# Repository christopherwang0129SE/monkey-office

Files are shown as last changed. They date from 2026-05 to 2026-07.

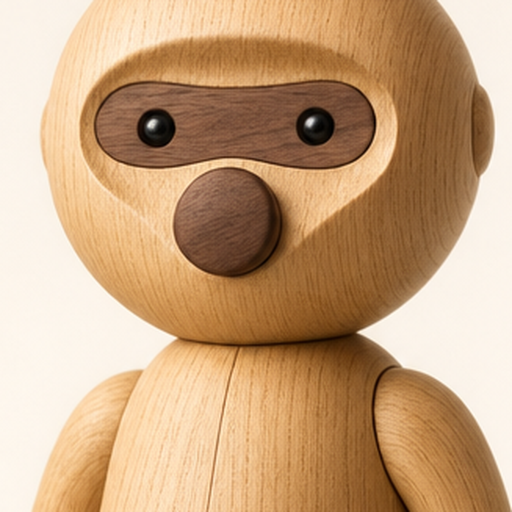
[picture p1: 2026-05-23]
3d Model officemonkey.dk/design/renders/website-assets/monkey-chat.png

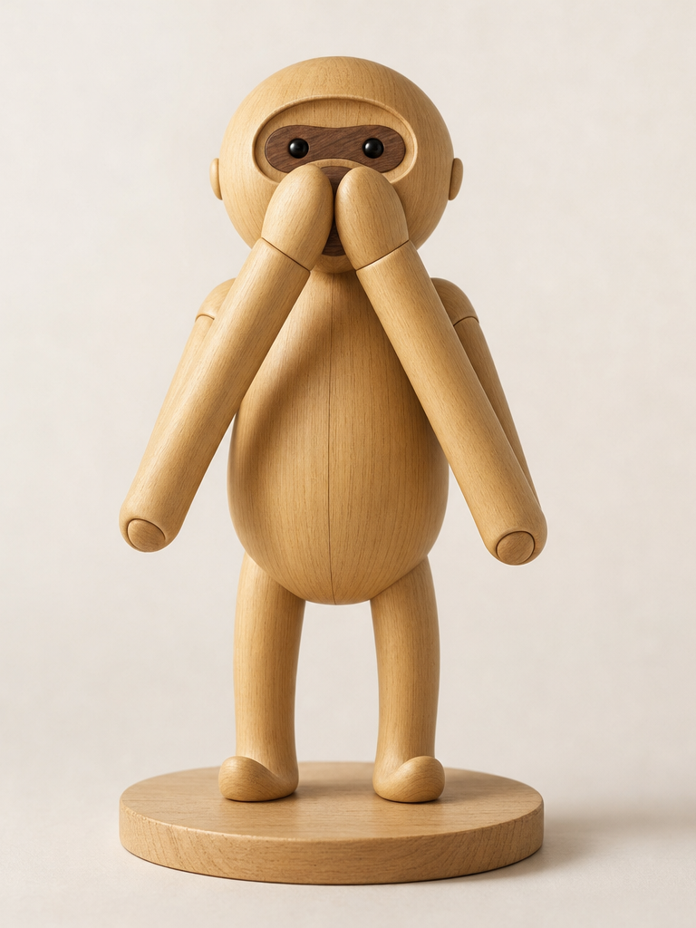
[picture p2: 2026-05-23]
3d Model officemonkey.dk/design/renders/website-assets/monkey-hero.png

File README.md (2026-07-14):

# OfficeMonkey 🙈 🙉 🙊

> A 3D-printed desk monkey that listens to the room and reacts when the office gets too loud — so no one has to be the person who shushes everyone.

**Danish name:** *Tys aben* ("Hush the monkey")

🌐 [Website](https://www.officemonkey.dk) &nbsp;·&nbsp; 🎨 [Lovable project](https://lovable.dev/projects/6d5c936e-dc8c-4e85-afaa-a0ec67a89f7e) &nbsp;·&nbsp; 📄 [Product plan](./Mokey-product-plan.md)

Built by a team of five at **The Boring Hackathon 2026** — a Copenhagen hackathon organised by [Milo.AI](https://milo.ai) and [Iværksætter Netværk Denmark](https://www.facebook.com/groups/ivaerksaetternetvaerk).

---

## What it is

OfficeMonkey is a small, 3D-printed monkey that sits on a desk or shelf in an open office. Inside is an ESP32 with a digital microphone that continuously measures ambient sound level. When the noise crosses a threshold (sustained chatter, a loud meeting bleeding into the open floor), the monkey reacts — gently signalling "it's a bit loud in here" without anyone having to say it out loud.

## How it works

1. An I2S MEMS microphone (INMP441 or SPH0645) samples ambient audio.
2. The ESP32 computes a short-window RMS → smoothed dB-ish value.
3. If the level stays above a configurable threshold for a configurable duration, the monkey triggers a reaction (LEDs, sound, or servo movement — see [Roadmap](#roadmap)).
4. A cooldown period prevents re-triggering on every noise spike.

Threshold, dwell time, and cooldown are hard-coded in V1 and configurable via a small WiFi-served page in V1.1.

## The hackathon build

The Boring Hackathon 2026 gave us a fixed sprint to go from idea to something tangible. In that window we:

- Scoped the product, hardware, and V1 roadmap.
- Designed a parametric enclosure in OpenSCAD and 3D-printed a working miniature prototype.
- Built [officemonkey.dk](https://www.officemonkey.dk) as the product site, using Lovable for rapid iteration.
- Delivered a live demo and pitch at the end of the day.
- Posted a launch listing to the Iværksætter Netværk Denmark community as a first go-to-market signal.

## Repository structure

```
.
├── 3d Model officemonkey.dk/     Marketing 3D model for the website
├── Tys-aben-Print-Package/       Ready-to-print bundle of the enclosure
├── cad/                          OpenSCAD source for the enclosure
├── prints/                       Reference/finished print files
├── stl/                          Exported STL files for printing
├── Mokey-product-plan.md         V1 product plan and scope
├── PRINT.md                      Printing instructions
├── Research.md                   Background research
├── design-v1.md                  V1 design notes
├── design-critique.md            Design critique notes
└── three-wise-monkeys-website-inspiration.md
```

> Note: `Mokey-product-plan.md` has a typo in the filename (should be `Monkey-`). Worth fixing on a rename PR.

## Hardware — bill of materials

Target BOM: **under $25** per unit.

| Part | Notes | Approx cost |
| --- | --- | --- |
| ESP32 dev board (ESP32-S3 recommended) | Built-in WiFi/BT, I2S mic support, USB-C | ~$5–10 |
| I2S MEMS microphone (INMP441 or SPH0645) | Digital mic, cleaner than analog for noise-level work | ~$3 |
| Reaction output (LEDs / speaker / micro-servo) | TBD — see [Roadmap](#roadmap) | $2–10 |
| 3D-printed enclosure | PLA, printed from files in `stl/` | Filament only |
| USB-C cable + 5V supply | | ~$5 |

## Software stack

- **Firmware:** Arduino-ESP32 (C++) or ESP-IDF. MicroPython avoided for V1 — audio sampling timing is easier in C.
- **Audio sampling:** I2S DMA → RMS → smoothed dB estimate.
- **Trigger logic:** threshold + dwell + cooldown.
- **CAD:** OpenSCAD (parametric, so the enclosure can be re-generated when hardware choices change).
- **Tooling:** Python scripts for print helpers / calibration.
- **Marketing site:** Lovable (React + Vite), deployed at [officemonkey.dk](https://www.officemonkey.dk).

## Getting started

> Firmware and wiring are still in progress — this section will grow past the hackathon miniature as V1 comes together.

### Print the enclosure

1. Grab an STL from `stl/` (or open the OpenSCAD source in `cad/` if you want to tweak dimensions).
2. Slice with your printer's usual PLA profile. See [PRINT.md](./PRINT.md) for orientation and support notes.
3. Print the back panel separately so the electronics stay accessible.

### Flash the firmware

*Coming soon* — firmware code will live in a `firmware/` folder once V1 is written. See [Mokey-product-plan.md](./Mokey-product-plan.md) §4 for the intended stack.

### Configure

V1 uses hard-coded threshold/dwell/cooldown constants at the top of the firmware. V1.1 will add a WiFi config page.

## Roadmap

**V1 (in progress)**
- [ ] Breadboard prototype: ESP32 + I2S mic, dB values over serial
- [ ] Trigger logic (threshold + dwell + cooldown)
- [ ] Pick reaction hardware (LED-only recommended for V1)
- [ ] Fit electronics into enclosure, iterate on print

**V1.1**
- [ ] WiFi config page for threshold / sensitivity
- [ ] Sound and/or servo reaction on top of LEDs

**V2 (ideas)**
- [ ] Voice commands ("monkey, calibrate") on ESP32-S3
- [ ] Multi-monkey coordination across a floor
- [ ] Battery / portable operation

Explicit non-goals for V1: battery, cloud dashboard, mobile app, on-device speech recognition.

## Team

Built by a team of five at The Boring Hackathon 2026:

- [Agent360](https://github.com/Agent360dk) — hardware, product, 3D design
- [Christopher Wang](https://github.com/christopherwang0129SE)
- *…add remaining three teammates here*

## License

TBD — recommend **MIT** for the code and **Creative Commons Attribution (CC BY 4.0)** for the 3D models. Open an issue if you disagree before we commit to it.

## Links

| | |
| --- | --- |
| 🌐 Website | [www.officemonkey.dk](https://www.officemonkey.dk) |
| 🎨 Lovable | [Open in Lovable](https://lovable.dev/projects/6d5c936e-dc8c-4e85-afaa-a0ec67a89f7e) |
| 📄 Product plan | [Mokey-product-plan.md](./Mokey-product-plan.md) |
| 🎨 Design notes | [design-v1.md](./design-v1.md) · [design-critique.md](./design-critique.md) |
| 🔬 Research | [Research.md](./Research.md) |
| 🖨️ Print instructions | [PRINT.md](./PRINT.md) |

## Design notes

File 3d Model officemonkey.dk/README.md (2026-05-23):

# Office Monkey — Aben

3D-printet Bojesen-tribute-abe der lytter til kontorets støj og **dækker sin egen mund** ("Tys-aben", Iwazaru-tribute) når det bliver for højt for længe — en stille social-signal til rummet om at tale lavere.

**Status (2026-05-23):** V1.1 fuldt klar til print + samling. 17 STL'er (15 wall body + 2 hub) watertight ✓. Firmware-skellet skrevet. Komplet samlings-guide. Nul fysiske aber bygget endnu, nul betalende kunder.

---

## Hvor er hvad?

### [`product/`](product/) — forretning
| Fil | Indhold |
|---|---|
| [plan.md](product/plan.md) | Fase 1/2 plan, låst produkt-definition, åbne spørgsmål |
| [research.md](product/research.md) | Business outcome research (~25 kilder, 5 hovedtal) |
| [usps.md](product/usps.md) | 5 rangerede USP'er til pitch |
| [sales-strategy.md](product/sales-strategy.md) | 12-ugers 0-til-30-kunder plan |

### [`design/`](design/) — visuelt & industrielt
| Fil | Indhold |
|---|---|
| [brief.md](design/brief.md) | Industrial design brief (Bojesen-tribute) |
| [critique.md](design/critique.md) | Ærlig vurdering: V0.2 → generationelt design |
| [visual-overview.md](design/visual-overview.md) | Destilleret visuelt overblik (TL;DR) |
| [image-spec.md](design/image-spec.md) | GPT Image 2 prompt-kanon |

### [`hardware/`](hardware/) — print & elektronik
| Fil | Indhold |
|---|---|
| [PRINT.md](hardware/PRINT.md) | Bambu Lab print-guide, settings, BOM |
| [ASSEMBLY.md](hardware/ASSEMBLY.md) | Komplet samlings-guide trin-for-trin |
| [dev-brief.md](hardware/dev-brief.md) | Firmware/hardware dev-handoff |
| [wall-variant.md](hardware/wall-variant.md) | V1.1-wall (6-timers print) |
| [components/](hardware/components/) | Reference-STL'er for hardware-komponenter |

### [`firmware/`](firmware/) — Arduino-ESP32 sketch
| Fil | Indhold |
|---|---|
| [tys-aben.ino](firmware/tys-aben.ino) | I2S mic + servo control + state machine |
| [README.md](firmware/README.md) | Build/upload + tuning-guide |

### Tekniske assets
- [`cad/`](cad/) — OpenSCAD parametric source (`monkey.scad`, `monkey-wall.scad`, `hub.scad`)
- [`stl/`](stl/) — desktop variant STLs; [`stl/wall/`](stl/wall/) — wall variant (15 parts); [`stl/hub/`](stl/hub/) — external hub (2 parts)
- **[`stl/tys-aben-wall-complete.stl`](stl/tys-aben-wall-complete.stl)** — all 17 wall+hub parts on ONE plate, ready to slice & print
- **[`stl/tys-aben-desktop-complete.stl`](stl/tys-aben-desktop-complete.stl)** — all 13 desktop parts on ONE plate, ready to slice & print
- [`prints/`](prints/) — Bambu Studio project files (`.3mf`)
- [`design/cad-atech-prompt.md`](design/cad-atech-prompt.md) — hyper-detailed prompt for AI-CAD tools

### [`chat-notes/`](chat-notes/) — historiske chat-sessioner
- [2026-05-23-sessions.md](chat-notes/2026-05-23-sessions.md) — visual design + business research sessions

---

## Hurtigt at komme i gang

**Vil du printe + samle?**
- **Hurtigste vej:** download én komplet print-file og åbn i Bambu Studio:
  - **Wall variant (anbefalet):** [stl/tys-aben-wall-complete.stl](stl/tys-aben-wall-complete.stl) — 17 parts, ~64g, ~6h print, hænger på væg
  - **Desktop variant:** [stl/tys-aben-desktop-complete.stl](stl/tys-aben-desktop-complete.stl) — 13 parts, ~167g, ~21h print, står på rektangulær base
- Læs derefter [hardware/PRINT.md](hardware/PRINT.md) for slicer-settings + [hardware/ASSEMBLY.md](hardware/ASSEMBLY.md) for samling

**Vil du flashe firmware?** Læs [firmware/README.md](firmware/README.md), åbn [firmware/tys-aben.ino](firmware/tys-aben.ino) i Arduino IDE.

**Vil du sælge?** Læs [product/usps.md](product/usps.md) + [product/sales-strategy.md](product/sales-strategy.md).

**Vil du forstå hvordan den ser ud?** Læs [design/visual-overview.md](design/visual-overview.md).

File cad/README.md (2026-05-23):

# CAD — Aben parametric model

3D-print-ready geometry for Aben, the office noise monkey. **V0.3.**

## What's here

| File | Purpose |
|---|---|
| [`monkey.scad`](monkey.scad) | Single parametric source. Edit dimensions at the top — every part reflows. |
| [`../stl/*.stl`](../stl/) | 11 pre-exported STLs, ready for any slicer. |
| [`../stl/_assembly_front.png`](../stl/_assembly_front.png) | Front elevation render. |
| [`../stl/_assembly_side.png`](../stl/_assembly_side.png) | Side elevation. |
| [`../stl/_assembly_iso.png`](../stl/_assembly_iso.png) | 3/4 ISO view. |
| [`../stl/_triggered.png`](../stl/_triggered.png) | Triggered pose (arms raised). |

## Design philosophy

As simple as possible to print and assemble, as beautifully shaped as pure parametric geometry can be.

- **Standing pose** — Bojesen-iconic profile, long arms hanging at sides.
- **Arms at 130 mm** (59% of total height) — the signature Bojesen long-arm proportion.
- **Flowing shoulder** — torso swells outward at the shoulder via `hull()`, the arm root matches that curve. No clip-on look.
- **Organic taper** via `hull()` of spheres on every limb and the head.
- **Curved torso seam** — large cylinder cut, nearly invisible from front and back.
- **Wooden base disc** — separate part that hides USB-C and houses access; eliminates the visible back hatch.
- **Bottom hatch** on torso for servicing — invisible when standing on the base.
- **Alert rest posture** — arms hang slightly forward, suggesting "patient, watching."
- 10 cosmetic parts + 2 mechanism parts + 1 base = **13 STLs total**.

## Parts (11 STLs)

### Body (10 parts, wood-fill PLA)

| Part | Filament | Print notes |
|---|---|---|
| `head.stl` | light wood-fill | Chin-down orientation, no supports |
| `eye_board.stl` | dark wood-fill | Flat, press-fits into face recess |
| `muzzle.stl` | dark wood-fill | Flat, press-fits below eye-board |
| `torso_front.stl` | light wood-fill | Curved-seam side up, tree supports inside cavity only |
| `torso_back.stl` | light wood-fill | Same; includes ESP32 standoffs |
| `bottom_plate.stl` | light wood-fill | Magnetic access plate for torso bottom |
| `arm_left.stl` | light wood-fill | Lying flat, inner side down |
| `arm_right.stl` | light wood-fill | Mirror |
| `leg_left.stl` | light wood-fill | Standing, hip-down |
| `leg_right.stl` | light wood-fill | Mirror |
| `base_disc.stl` | wood-fill (any tone) | Flat, top-up. The "coaster" the monkey stands on |

### Mechanism (2 parts, PETG or ABS — strength matters more than aesthetics)

| Part | Filament | Print notes |
|---|---|---|
| `yoke.stl` | PETG/ABS | Small, prints flat |
| `servo_bracket.stl` | PETG/ABS | Bracket-side down, tree supports under cradle walls |

## Slicer settings

| Setting | Body parts (wood-fill) | Mechanism (PETG/ABS) |
|---|---|---|
| Layer height | 0.12 mm | 0.16 mm |
| Wall loops | 4 | 3 |
| Top/bottom | 5 / 5 | 4 / 4 |
| Infill | 15% gyroid | 30% gyroid |
| Supports | Tree, only inside torso cavities | Auto, minimal |
| Speed | ≤ 60 mm/s | 80–120 mm/s |
| Bed adhesion | brim 4 mm on torso halves | skirt |

Wood-fill PLA is abrasive — use a hardened steel nozzle if available.

## Post-processing (the quality lever)

This is where it stops looking like a print and starts looking like wood:

1. Sand: 240 → 400 → 600 grit, with layer direction.
2. Wipe clean, let dry.
3. Apply **boiled linseed oil** or **Osmo Polyx Hardwax Oil**, two thin coats, 24h between.
4. Buff with a soft cloth.

The wood fibres in the filament absorb the oil and develop a real wood patina.

## Hardware list

| Item | Qty | Notes |
|---|---|---|
| ESP32-S3 dev board (USB-C) | 1 | Mic-friendly variant preferred |
| INMP441 or SPH0645 I2S microphone | 1 | Mounted in torso top, pointing up into head neck cavity |
| SG90 micro servo | 1 | Standard 9g hobby servo |
| 6 mm black glass beads | 2 | Eyes — press-fit |
| 3 mm steel pins or M3 bolt + nylon nut | 2 | Shoulder pivots |
| 2 mm braided fishing line | ~60 cm | Tendons |
| Light return spring or 2 mm sewing elastic | ~20 cm | Arm return |
| 5×2 mm neodymium magnets | 4 | Back hatch retention |
| USB-C breakout board | 1 | Bottom-rear of torso |

## Assembly

1. Press black glass beads into both eye holes on `eye_board`.
2. Press `eye_board` and `muzzle` into the face recess on `head`. CA glue if loose.
3. Glue `torso_front` to `torso_back` along the curved seam (medium CA or two-part epoxy on the rim).
4. Mount the SG90 into `servo_bracket`; glue/screw the bracket inside the front torso cavity.
5. Press `yoke` onto the servo horn.
6. Run fishing line from yoke arm → up through torso → out the shoulder pin hole → into the arm tendon channel → tie inside the upper arm knot pocket. Repeat for the other side.
7. Insert 3 mm shoulder pins through `torso` and the base of each `arm`.
8. Stretch a light return spring or elastic band across the chest, looped through both arm bases.
9. Press leg hip-pegs into the leg sockets on the torso bottom; glue.
10. Press `head` onto the torso neck socket (friction fit; CA glue for permanence).
11. Mount the ESP32-S3 on the standoffs inside the back torso through the bottom hatch opening.
12. Insert mic at the top of the torso cavity, pointing up into the neck.
13. Press 4× 5×2 mm neodymium magnets into the `bottom_plate` pockets and into the torso. Snap the bottom plate in place.
14. Route the USB-C cable down from the ESP32 through the bottom plate cutout and out through the `base_disc` USB notch.
15. Stand the monkey on the `base_disc` — feet rest in the foot recesses.

## Regenerating STLs

If you change a dimension in `monkey.scad`:

```bash
cd cad
for p in head eye_board muzzle torso_front torso_back bottom_plate \
         arm_left arm_right leg_left leg_right base_disc yoke servo_bracket; do
  openscad -o "../stl/${p}.stl" -D "part=\"${p}\"" monkey.scad
done
```

Requires OpenSCAD ≥ 2023. Apple Silicon: `brew install --cask openscad@snapshot`.

## The gesture, revised

V0.3 confirms a geometric reality: with rigid 130 mm arms (the Bojesen-correct proportion), the hands **cannot literally cover the eyes**. The hand traces a 130 mm radius circle around the shoulder pivot; the eye is only ~25 mm from the shoulder — the hand always overshoots.

Three options:

1. **Embrace the "raised hands" gesture.** When triggered, arms sweep straight up, hands above head. Reads emotionally as *"this is too much"* / *"I throw up my hands."* Honest to the use case (office got too loud), keeps the geometry simple. **Recommended for V0.3.**
2. **2-piece elastic-articulated arms** (V1.0). Upper arm + forearm joined by elastic. Servo drives the upper arm only; forearm folds passively, hand lands on the face. True Bojesen articulation, more parts, more assembly complexity.
3. **Move the shoulder pivot to head height.** Makes the gesture literally "covering eyes" possible with a short rigid arm, but breaks the silhouette completely. Don't do this.

## Known open items

- **Torso surface banding.** Visible "panels" at hull control-point heights. Fix in V0.4 by using a single smoother shape or more intermediate spheres.
- **Servo hold buzz.** Add a mechanical end-stop inside the torso so the spring takes the holding force, not the servo.
- **Cable routing through leg.** USB-C cable currently exits through the bottom plate; long-term plan is to hollow one leg and route the cable through it into the base disc, for cleaner installation.

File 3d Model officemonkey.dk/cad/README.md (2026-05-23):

# CAD — Aben parametric model

3D-print-ready geometry for Aben, the office noise monkey. **V0.3.**

## What's here

| File | Purpose |
|---|---|
| [`monkey.scad`](monkey.scad) | Single parametric source. Edit dimensions at the top — every part reflows. |
| [`../stl/*.stl`](../stl/) | 11 pre-exported STLs, ready for any slicer. |
| [`../stl/_assembly_front.png`](../stl/_assembly_front.png) | Front elevation render. |
| [`../stl/_assembly_side.png`](../stl/_assembly_side.png) | Side elevation. |
| [`../stl/_assembly_iso.png`](../stl/_assembly_iso.png) | 3/4 ISO view. |
| [`../stl/_triggered.png`](../stl/_triggered.png) | Triggered pose (arms raised). |

## Design philosophy

As simple as possible to print and assemble, as beautifully shaped as pure parametric geometry can be.

- **Standing pose** — Bojesen-iconic profile, long arms hanging at sides.
- **Arms at 130 mm** (59% of total height) — the signature Bojesen long-arm proportion.
- **Flowing shoulder** — torso swells outward at the shoulder via `hull()`, the arm root matches that curve. No clip-on look.
- **Organic taper** via `hull()` of spheres on every limb and the head.
- **Curved torso seam** — large cylinder cut, nearly invisible from front and back.
- **Wooden base disc** — separate part that hides USB-C and houses access; eliminates the visible back hatch.
- **Bottom hatch** on torso for servicing — invisible when standing on the base.
- **Alert rest posture** — arms hang slightly forward, suggesting "patient, watching."
- 10 cosmetic parts + 2 mechanism parts + 1 base = **13 STLs total**.

## Parts (11 STLs)

### Body (10 parts, wood-fill PLA)

| Part | Filament | Print notes |
|---|---|---|
| `head.stl` | light wood-fill | Chin-down orientation, no supports |
| `eye_board.stl` | dark wood-fill | Flat, press-fits into face recess |
| `muzzle.stl` | dark wood-fill | Flat, press-fits below eye-board |
| `torso_front.stl` | light wood-fill | Curved-seam side up, tree supports inside cavity only |
| `torso_back.stl` | light wood-fill | Same; includes ESP32 standoffs |
| `bottom_plate.stl` | light wood-fill | Magnetic access plate for torso bottom |
| `arm_left.stl` | light wood-fill | Lying flat, inner side down |
| `arm_right.stl` | light wood-fill | Mirror |
| `leg_left.stl` | light wood-fill | Standing, hip-down |
| `leg_right.stl` | light wood-fill | Mirror |
| `base_disc.stl` | wood-fill (any tone) | Flat, top-up. The "coaster" the monkey stands on |

### Mechanism (2 parts, PETG or ABS — strength matters more than aesthetics)

| Part | Filament | Print notes |
|---|---|---|
| `yoke.stl` | PETG/ABS | Small, prints flat |
| `servo_bracket.stl` | PETG/ABS | Bracket-side down, tree supports under cradle walls |

## Slicer settings

| Setting | Body parts (wood-fill) | Mechanism (PETG/ABS) |
|---|---|---|
| Layer height | 0.12 mm | 0.16 mm |
| Wall loops | 4 | 3 |
| Top/bottom | 5 / 5 | 4 / 4 |
| Infill | 15% gyroid | 30% gyroid |
| Supports | Tree, only inside torso cavities | Auto, minimal |
| Speed | ≤ 60 mm/s | 80–120 mm/s |
| Bed adhesion | brim 4 mm on torso halves | skirt |

Wood-fill PLA is abrasive — use a hardened steel nozzle if available.

## Post-processing (the quality lever)

This is where it stops looking like a print and starts looking like wood:

1. Sand: 240 → 400 → 600 grit, with layer direction.
2. Wipe clean, let dry.
3. Apply **boiled linseed oil** or **Osmo Polyx Hardwax Oil**, two thin coats, 24h between.
4. Buff with a soft cloth.

The wood fibres in the filament absorb the oil and develop a real wood patina.

## Hardware list

| Item | Qty | Notes |
|---|---|---|
| ESP32-S3 dev board (USB-C) | 1 | Mic-friendly variant preferred |
| INMP441 or SPH0645 I2S microphone | 1 | Mounted in torso top, pointing up into head neck cavity |
| SG90 micro servo | 1 | Standard 9g hobby servo |
| 6 mm black glass beads | 2 | Eyes — press-fit |
| 3 mm steel pins or M3 bolt + nylon nut | 2 | Shoulder pivots |
| 2 mm braided fishing line | ~60 cm | Tendons |
| Light return spring or 2 mm sewing elastic | ~20 cm | Arm return |
| 5×2 mm neodymium magnets | 4 | Back hatch retention |
| USB-C breakout board | 1 | Bottom-rear of torso |

## Assembly

1. Press black glass beads into both eye holes on `eye_board`.
2. Press `eye_board` and `muzzle` into the face recess on `head`. CA glue if loose.
3. Glue `torso_front` to `torso_back` along the curved seam (medium CA or two-part epoxy on the rim).
4. Mount the SG90 into `servo_bracket`; glue/screw the bracket inside the front torso cavity.
5. Press `yoke` onto the servo horn.
6. Run fishing line from yoke arm → up through torso → out the shoulder pin hole → into the arm tendon channel → tie inside the upper arm knot pocket. Repeat for the other side.
7. Insert 3 mm shoulder pins through `torso` and the base of each `arm`.
8. Stretch a light return spring or elastic band across the chest, looped through both arm bases.
9. Press leg hip-pegs into the leg sockets on the torso bottom; glue.
10. Press `head` onto the torso neck socket (friction fit; CA glue for permanence).
11. Mount the ESP32-S3 on the standoffs inside the back torso through the bottom hatch opening.
12. Insert mic at the top of the torso cavity, pointing up into the neck.
13. Press 4× 5×2 mm neodymium magnets into the `bottom_plate` pockets and into the torso. Snap the bottom plate in place.
14. Route the USB-C cable down from the ESP32 through the bottom plate cutout and out through the `base_disc` USB notch.
15. Stand the monkey on the `base_disc` — feet rest in the foot recesses.

## Regenerating STLs

If you change a dimension in `monkey.scad`:

```bash
cd cad
for p in head eye_board muzzle torso_front torso_back bottom_plate \
         arm_left arm_right leg_left leg_right base_disc yoke servo_bracket; do
  openscad -o "../stl/${p}.stl" -D "part=\"${p}\"" monkey.scad
done
```

Requires OpenSCAD ≥ 2023. Apple Silicon: `brew install --cask openscad@snapshot`.

## The gesture, revised

V0.3 confirmed a geometric reality: with rigid 130–135 mm arms (the Bojesen-correct proportion), the hand traces a long radius around the shoulder pivot, and the **eye** sits only ~25 mm from the shoulder — too close, the hand always overshoots.

The product gesture has therefore been redefined as **hands cupping the mouth** ("Tys-aben" / Iwazaru — *speak no evil*), not the eyes. Three reasons this is the right call, not a compromise:

1. **Geometry works.** The muzzle / mouth zone sits roughly 40–50 mm above the shoulder pivot vertically (face below the brow line), and only a few mm off the centerline horizontally. A rigid arm rotated ~75–90° from rest brings the cupped hand into that zone naturally. Far more forgiving than the eye target.
2. **Concept is stronger.** Hand-over-mouth is the universal "shh" — it's a direct social signal to the room, not a description of the monkey's own state. Hand-over-eyes / hand-over-ears say "I don't want to see / hear this"; hand-over-mouth says "you, be quiet." That's exactly the product's job.
3. **Eyes stay visible.** With hands over mouth and eyes uncovered above, the monkey maintains eye contact with the viewer during the held pose — and that's what makes the gesture *land* socially. Covered eyes would be passive; visible eyes shushing you is active.

Remaining options if the rigid-arm geometry still doesn't land cleanly on the muzzle in V1 prototyping:

- **2-piece elastic-articulated arms** (V1.0). Upper arm + forearm joined by elastic. Servo drives the upper arm only; forearm folds passively, hand lands precisely on the lower face. True Bojesen articulation, more parts, more assembly complexity. Only adopt if rigid-arm prototype lands "off-target" in a way that breaks the read.
- **Acceptance of hand-on-face-region.** If a rigid arm puts the hand on the cheek or chin instead of precisely on the muzzle, the gesture may still read as "shh" — the brain interprets cupped hands on the lower face as covering the mouth regardless of pixel-precise alignment. Test with the printed prototype before committing to 2-piece arms.

## Known open items

- **Torso surface banding.** Visible "panels" at hull control-point heights. Fix in V0.4 by using a single smoother shape or more intermediate spheres.
- **Servo hold buzz.** Add a mechanical end-stop inside the torso so the spring takes the holding force, not the servo.
- **Cable routing through leg.** USB-C cable currently exits through the bottom plate; long-term plan is to hollow one leg and route the cable through it into the base disc, for cleaner installation.

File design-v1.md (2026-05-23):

# Monkey — Industrial Design Brief (V1)

> **Codename:** *Hør-ikke-abe* ("the don't-hear monkey") — a Scandinavian-design office object that covers its eyes when the room gets too loud.

---

## 0. Design north star

Kay Bojesen's 1951 teak monkey is the reference. Bojesen's mantra was **"the line should smile"** — every curve should feel warm, never sharp or industrial. The original is 31 hand-glued parts in teak and limba, with limbs strung on an internal elastic so they can be posed by hand. Black-bead eyes, a small glued-on muzzle, no painted features.

We are **not cloning Bojesen.** This is a tribute that earns its own form by adding one thing Bojesen's never did: it *moves on its own.* The motion has to feel as warm and considered as the silhouette — anything that looks like a Halloween animatronic kills the whole object.

### Three design rules (apply to every decision below)

1. **The line should smile.** No straight edges, no sharp fillets. Every transition is a radius. If a profile looks "engineered," reshape it.
2. **Hide the machine.** No visible screws, no exposed cables, no servo horns peeking out. The seam between halves should read as an intentional joint, not an assembly artifact.
3. **Motion as gesture, not animation.** One slow, considered movement — hands rise to cover eyes over ~1.2s with an ease-in/ease-out curve. Holds for the duration of the noise event. Lowers even slower (~1.8s) as if reluctant to look. No twitching, no servo buzz, no return-to-zero snap.

---

## 1. Form & proportions

**Overall height:** 220 mm (matches Bojesen "small" at 200 mm but slightly taller to accommodate the internal mechanism without compromising silhouette).

**Stance:** Seated, legs forward and slightly apart, hands resting on thighs at idle. Seated (rather than standing) gives a stable base, hides the speaker/electronics in the lower body, and reads as a desk companion rather than a toy on a shelf.

### Proportions (head-to-toe)

| Element | Height | Notes |
|---|---|---|
| Head | 70 mm | ~32% of total — slightly oversized vs. naturalistic, in Bojesen tradition. Pure sphere with a flat-cut chin, no neck. |
| Torso | 80 mm | Barrel-shaped, widest at the chest, tapering to the hips. Houses the servo + ESP32. |
| Legs (seated) | 70 mm | Folded forward. Feet act as front anchors of the base. |
| Arm length | 110 mm | Long enough to reach eyes when raised. Two joints (shoulder + elbow), Bojesen-style visible pin joints. |

### Silhouette principles

- **Head:** A near-perfect sphere. The face is a shallow ovoid recess (~3mm deep) on the front, with three glued/printed inserts: a darker "eye-board" (horizontal lozenge) and a small round muzzle below. Eyes are two 6mm black hemispheres pressed in — true to Bojesen's black-bead eyes.
- **Ears:** Small, flush, almost vestigial — two shallow discs on the sides of the head. Bojesen's monkey reads as a monkey from the silhouette and proportions, not from cartoon ears.
- **Torso:** Egg-section, broader at the shoulders. The two halves split along a curved seam that follows the spine + belly midline, so the seam reads as a body contour, not a part line.
- **Limbs:** Cylindrical with subtle taper toward the joints, exactly like Bojesen. Each limb is a single printed piece. No surface detail — the wood-grain finish does the work.
- **Joints:** Visible pin joints at shoulder, elbow, hip, knee. **Only the shoulders are functional** (driven by the internal servo via tendons). The elbow joint is sculpted in but rigid — the arm is one piece with a "joint" detail at the elbow that exists purely for the Bojesen visual signature.

### What we deliberately reject

- Cartoon faces, painted smiles, painted nostrils.
- Visible logos, brand marks, or text on the body.
- Tail. (Bojesen's monkey has none. A tail also fights with the seated stance and the rear electronics access panel.)
- Any "tech" reveal — no visible LED, no status indicator. If we need a debug light, it lives inside the battery compartment.

---

## 2. Mechanism

### Concept: tendon-driven shoulders, single servo

A single SG90-class micro servo lives vertically inside the torso, centered on the spine axis. Its horn drives a small yoke. Two non-stretch braided fishing lines (the "tendons") run from the yoke up and out through low-friction PTFE-lined channels printed into the torso, exit at the shoulder pin axis, and terminate inside each upper arm just behind the shoulder joint.

When the servo rotates upward, both tendons shorten symmetrically, rotating both arms about the shoulder pins so the hands sweep upward and inward to cover the eyes. A pair of light return springs (or a single elastic band routed across the chest, Bojesen-style) pulls the arms back down to the resting position when the servo releases.

### Why this approach

- **One motor, perfectly symmetric** — no possibility of one arm leading the other. Cheaper and more reliable than two servos.
- **No external linkages** — the only moving thing visible from outside is the arms themselves.
- **Servo is silent at hold** — once arms are up, the servo is at the end of its travel against soft springs, not actively driving. Eliminates buzz.
- **Bojesen-honest** — the original uses internal elastic to articulate limbs. Tendons + return spring is the same principle, mechanized.
- **Failure mode is graceful** — if the servo dies or power is lost, the springs pull the arms back to the resting pose. The monkey returns to "calm."

### Motion profile (firmware-side)

- **Trigger:** ambient noise above threshold for ≥800 ms (avoids reacting to single claps).
- **Raise:** servo ramps from 0° to 90° over 1.2 s with a cosine ease (no linear motion — linear servo motion is the #1 thing that makes hobby projects feel cheap).
- **Hold:** stays covered as long as noise stays above (threshold − 6dB hysteresis), with a minimum hold of 4 s so it doesn't flicker on the edge.
- **Lower:** ramps back down over 1.8 s, also eased.
- **Cooldown:** 8 s minimum between triggers. The monkey is not a meter; it's a gentle social signal.

---

## 3. Print strategy

### Parts breakdown (target: 9 printed parts)

1. **Head** — single piece, printed upside-down (chin to bed) to put support on the flat chin cut and keep the spherical surface clean.
2. **Eye-board insert** — small, separate, printed in the darker (teak) filament. Press-fit into the face recess.
3. **Muzzle insert** — same as eye-board, darker filament.
4. **Torso front half** — split along the curved spine seam. Cavity for ESP32, mic, and servo mount. Mic port is a 3mm hole hidden behind the eye-board insert (sound travels up the neck cavity to the mic).
5. **Torso back half** — same seam. Includes a magnetically-retained access panel (~40×60 mm) at the lower back for USB-C and reset access.
6. **Left arm** — single piece, printed lying flat with the inner (body-facing) side down. Tendon channel printed in.
7. **Right arm** — mirror of left.
8. **Left leg** — single piece, posed seated.
9. **Right leg** — mirror.

### Filament & finish

- **Body / head / limbs:** light wood-fill PLA (limba reference) — e.g. ColorFabb WoodFill or Polymaker PolyWood "natural."
- **Eye-board / muzzle / hands (last 20mm of each arm):** dark wood-fill PLA (teak reference) — ColorFabb WoodFill "darker" or aged with linseed.
- **Eyes:** 6 mm black glass beads or black-painted resin hemispheres, press-fit into 5.8 mm holes in the eye-board. Real beads beat any printed approximation.

### Post-processing (this is where the Bojesen-quality bar is met or missed)

1. Print at **0.12 mm layer height** for body and head, 0.16 mm acceptable for limbs.
2. Sand progressively: 240 → 400 → 600 grit. Wood-fill PLA sands beautifully and exposes more wood fiber.
3. Apply **food-safe boiled linseed oil** (or Osmo Polyx) with a lint-free cloth. Two coats, 24h apart. This is the single biggest jump in perceived quality — it transforms wood-fill PLA from "3D print" to "actual wood object."
4. Buff with a soft cloth between coats.

### Print orientation cheat sheet

| Part | Orientation | Supports |
|---|---|---|
| Head | Chin down | None (sphere prints clean from a small flat) |
| Torso halves | Seam side down | Tree supports inside cavity only |
| Arms | Inner side down | None |
| Legs | Inner side down | None |
| Eye-board / muzzle | Flat face down | None |

---

## 4. Internal layout (torso cavity)

```
       ┌─── neck cavity (mic sound path) ───┐
       │                                    │
   ┌───┴────────────────────────────────────┴───┐
   │  [I2S mic, pointed up neck]                │  ← chest level
   │  [ESP32-S3 dev board, vertical, USB down]  │
   │  ┌──────────────────────────────────────┐  │
   │  │           SG90 servo                 │  │  ← center
   │  │  (shaft vertical, yoke at top)       │  │
   │  └──────────────────────────────────────┘  │
   │  [tendon yoke] ─→ tendons up to shoulders  │
   │                                            │
   │  [USB-C breakout, accessible via back hatch]│  ← hip level
   └─────────────────────────────────────────────┘
```

- Mic at the top of the cavity, pointed up the neck — the neck channel acts as a short waveguide, and the eye-board hole on the face is the actual sound port. Hides the mic completely while keeping it acoustically open.
- ESP32 mounted vertically against the inside of the torso back half.
- Servo cradled in printed-in ribs in the front half.
- All wiring runs along channels in the back half; no loose cables.

---

## 5. The "Scandi quality" checklist

Before signing off any prototype, it must pass all of these:

- [ ] **Silhouette test:** photograph as black silhouette against white. Should be unmistakably a monkey, unmistakably Bojesen-adjacent, with no part lines visible.
- [ ] **Hand-feel test:** pick it up. The weight should feel right (target ~250 g — heavy enough to feel solid, light enough to handle). Edges should be sanded to where no seam is felt with closed eyes.
- [ ] **Idle test:** sit it on a desk for an hour while powered on. It should be completely silent. No fan noise, no servo hum, no LED visible.
- [ ] **Gesture test:** trigger it ten times. Every motion should feel identical, slow, and intentional. Anyone watching should say "oh, it's covering its eyes," not "oh, a robot moved."
- [ ] **Aged-friend test:** hand it to someone who doesn't know what it does. They should want to pick it up. If their first reaction is "what does it do?" instead of "oh, hello" — the form has failed.

---

## 6. Out of scope for the ID work (kept simple on purpose)

- Battery / charging dock — V1 is USB-C powered, full stop.
- Tail, fingers, separated thumb — Bojesen had none of these; we won't either.
- Multiple SKUs / sizes — single 220 mm size for V1.
- Custom PCB — V1 uses off-the-shelf ESP32-S3 dev board.
- Painted finishes — wood-fill + oil only. If we want color in V2, we'll do dyed oil, not paint.

---

## 7. Open questions for the next iteration

- **Spring vs. elastic return:** two coil springs (cleaner force curve) vs. one woven elastic band routed Bojesen-style across the chest behind the arms (more honest tribute). Need a physical prototype to decide.
- **Eye-board geometry:** horizontal lozenge (Bojesen) vs. a softer rounded rectangle. Bojesen wins on tribute, but the rounded version may print cleaner.
- **Hand shape:** Bojesen's hands are simple cylindrical stubs. Should we leave them as stubs (honest), or sculpt a shallow palm-cup so they nest over the eye-board when raised? The cup is more "expressive" but starts to feel cartoonish.
- **Sound:** speaker yes/no in V1.1? If yes, where does the grille go without breaking the silhouette? (Candidate: hidden in the seated-pose space between the thighs, firing downward into the desk for a soft diffused sound.)

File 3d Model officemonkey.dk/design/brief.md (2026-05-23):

# Monkey — Industrial Design Brief (V1)

> **Codename:** *Tys-aben* ("the shush monkey") — a Scandinavian-design office object that covers its own mouth when the room gets too loud. Iwazaru ("speak no evil") adapted as a silent social signal: when the monkey shushes itself, it's telling the room to do the same.

---

## 0. Design north star

Kay Bojesen's 1951 teak monkey is the reference. Bojesen's mantra was **"the line should smile"** — every curve should feel warm, never sharp or industrial. The original is 31 hand-glued parts in teak and limba, with limbs strung on an internal elastic so they can be posed by hand. Black-bead eyes, a small glued-on muzzle, no painted features.

We are **not cloning Bojesen.** This is a tribute that earns its own form by adding one thing Bojesen's never did: it *moves on its own.* The motion has to feel as warm and considered as the silhouette — anything that looks like a Halloween animatronic kills the whole object.

### Three design rules (apply to every decision below)

1. **The line should smile.** No straight edges, no sharp fillets. Every transition is a radius. If a profile looks "engineered," reshape it.
2. **Hide the machine.** No visible screws, no exposed cables, no servo horns peeking out. The seam between halves should read as an intentional joint, not an assembly artifact.
3. **Motion as gesture, not animation.** One slow, considered movement — hands rise to cup the mouth over ~1.2s with an ease-in/ease-out curve. The eyes remain visible above the cupped hands — eye-contact is preserved throughout, which is what makes the "shh" land. Holds for the duration of the noise event. Lowers even slower (~1.8s) as if reluctant to release. No twitching, no servo buzz, no return-to-zero snap.

---

## 1. Form & proportions

**Overall height:** 220 mm (matches Bojesen "small" at 200 mm but slightly taller to accommodate the internal mechanism without compromising silhouette).

**Stance:** Seated, legs forward and slightly apart, hands resting on thighs at idle. Seated (rather than standing) gives a stable base, hides the speaker/electronics in the lower body, and reads as a desk companion rather than a toy on a shelf.

### Proportions (head-to-toe)

| Element | Height | Notes |
|---|---|---|
| Head | 70 mm | ~32% of total — slightly oversized vs. naturalistic, in Bojesen tradition. Pure sphere with a flat-cut chin, no neck. |
| Torso | 80 mm | Barrel-shaped, widest at the chest, tapering to the hips. Houses the servo + ESP32. |
| Legs (seated) | 70 mm | Folded forward. Feet act as front anchors of the base. |
| Arm length | 135 mm (~60% of total height) | Bojesen-signature long arms — easily reach the mouth when raised (shorter travel than reaching the eyes, so kinematics is forgiving). Two joints (shoulder + elbow), Bojesen-style visible pin joints. |

### Silhouette principles

- **Head:** A near-perfect sphere. The face is a shallow ovoid recess (~3mm deep) on the front, with three glued/printed inserts: a darker "eye-board" (horizontal lozenge) and a small round muzzle below. Eyes are two 6mm black hemispheres pressed in — true to Bojesen's black-bead eyes.
- **Ears:** Small, flush, almost vestigial — two shallow discs on the sides of the head. Bojesen's monkey reads as a monkey from the silhouette and proportions, not from cartoon ears.
- **Torso:** Egg-section, broader at the shoulders. The two halves split along a curved seam that follows the spine + belly midline, so the seam reads as a body contour, not a part line.
- **Limbs:** Cylindrical with subtle taper toward the joints, exactly like Bojesen. Each limb is a single printed piece. No surface detail — the wood-grain finish does the work.
- **Joints:** Visible pin joints at shoulder, elbow, hip, knee. **Only the shoulders are functional** (driven by the internal servo via tendons). The elbow joint is sculpted in but rigid — the arm is one piece with a "joint" detail at the elbow that exists purely for the Bojesen visual signature.

### What we deliberately reject

- Cartoon faces, painted smiles, painted nostrils.
- Visible logos, brand marks, or text on the body.
- Tail. (Bojesen's monkey has none. A tail also fights with the seated stance and the rear electronics access panel.)
- Any "tech" reveal — no visible LED, no status indicator. If we need a debug light, it lives inside the battery compartment.

---

## 2. Mechanism

### Concept: tendon-driven shoulders, single servo

A single SG90-class micro servo lives vertically inside the torso, centered on the spine axis. Its horn drives a small yoke. Two non-stretch braided fishing lines (the "tendons") run from the yoke up and out through low-friction PTFE-lined channels printed into the torso, exit at the shoulder pin axis, and terminate inside each upper arm just behind the shoulder joint.

When the servo rotates upward, both tendons shorten symmetrically, rotating both arms about the shoulder pins so the hands sweep upward and inward to cup the mouth (the walnut muzzle area). The travel is shorter than reaching the eyes would be, which means less tendon tension, less servo strain, and a more reliable hold at peak. A pair of light return springs (or a single elastic band routed across the chest, Bojesen-style) pulls the arms back down to the resting position when the servo releases.

### Why this approach

- **One motor, perfectly symmetric** — no possibility of one arm leading the other. Cheaper and more reliable than two servos.
- **No external linkages** — the only moving thing visible from outside is the arms themselves.
- **Servo is silent at hold** — once arms are up, the servo is at the end of its travel against soft springs, not actively driving. Eliminates buzz.
- **Bojesen-honest** — the original uses internal elastic to articulate limbs. Tendons + return spring is the same principle, mechanized.
- **Failure mode is graceful** — if the servo dies or power is lost, the springs pull the arms back to the resting pose. The monkey returns to "calm."

### Motion profile (firmware-side)

- **Trigger:** ambient noise above threshold for ≥800 ms (avoids reacting to single claps).
- **Raise:** servo ramps from 0° to 90° over 1.2 s with a cosine ease (no linear motion — linear servo motion is the #1 thing that makes hobby projects feel cheap).
- **Hold:** stays covered as long as noise stays above (threshold − 6dB hysteresis), with a minimum hold of 4 s so it doesn't flicker on the edge.
- **Lower:** ramps back down over 1.8 s, also eased.
- **Cooldown:** 8 s minimum between triggers. The monkey is not a meter; it's a gentle social signal.

---

## 3. Print strategy

### Parts breakdown (target: 9 printed parts)

1. **Head** — single piece, printed upside-down (chin to bed) to put support on the flat chin cut and keep the spherical surface clean.
2. **Eye-board insert** — small, separate, printed in the darker (teak) filament. Press-fit into the face recess.
3. **Muzzle insert** — same as eye-board, darker filament.
4. **Torso front half** — split along the curved spine seam. Cavity for ESP32, mic, and servo mount. Mic port is a 3mm hole hidden behind the eye-board insert (sound travels up the neck cavity to the mic).
5. **Torso back half** — same seam. Includes a magnetically-retained access panel (~40×60 mm) at the lower back for USB-C and reset access.
6. **Left arm** — single piece, printed lying flat with the inner (body-facing) side down. Tendon channel printed in.
7. **Right arm** — mirror of left.
8. **Left leg** — single piece, posed seated.
9. **Right leg** — mirror.

### Filament & finish

- **Body / head / limbs:** light wood-fill PLA (limba reference) — e.g. ColorFabb WoodFill or Polymaker PolyWood "natural."
- **Eye-board / muzzle / hands (last 20mm of each arm):** dark wood-fill PLA (teak reference) — ColorFabb WoodFill "darker" or aged with linseed.
- **Eyes:** 6 mm black glass beads or black-painted resin hemispheres, press-fit into 5.8 mm holes in the eye-board. Real beads beat any printed approximation.

### Post-processing (this is where the Bojesen-quality bar is met or missed)

1. Print at **0.12 mm layer height** for body and head, 0.16 mm acceptable for limbs.
2. Sand progressively: 240 → 400 → 600 grit. Wood-fill PLA sands beautifully and exposes more wood fiber.
3. Apply **food-safe boiled linseed oil** (or Osmo Polyx) with a lint-free cloth. Two coats, 24h apart. This is the single biggest jump in perceived quality — it transforms wood-fill PLA from "3D print" to "actual wood object."
4. Buff with a soft cloth between coats.

### Print orientation cheat sheet

| Part | Orientation | Supports |
|---|---|---|
| Head | Chin down | None (sphere prints clean from a small flat) |
| Torso halves | Seam side down | Tree supports inside cavity only |
| Arms | Inner side down | None |
| Legs | Inner side down | None |
| Eye-board / muzzle | Flat face down | None |

---

## 4. Internal layout (torso cavity)

```
       ┌─── neck cavity (mic sound path) ───┐
       │                                    │
   ┌───┴────────────────────────────────────┴───┐
   │  [I2S mic, pointed up neck]                │  ← chest level
   │  [ESP32-S3 dev board, vertical, USB down]  │
   │  ┌──────────────────────────────────────┐  │
   │  │           SG90 servo                 │  │  ← center
   │  │  (shaft vertical, yoke at top)       │  │
   │  └──────────────────────────────────────┘  │
   │  [tendon yoke] ─→ tendons up to shoulders  │
   │                                            │
   │  [USB-C breakout, accessible via back hatch]│  ← hip level
   └─────────────────────────────────────────────┘
```

- Mic at the top of the cavity, pointed up the neck — the neck channel acts as a short waveguide, and the eye-board hole on the face is the actual sound port. Hides the mic completely while keeping it acoustically open.
- ESP32 mounted vertically against the inside of the torso back half.
- Servo cradled in printed-in ribs in the front half.
- All wiring runs along channels in the back half; no loose cables.

---

## 5. The "Scandi quality" checklist

Before signing off any prototype, it must pass all of these:

- [ ] **Silhouette test:** photograph as black silhouette against white. Should be unmistakably a monkey, unmistakably Bojesen-adjacent, with no part lines visible.
- [ ] **Hand-feel test:** pick it up. The weight should feel right (target ~250 g — heavy enough to feel solid, light enough to handle). Edges should be sanded to where no seam is felt with closed eyes.
- [ ] **Idle test:** sit it on a desk for an hour while powered on. It should be completely silent. No fan noise, no servo hum, no LED visible.
- [ ] **Gesture test:** trigger it ten times. Every motion should feel identical, slow, and intentional. Anyone watching should say "oh, it's shushing us," not "oh, a robot moved." The eyes should remain fixed on the viewer during the held pose — that's the social-signal moment.
- [ ] **Aged-friend test:** hand it to someone who doesn't know what it does. They should want to pick it up. If their first reaction is "what does it do?" instead of "oh, hello" — the form has failed.

---

## 6. Out of scope for the ID work (kept simple on purpose)

- Battery / charging dock — V1 is USB-C powered, full stop.
- Tail, fingers, separated thumb — Bojesen had none of these; we won't either.
- Multiple SKUs / sizes — single 220 mm size for V1.
- Custom PCB — V1 uses off-the-shelf ESP32-S3 dev board.
- Painted finishes — wood-fill + oil only. If we want color in V2, we'll do dyed oil, not paint.

---

## 7. Open questions for the next iteration

- **Spring vs. elastic return:** two coil springs (cleaner force curve) vs. one woven elastic band routed Bojesen-style across the chest behind the arms (more honest tribute). Need a physical prototype to decide.
- **Eye-board geometry:** horizontal lozenge (Bojesen) vs. a softer rounded rectangle. Bojesen wins on tribute, but the rounded version may print cleaner.
- **Hand shape:** Bojesen's hands are simple cylindrical stubs. Should we leave them as stubs (honest), or sculpt a shallow palm-cup so they nest gently over the muzzle when raised? The cup is more "expressive" but starts to feel cartoonish. Working assumption: shallow palm-cup with inward wrist tilt — locked in [image-spec.md](image-spec.md).
- **Sound:** speaker yes/no in V1.1? If yes, where does the grille go without breaking the silhouette? (Candidate: hidden in the seated-pose space between the thighs, firing downward into the desk for a soft diffused sound.)

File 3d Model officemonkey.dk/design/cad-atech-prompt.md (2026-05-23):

# cad.atech.dev — Tys-aben prompt

> Paste-ready prompt for generating the full 3D-printable Tys-aben (Wall variant, V1.1) including the external hardware hub. English, hyper-specified, includes every locked design decision from our iteration.

---

## The prompt

```
DESIGN A 3D-PRINTABLE MECHANICAL WOODEN MONKEY FIGURINE — "TYS-ABEN"

Project: A small, wall-mounted, 3D-printed wooden monkey figurine in
the tradition of Kay Bojesen's 1951 teak monkey. It contains a
microcontroller, an I2S microphone, and a servo. When the ambient
noise in an office exceeds a configurable threshold, the servo
actuates two-piece articulated arms via internal tendons so that the
monkey's two hands cup gently over its own mouth — an Iwazaru
("speak no evil") gesture adapted as a silent social signal: the
monkey is silently telling the room to be quiet. Eye contact with
the viewer is preserved throughout the gesture (eyes remain visible
above the cupped hands).

Generate FDM-printable STL geometry for every part listed below.
All parts must be MANIFOLD AND WATERTIGHT. Units: millimetres.

==============================================================
PART 1 — THE MONKEY (WALL VARIANT V1.1)
==============================================================
Total height when mounted: 125 mm (legs dangling).
Mounting: a keyhole slot on the back of the torso for a single
screw head (8 mm diameter circular hole transitioning into a
2.8 mm × 10 mm vertical slot, recessed so the screw head sits
flush inside the body, located 25% up from torso center on the
back face).

OVERALL FORM AND PROPORTIONS
- Head: a near-perfect sphere, 38 mm wide × 37 mm deep × 44 mm tall,
  with a softly rounded chin plane (NOT flat-cut). No neck. Two
  flush vestigial ear-discs (~9 mm diameter) on the sides, barely
  perceptible from the front.
- Torso: egg-shaped, broadest at the shoulders and tapering to the
  hips. External dimensions 38 × 28 × 52 mm. Two front/back halves
  split along a curved seam following the spine-and-belly midline
  (seam radius approximately 120 mm so the seam reads as a body
  contour, not an assembly line).
- Shoulders: flow into the torso as one continuous form — the torso
  swells outward and the arm grows from it. NO right-angle clip-on
  shoulder. Use hull operations to blend the shoulder ball into the
  torso ovoid.
- Arms: TWO-PIECE per side (see PART 1B below). Total arm length
  approximately 75 mm; upper arm and forearm are each ~37 mm long.
- Legs: dangling passively from the hip sockets. Each leg is
  ~55 mm long, 15 mm wide at the foot, 13 mm at the knee. Feet are
  slightly toed-out (~10°). Toe tips lift forward-and-slightly-up
  like slipper toes.
- At-rest posture: arms hang fully along the sides with a 5° forward
  inclination of the upper arm at the shoulder (alert, not relaxed).
  Eyes always forward, attentive.

FACE
- A shallow ovoid recess on the front of the head, 3 mm deep.
- An eye-board insert: a horizontal lozenge 22 mm wide × 8 mm tall,
  2.8 mm thick, with a faint downward bow at center (smile-line),
  press-fit into the upper half of the face recess. Printed
  separately in a contrasting darker wood-tone filament.
- A muzzle insert: a small round disc 8.5 mm diameter, 2.5 mm
  thick, press-fit just below the eye-board in the lower half of
  the face recess. Same darker wood tone.
- Two black glass bead eyes (6 mm diameter) press-fit into 5.8 mm
  holes in the eye-board with 11 mm spacing center-to-center.
- A subtle brow ridge above the eye-board and shallow cheek planes
  flanking the muzzle. These give the face skeletal structure even
  before the inserts are placed.
- NO mouth, NO nostrils, NO painted features.

PART 1A — TORSO INTERIOR (HOLLOW CAVITY FOR ELECTRONICS)
Internal cavity must accommodate the following hardware, with the
listed clearances:
- SG90 micro servo: external body 23 × 12.5 × 22.5 mm. Mounts
  centered in the torso with the output shaft pointing up. Held by
  a printed cradle (servo_bracket) that snaps into the torso.
- I2S microphone board: 39.5 × 10.8 × 19.5 mm. Mounted vertically
  in the upper torso so the mic capsule points up into the neck
  cavity (acoustic waveguide). The eye-board insert hides a small
  sound port from the outside.
- Tendon channels: two parallel internal channels, 2.0 mm
  diameter, running from the servo yoke up through the torso and
  exiting at each shoulder pin axis. PTFE-lining slot 2.4 mm
  diameter for low-friction tendon routing.
- Shoulder pin holes: 2.5 mm diameter through-holes at the top of
  the torso, one at each side, into which a 3 mm steel pin
  inserts to hold the upper arm.
- Bottom plate: 24 × 20 × 2 mm rounded rectangle with a 14 × 8 mm
  cable cutout for the wire bundle exiting the torso going down to
  the external hub. Retained by a single 5 mm magnet in a 5.2 × 2.2
  mm pocket.
- Internal wall thickness: 2.0 mm uniform.

PART 1B — TWO-PIECE ARTICULATED ARM (THE KEY MECHANISM)
Each arm consists of:
- upper_arm (left + right): 37 mm long, tapered from 14 mm
  diameter at the shoulder ball, swelling to 15 mm in the upper
  bicep, then tapering to 12 mm near the elbow knuckle. Contains:
    • A 2.5 mm transverse shoulder pin hole at the proximal end.
    • A 2.2 mm transverse elbow pin hole at the distal end.
    • A 2.0 mm tendon channel running the length of the limb,
      offset slightly toward the body side, EXITING THE FRONT-FACE
      of the elbow knuckle so the same tendon can cross the joint
      into the forearm.
    • A small clearance slot on the front face of the elbow so the
      forearm's top sphere has room to fold against the upper arm
      without binding (~16 × 8 × 6 mm relief).
- forearm (left + right): 37 mm long, tapered from 13 mm at the
  elbow knuckle to 10 mm in the middle, to 9 mm at the wrist, with
  a 14 mm sphere at the hand end that has a subtle inward
  concave dip on the palm-facing side (a "wooden mitten" shape —
  NOT a claw, NOT a pointed shape, NOT separated fingers).
  Contains:
    • A 2.2 mm transverse elbow pin hole at the proximal end.
    • A 2.0 mm tendon channel ENTERING the elbow knuckle on the
      front-back face (mating with the upper arm's exit), running
      ~55% of the forearm length, terminating in a small 3.5 mm
      knot pocket where the fishing-line tendon is tied off.
- Mechanism: a 2 mm steel pin (15 mm length, typical music wire or
  bent paperclip) joins upper_arm and forearm at the elbow. The
  same single tendon passes through the upper arm, exits the front
  of the elbow, re-enters the forearm, and terminates inside the
  forearm. When the servo retracts the tendon:
    1. The upper arm rotates ~75° forward about the shoulder pin.
    2. The tendon continues to shorten across the elbow, pulling
       the forearm to fold ~90° forward relative to the upper arm.
    3. Both rotations happen simultaneously, bringing the hand
       through an arc that lands the palm-cup at MUZZLE LEVEL,
       approximately 15 mm forward of the shoulder pin and 18 mm
       above it — covering the lower half of the face. The eyes
       (eye-board, glass beads) REMAIN FULLY VISIBLE ABOVE THE
       CUPPED HANDS.

PART 1C — YOKE
A small printed part that mounts on the servo horn (5 mm shaft
hole). Has two horizontal arms with 4 mm diameter holes 10 mm
apart from the center, each carrying one tendon termination knot.

PART 1D — SERVO BRACKET
A printed cradle that holds the SG90 servo body firmly inside the
torso. External dimensions ~22 × 31 × 25 mm. Snaps into printed
ribs inside the torso front half. Provides a flat top surface for
the servo's mounting tabs and a circular bore for the output shaft.

==============================================================
PART 2 — EXTERNAL HARDWARE HUB
==============================================================
A separate matching wooden enclosure that houses the larger
hardware that cannot fit inside the monkey itself. Designed to be
wall-mounted directly below the monkey or to sit on the desk
behind it.

EXTERIOR
- Overall: 70 × 145 × 24 mm rectangular prism with rounded vertical
  corners (corner radius 6 mm).
- Same wood-fill PLA finish as the monkey itself — reads as a
  deliberately matching object, not a random brick.
- Two 4.5 mm through-holes on the back wall for wall-mounting
  screws, 24 mm apart vertically, centered horizontally.

INTERIOR (65 × 140 × 21.5 mm cavity, 2.5 mm wall thickness)
Must accommodate:
- A motherboard 60 × 7 × 120 mm lying flat on the floor of the
  cavity. Held in place by four printed pegs at the corners
  (4 mm diameter, 4 mm tall) that act as positional locators.
- A USB-C breakout (19.5 × 10.2 × 19.8 mm) soldered into the rear
  wall. The hub has a 20.5 × 11.5 mm rounded cutout in the rear
  wall for the USB-C port to be accessible from outside.
- A cable inlet on the TOP rear edge (14 × 8 mm rounded cutout)
  through which the wire bundle from the monkey enters: USB-C
  power up to the monkey, mic data lines down to the motherboard,
  servo control wires.

LID
- A separate 70 × 145 × 5 mm top lid with a 2 mm step that drops
  into the cavity opening.
- Four 5.2 mm diameter × 2.6 mm deep magnet pockets in each corner
  on both the lid (underside) and the box top rim, so the lid
  snaps shut magnetically. Four 5 × 2 mm neodymium magnets total.

==============================================================
COMMON CONSTRAINTS — ALL PARTS
==============================================================
PRINTING
- FDM 3D printing on a Bambu Lab or Prusa-class printer.
- 0.4 mm hardened-steel nozzle (wood-fill PLA is abrasive).
- 0.12 mm layer height for body, head, limbs; 0.16 mm acceptable
  for base and brackets.
- 4 walls minimum; 15 % gyroid infill.
- Max print speed for wood-fill PLA: 60 mm/s outer wall.
- No part should require excessive supports — design with FDM
  printability in mind (overhangs ≤ 45° where possible).
- Each printable part must be a separate STL file.

MATERIAL & FINISH
- Body, head, limbs, base: light birch-toned wood-fill PLA, satin
  oiled finish (boiled linseed oil), warm honey hue, visible
  vertical grain.
- Eye-board insert + muzzle insert: darker walnut-toned wood-fill
  PLA.
- Yoke and servo bracket: PETG black (mechanical strength) or
  same PLA at this small size.
- Hub: same light or medium wood-fill PLA as monkey body.

THE LINE SHOULD SMILE (Bojesen design rule)
At every transition — chin, shoulder, elbow, foot tip, eye-board
edges — the curve should arc subtly UPWARD relative to a viewer
holding the object. No sharp fillets. No right angles. Every
transition is a radius. This is THE rule that separates a competent
3D-printed figurine from a generational-quality designed object.

NEVER VISIBLE (anywhere on the assembled product)
- No visible screws on any external surface of the monkey body.
- No visible USB-C port on the monkey (USB-C is on the HUB, not
  the monkey).
- No LEDs.
- No exposed cables.
- No servo horn peeking out.
- No painted features, no cartoon eyes, no mouth, no nostrils.
- No separated fingers, no tail.
- No brand marks, no logos, no text.
- No assembly seams beyond the natural torso front/back midline.

==============================================================
DELIVERABLES (STL FILES)
==============================================================
Monkey (Wall V1.1):
   1. head.stl
   2. eye_board.stl
   3. muzzle.stl
   4. torso_front.stl
   5. torso_back.stl
   6. bottom_plate.stl
   7. upper_arm_left.stl
   8. upper_arm_right.stl
   9. forearm_left.stl
  10. forearm_right.stl
  11. leg_left.stl
  12. leg_right.stl
  13. yoke.stl
  14. servo_bracket.stl

External Hub:
  15. hub_box.stl
  16. hub_lid.stl

All 16 STL files must be manifold, watertight, and ready for
direct slicing in Bambu Studio / PrusaSlicer. Target total
filament: ~58 g across all parts. Target total print time on a
Bambu X1C: ~6 hours.

==============================================================
THE GESTURE — VISUAL TARGET
==============================================================
The single image that pitches this product: the monkey is caught
mid-gesture with both hands cupped gently over its own mouth
(over the walnut muzzle insert), covering the entire lower half of
the face from just below the eye-board down to the chin. The eyes
remain fully visible ABOVE the cupped hands. Elbows are held
slightly forward of the shoulders, never flared out sideways. The
pose reads with calm dignity, never cartoonish. The hands meet
softly at the center of the face — a wordless "shh."

The static design at rest must visibly anticipate this motion:
arms hang slightly forward of the body (5° forward of hip line),
hands' palm-cups subtly angled inward toward the body, eyes
attentive. The form is "patient, watching, ready."

This is not a toy. This is a designed object.
```

---

## Usage notes

1. Copy the entire fenced block above and paste into cad.atech.dev.
2. If the tool offers a reference image input, also upload [renders/frame-4-peak-20260523-144536.png](renders/frame-4-peak-20260523-144536.png) — that's the validated visual target.
3. The tool may return individual STLs or a single GLB — both work for slicing. If GLB, convert to STL via [renders/mesh.py](renders/mesh.py) or Blender.
4. Drop the resulting STLs into [`stl/wall/`](../stl/wall/) and [`stl/hub/`](../stl/hub/) to replace the existing OpenSCAD-generated ones if cad.atech.dev produces better geometry.

## Reference image

[frame-4-peak-20260523-144536.png](renders/frame-4-peak-20260523-144536.png) — the approved hand-over-mouth peak pose. Upload this as visual reference if cad.atech.dev supports image conditioning.

## Existing CAD as fallback

If cad.atech.dev results are weaker than the OpenSCAD baseline:
- [../cad/monkey-wall.scad](../cad/monkey-wall.scad) — full parametric source
- [../cad/hub.scad](../cad/hub.scad) — hub source
- Both already produce 16 watertight STLs ready for print

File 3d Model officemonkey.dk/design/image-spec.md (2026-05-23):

# Image-spec — Aben

> Komplet specifikation til GPT Image 2 (gpt-image-1). Mål: én låst visuel kanon vi kan generere konsistent som **pitch-animation** og **CAD-reference**, før vi laver 3D-modellen.

---

## Sådan bruges filen

1. Hver prompt nedenfor er **paste-ready** — kopier hele blokken (inkl. Master DNA) ind i GPT Image 2.
2. Generér **Hero** først. Det låser udseendet.
3. Brug Hero som **image-reference** (drag & drop) i alle efterfølgende prompter for at maksimere objekt-konsistens.
4. Format: kvadrat 1024×1024 til Hero og story arc. Til CAD-reference views (front/side/back/top): brug også kvadrat, eller 16:9 hvis modellen tillader.
5. Når en variant rammer perfekt, opdater Master DNA hvis detaljen blev finpudset.

---

## Master DNA

Den her tekst skal være IDENTISK i hver prompt. Det er det som binder serien sammen som ét objekt.

```
SUBJECT
A small wooden monkey figurine, 22 cm tall, photographed as a fine
Scandinavian product object in the tradition of Kay Bojesen's 1951
teak monkey — a fresh 2026 piece, not a replica.

MATERIAL
- Body, head, arms, legs: light birch wood, visible fine vertical
  grain, satin oiled finish, warm honey hue.
- Eye-board insert (horizontal lozenge ~32 × 12 mm, with a faint
  downward bow at center like a soft smile-line) and muzzle insert
  (small round, ~10 mm): darker walnut wood, same satin finish,
  sitting slightly proud of the face like inlay.
- Eyes: two 6 mm black glass beads, deep matte black, set into the
  eye-board with a clean soft shadow ring.
- Base disc the figure stands on: medium-tone maple, 120 mm diameter,
  10 mm thick, soft chamfered edge.
- No paint, no plastic sheen, no glossy lacquer, no print lines.

PROPORTIONS
- Head: near-perfect sphere, ~70 mm, ~32% of total height. Chin is a
  softly rounded plane (not flat-cut). No neck. Two flush vestigial
  ear-discs barely perceptible from the front.
- Face: shallow ovoid recess on the front. Walnut eye-board sits in
  the upper half, walnut muzzle sits below it. No mouth, no nostrils.
  A subtle brow ridge above the eye-board and shallow cheek planes
  flanking the muzzle give the face structure.
- Torso: egg-shaped, broadest at shoulders, tapering to hips, ~80 mm.
  Front/back seam follows the spine-and-belly midline and reads as a
  body contour, not an assembly line.
- Shoulders: flowing into the torso — the torso swells outward and
  the arm grows from it as one continuous form. No clip-on look.
- Arms: very long at 135 mm — roughly 60% of total height.
  Cylindrical with subtle taper toward the wrist. Sculptural pin
  joint visible at the shoulder; a sculpted elbow detail.
- Hands: shallow palm-cup with inward wrist tilt — palms angle
  subtly toward the body, ready to lift.
- Legs: straight, standing, ~70 mm visible. Feet slightly toed-out
  (~10°). Toe tips lift forward-and-slightly-up like slipper toes.

POSTURE & PRESENCE
- Stance: patient, watching, ready. Never slumped, never robotic.
- At rest the arms hang ~5° forward of the hip line — alert, not
  relaxed. Eyes always forward, attentive.

STYLE & LIGHT
- Scandinavian product photography. Soft northern daylight from
  upper-left. Neutral warm-white seamless paper backdrop. Single
  soft shadow pooling under the base disc. Slight film grain.
- The object reads as something a museum gift shop would sell —
  never as a 3D print, never as CGI.

THE LINE SHOULD SMILE
Every transition is a radius. No sharp fillets, no right angles.
At chin, shoulder, elbow, foot tip and eye-board: the curve arcs
subtly UPWARD relative to the viewer's gaze — the Bojesen rule,
"linjen skal smile."

NEVER VISIBLE
No screws, no USB port, no LED, no cables, no servo, no metal
fittings, no logo, no text, no painted features, no cartoon eyes,
no mouth, no nostrils, no separated fingers, no tail, no toy
aesthetic, no Halloween animatronic look, no robot.
```

---

# SECTION A — Story arc (pitch-animation)

> 5 sekventielle frames + 1 hero shot. Hver frame har SAMME kamera-position, SAMME baggrund, SAMME lyssætning, SAMME objektplacering — kun aben bevæger sig.

## Hero shot

```
[PASTE MASTER DNA HERE]

THIS SHOT — HERO
Editorial product hero. Three-quarter front view, slight rotation to
camera-left so we see depth on the right shoulder and the long right
arm. Camera at the monkey's chest height. 85 mm equivalent lens, no
distortion, shallow depth of field with the face in critical focus
and the base disc gently softened. The arms hang along the sides
at rest, hands at hip level, palm-cups subtly angled inward. Eyes
forward, attentive. The figure fills the vertical frame with
comfortable headroom; the base disc reads as a sculptural stage
beneath it. Empty warm-white backdrop. This is the catalogue cover.

ASPECT
1:1
```

## Frame 1 — Idle (the room is quiet)

```
[PASTE MASTER DNA HERE]

THIS FRAME — IDLE
The monkey stands on its base disc on a light maple desk surface,
photographed at desk-height in a tight three-quarter view. The arms
hang fully along the sides at the resting angle (~5° forward of the
hips). Hands at hip level, palm-cups angled subtly inward. Eyes
forward, attentive. Out-of-focus warm interior bokeh implies an
office in the background — no people visible. The composition is
calm and still.

NARRATIVE BEAT
The opening shot. The room is quiet. The monkey is patient.

ASPECT
1:1
```

## Frame 2 — First lift (the gesture begins)

```
[PASTE MASTER DNA HERE]

THIS FRAME — FIRST LIFT
Identical camera, identical background, identical lighting to Frame 1.
The arms have just begun to rise. Elbows are still low, close to the
torso. The forearms have rotated upward and inward by perhaps 20
degrees — hands are now at mid-chest height, palms turning to face
the lower part of the face (the muzzle / mouth area). The shoulders
show their flowing transition into the torso as the geometry shifts.
The gesture is slow and deliberate, caught at the very start of the
motion. Eyes still forward, attentive.

NARRATIVE BEAT
Something has changed in the room. The motion has begun — a quiet
"shh" is on its way.

ASPECT
1:1
```

## Frame 3 — Mid-arc (halfway to the mouth)

```
[PASTE MASTER DNA HERE]

THIS FRAME — MID-ARC
Identical camera, background, and lighting to Frames 1 and 2. The
arms are now roughly two-thirds of the way through the motion.
Elbows held slightly forward of the shoulders (not flared out
sideways). Forearms angle upward and inward; hands are at upper-
chest / lower-chin height, palm-cups clearly turning toward the
muzzle. There is a sense of considered, almost reluctant motion.
The pin joint at the shoulder is visible; the wood grain runs along
the arm.

NARRATIVE BEAT
The hands are rising toward the mouth. Slow, deliberate, warm.

ASPECT
1:1
```

## Frame 4 — Peak: hands over the mouth (the money shot)

```
[PASTE MASTER DNA HERE]

THIS FRAME — PEAK ("SHHH")
Identical camera, background, and lighting to the previous frames.
The arms have reached their peak position. Both hands are cupped
gently over the walnut muzzle insert — covering the entire lower
half of the face from just below the eye-board down to the chin.
Palm-cups pressed softly against the face. Elbows held slightly
forward of the shoulders, never flared outward.

CRUCIAL: the walnut eye-board and the two black bead eyes remain
fully visible ABOVE the cupped hands. The eyes look directly at
the viewer — attentive, gently insistent. This is the Iwazaru
"speak no evil" pose adapted for the office: the monkey is
silently telling YOU to quiet down. The eye-contact while the
mouth is covered is what makes the gesture land.

The pose reads with calm dignity, never cartoonish, never
exaggerated. The wood-grain on the arms catches the light.

NARRATIVE BEAT
The hero moment. The monkey has covered its mouth and is looking
right at you. The room receives the message.

ASPECT
1:1
```

## Frame 5 — Return (the gesture releases)

```
[PASTE MASTER DNA HERE]

THIS FRAME — RETURN
Identical camera, background, and lighting to the previous frames.
The arms have lowered back down to roughly the position of Frame 2 —
hands at mid-chest height, palms still angled inward, elbows just
beginning to straighten. The motion reads as reluctant release,
slower than the rise. Eyes still forward, attentive — they were
visible throughout. The figure is on its way back to the patient
resting pose.

NARRATIVE BEAT
The message has been delivered. The monkey returns to rest.

ASPECT
1:1
```

---

# SECTION B — CAD reference views (til 3D-model)

> Fem strict orthographic views. Til sculptor / CAD-arbejde efter pitchen. **Skal være helt rene** — ingen perspektiv, ingen baggrundselementer der konkurrerer med silhuetten.

## B1 — Front orthographic

```
[PASTE MASTER DNA HERE]

THIS VIEW — FRONT ORTHOGRAPHIC
Strict front orthographic projection. Camera dead-on at the monkey's
chest height, perfectly centered. Zero perspective distortion, zero
lens compression. The monkey stands at the resting pose (arms along
sides, ~5° forward of hips). The base disc is visible as a perfect
ellipse beneath the feet. Even, shadowless top light. Neutral warm-
white seamless backdrop. This is a measurement reference — every
proportion must be readable.

ASPECT
1:1
```

## B2 — Side profile (orthographic, camera-right)

```
[PASTE MASTER DNA HERE]

THIS VIEW — SIDE ORTHOGRAPHIC
Strict side orthographic projection from camera-right. Camera at
chest height, zero perspective. The monkey is in the resting pose.
The ~5° forward inclination of the arms should be clearly visible —
arms hang slightly in front of the hip line, not flush with the
body. The flowing shoulder-to-arm transition reads clearly in
profile, as does the toe-tip lift on the foot. Even shadowless
lighting. Neutral warm-white backdrop.

ASPECT
1:1
```

## B3 — Back orthographic

```
[PASTE MASTER DNA HERE]

THIS VIEW — BACK ORTHOGRAPHIC
Strict back orthographic projection. Camera dead-on behind the
monkey at chest height, perfectly centered. Zero perspective. The
back of the head, the spine-line seam of the torso (reading as a
body contour, not an assembly line), the back of the long arms and
legs, and the perfect ellipse of the base disc are all visible.
ABSOLUTELY NO visible access hatch, no USB cutout, no screws — the
back is a single sealed sculptural surface. Even shadowless
lighting. Neutral warm-white backdrop.

ASPECT
1:1
```

## B4 — Top-down orthographic

```
[PASTE MASTER DNA HERE]

THIS VIEW — TOP-DOWN ORTHOGRAPHIC
Strict bird's-eye orthographic projection straight down from above.
Camera centered over the head. Zero perspective. Visible from this
angle: the round top of the head, the egg-section of the torso, the
long arms hanging outside the torso line with their slight forward
inclination, the toed-out feet, and the round maple base disc
framing the whole composition. Even shadowless lighting. Neutral
warm-white backdrop.

ASPECT
1:1
```

## B5 — Three-quarter reference (perspective allowed)

```
[PASTE MASTER DNA HERE]

THIS VIEW — THREE-QUARTER REFERENCE
Three-quarter angle from front-left, camera at chest height. 50 mm
equivalent lens — gentle, faithful perspective, no wide-angle
distortion. The monkey is in the resting pose. Even, faintly directional
lighting from upper-left. Neutral warm-white seamless backdrop. The
goal is depth-reference: a sculptor should be able to use this
together with B1–B4 to rebuild the form in 3D.

ASPECT
1:1
```

---

# SECTION C — Detail shots

> Close-ups til både pitch og CAD-reference. Vis materialet, kvaliteten af kurverne, og at "the line smiles."

## C1 — Face close-up

```
[PASTE MASTER DNA HERE]

THIS SHOT — FACE MACRO
Macro shot of the face only, filling the frame. Three-quarter angle.
Show the depth of the ovoid recess on the front of the head, the
walnut eye-board sitting proud with its faint downward bow at
center, the two black glass bead eyes catching a single soft
highlight, and the small round walnut muzzle below. The subtle
brow ridge above the eye-board and the shallow cheek planes
flanking the muzzle should be readable in raking light. Skin-warm
tonal range. Very shallow depth of field.

ASPECT
1:1
```

## C2 — Hand close-up

```
[PASTE MASTER DNA HERE]

THIS SHOT — HAND MACRO
Macro shot of one hand and the lower forearm from a three-quarter
angle. Show the shallow inward palm-cup, the wrist tilt, the
cylindrical wrist-to-hand taper, the soft radius at every transition.
Birch grain visible along the length of the forearm. The hand
reads unmistakably as "designed to cup the face" — not as a sphere,
not as a club. Very shallow depth of field.

ASPECT
1:1
```

## C3 — Shoulder flow close-up

```
[PASTE MASTER DNA HERE]

THIS SHOT — SHOULDER FLOW MACRO
Macro shot of the shoulder transition from torso to arm, three-
quarter angle. Show how the torso swells outward and the arm grows
from it as one continuous flowing form — no visible joint line, no
clip-on look. The sculptural pin joint at the shoulder is purely
visual character, not mechanical. Grain runs along the arm.

ASPECT
1:1
```

## C4 — Base / material transition close-up

```
[PASTE MASTER DNA HERE]

THIS SHOT — BASE MATERIAL MACRO
Low-angle close-up of where the feet meet the base disc. Show the
slightly toed-out feet (~10°), the soft chamfered edge of the
maple disc, the tonal shift between the light birch body and the
medium-tone maple base. ABSOLUTELY NO visible USB notch, no port,
no hardware — the base reads as pure sculpture from this angle.
Single soft shadow under the disc.

ASPECT
1:1
```

---

# SECTION D — Validering

## D1 — Black silhouette iconicity test

```
[PASTE MASTER DNA HERE]

THIS SHOT — SILHOUETTE TEST
Pure black silhouette of the object against pure white background.
No texture, no shading, no inserts, no grain — just shape. The
monkey is in the resting pose. This is the iconicity test: at
thumbnail size the silhouette must read unmistakably as a Bojesen-
tribute monkey: spherical head, egg-torso, very long arms hanging
slightly forward, toed-out feet, round base disc.

ASPECT
1:1
```

---

## Låste valg 🔒

Disse er nu låst på tværs af alle 16 prompter. Skift kun ved bevidst beslutning, og opdater Master DNA hvis du gør.

- **Højde:** 220 mm
- **Pose:** stående, ikke siddende
- **Arme:** 135 mm (60% af højden), Bojesen-signaturlange
- **Arm-hvilevinkel:** ~5° foran hofteline (alert, ikke akavet)
- **Hænder:** shallow palm-cup med inward wrist tilt
- **Cover-position:** hænder kuppet over muzzle / nedre halvdel af ansigtet, palmer presset blødt mod den, albuer let frem. Eye-board og øjne forbliver synlige OVER hænderne — øjenkontakt bevares (Iwazaru "shh"-gestus, ikke see-no-evil)
- **Eye-board:** vandret lozenge ~32×12 mm med faint downward bow (smile-line)
- **Muzzle:** lille rund valnød-indsats, ~10 mm
- **Øjne:** 6 mm sorte glasperler i eye-board
- **Hage:** blødt afrundet plane (ikke fladt skåret)
- **Ear-discs:** flush, knapt synlige
- **Træ-toner:** lys birk krop, valnød eye-board + muzzle, medium ahorn base disc
- **Base disc:** 120 mm diameter, 10 mm tyk, blød chamfer
- **Skuldre:** flydende ind i torso (hull-style), ingen clip-on look
- **Fødder:** toed-out ~10°, tå-tip løfter forward-and-up
- **Seam:** følger spine-belly midline, læses som krops-kontur ikke samlingslinje
- **Brow + cheek planes:** subtile, til at give ansigt struktur uden inserts
- **Lys:** blødt nordligt dagslys fra øvre venstre
- **Baggrund:** neutral warm-white seamless
- **Skygge:** én blød samlet under base disc
- **Synlig teknologi:** ingen, ingen steder, i intet view

---

## Stadig åbne valg ❓

Disse vil image gen besvare for os — variér første gang vi genererer Hero, og lås det vinder.

- **Hand-cover-spread ved mund:** hænderne mødes tæt over muzzle (én sammenhængende cup) vs. let separerede (to tydelige cups der lige rører hinanden ved midten). Sandsynlig vinder: tæt sammen — den læser som "shh" på lang afstand.
- **Forearm-vinkel ved peak:** parallelle (begge underarme symmetriske, lige op) vs. let krydsede (højre underarm krydser foran venstre eller omvendt). Sandsynlig vinder: parallelle — symmetri understøtter den rolige Bojesen-dignitet.
- **Underansigts-dækning:** hænderne dækker præcis muzzle vs. dækker hele området fra under eye-board til hage. Sandsynlig vinder: dækker området fra under eye-board til hage — mere dækning, klarere gestus, men eye-board forbliver fuldt synligt.
- **Bokeh-baggrund i story arc:** kontor-bokeh vs. helt ren backdrop. Sandsynlig vinder: meget subtil kontor-bokeh — fortæller historien uden at distrahere.

---

## Negative prompt (paste til slut hvis modellen tager negative prompts)

```
no plastic, no shiny surface, no 3D print layer lines, no screws,
no visible electronics, no USB port, no cables, no LEDs, no servo
motor, no painted features, no cartoon eyes, no mouth, no
nostrils, no tail, no separated fingers, no toy aesthetic, no
Halloween animatronic look, no robot, no metal fittings, no
glossy lacquer, no logo, no text, no human figures in background,
no perspective distortion in orthographic views, no fish-eye lens.
```

---

## Iterations-log

> Skriv her hvad vi prøver i hver runde, og hvad vi beslutter.

| Runde | Prompt | Resultat | Beslutning |
|---|---|---|---|
| — | — | — | — |

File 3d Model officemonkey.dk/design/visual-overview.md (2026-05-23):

# Overblik — hvordan kommer aben til at se ud?

> Chat-note, 2026-05-23 (sen-eftermiddag). Følger op på den tidligere [`../chat-notes/2026-05-23-sessions.md`](../chat-notes/2026-05-23-sessions.md) "noise-monkey visual design discussion" — dengang fandtes design-spec ikke, og planen var at backward-engineere via nano banana. Designdokumenterne **eksisterer nu** ([`brief.md`](brief.md), [`critique.md`](critique.md), [`../hardware/PRINT.md`](../hardware/PRINT.md), opdateret [`../hardware/dev-brief.md`](../hardware/dev-brief.md)), så denne note destillerer faktisk visuelt overblik fra dem. Hvis dokumenterne ændres, er kilden sandheden.

---

## TL;DR i én sætning

En ~220 mm høj, 3D-printet **Bojesen-tribute-abe** i wood-fill PLA + linolie, der står på skrivebordet, lytter via skjult I2S-mik, og **kupper langsomt sine hænder over sin egen mund** når støj er for høj for længe — drevet af én SG90-servo via skjulte sener. Øjnene forbliver synlige over hænderne — øjenkontakten bevares, og det er hvad der får "shh"-gestussen til at lande.

(Bemærk: gesten er **hænder-over-mund** — "Tys-aben" / Iwazaru. Tidligere chat-noter eksperimenterede kortvarigt med hænder-over-øjne, men det blev rullet tilbage: (1) geometrisk umuligt med stive 135 mm arme (se [`../cad/README.md`](../cad/README.md) "The gesture, revised"), og (2) hånd-over-mund er den eneste af Three Wise Monkeys-gestusene der er et direkte social signal til rummet, ikke en beskrivelse af abens egen tilstand.)

---

## Form & udtryk

- **Reference:** Kay Bojesens teak-abe fra 1951. *"Linjen skal smile."* Ikke en kopi — en tribute der tilføjer én ting Bojesen aldrig gjorde: **den bevæger sig selv.**
- **Højde:** 220 mm (lidt højere end Bojesen "small" 200 mm, så mekanikken kan gemmes uden at ødelægge silhuet).
- **Materialefølelse:** wood-fill PLA slebet 240→400→600 grit, derefter to lag kogt linolie. Skal læses som *træ*, ikke som 3D-print.
- **Palet:** lys "birk/limba" som krop, mørk "valnød/teak" som indlæg til øjenbræt + snude, sorte glasperler (Ø6 mm) som øjne.

### Aktuel status (V0.2) vs. ambition (Bojesen-niveau)

V0.2 er **kompetent organisk figurin** — over hobby-print, men ikke generationelt design endnu. [`critique.md`](critique.md) navngiver gabet ærligt:

| Punkt | V0.2 nu | Skal være |
|---|---|---|
| Pose | Siddende, ben spredt fremad (læses som "mid-shrug") | **Stående**, lange ben, bred fod-base, ~10° tå-ud |
| Arme | ~110 mm (~50% af højde) | **~135 mm (~60% af højde)** — den ikoniske Bojesen-signatur |
| Skuldre | Cylinder møder kugle i ret vinkel ("pølser boltet på tønde") | Flydende `hull()` — torsoen *svulmer* ud i armen |
| Hænder | Kugler | **Skålede håndflader**, håndled vippet let indad — møder ansigtet som *cuppede palms* |
| Ansigt | Glat kugle uden indlæg | Skulpteret pandebryn + kindplaner + defineret hage |
| Tech-afsløring | Bag-luge + USB-C synlig | Alt service skjult i aftagelig **træbase-skive**; krop = ét forseglet skulpturelt objekt |
| Hvilepositur | Slap | "Vågent" — hænder lidt fremme, arme let foran kroppen, blik fremad |

Top-5 til V0.3: rejs den op, arme til 135 mm, flydende skulder, træbase-skive, alert hvilepositur. 5 parametriske ændringer uden ny mekanisk kompleksitet.

---

## Proportioner (Bojesen "small")

| Del | Andel | Note |
|---|---|---|
| Hoved | ~31% | Nær-perfekt kugle, fladskåret hage, ingen hals |
| Torso | ~37% | Æg-snit, bredest ved skuldre, krummet rygsøjle-søm |
| Ben (stående) | ~35% | Cylindrisk, subtil taper |
| **Arme** | **~60%** | Lange — det vigtigste enkeltvise designtræk |

---

## Hvordan bevægelsen ser ud

Én SG90-servo lodret i torso trækker to braided fishing-line "sener" symmetrisk op gennem PTFE-fôrede kanaler ud til skuldrene. Returfjedre (eller én elastik på tværs af brystet, Bojesen-stil) trækker armene tilbage.

| Fase | Varighed | Detalje |
|---|---|---|
| Trigger | ≥800 ms over tærskel | Filtrerer enkelt-klap fra |
| Raise | 1.2 s | Cosinus-ease (ALDRIG lineær) |
| Hold | min. 4 s, så længe støj > tærskel − 6 dB hysterese | Ingen flicker på kanten |
| Lower | 1.8 s | Endnu langsommere — som modvilligt til at kigge igen |
| Cooldown | 8 s mindst | Social signal, ikke støjmåler |

Servoen er **lydløs ved hold** (end-of-travel mod bløde fjedre = ingen aktiv drift). Strømsvigt → fjedre trækker armene roligt ned: failure mode = "ro".

---

## Hardware (BOM under $25 for V1)

ESP32-S3 (USB-C) • I2S MEMS-mik (INMP441/SPH0645) peger op gennem hals-kavitet, lyd-port skjult bag øjenbrættet • SG90 servo • 6 mm sorte glasperler ×2 (øjne) • 3 mm stålpinde ×2 (skulder-pivot) • 60 cm braided fishing line (sener) • returfjeder / 2 mm sy-elastik • 5×2 mm neodym-magneter ×4 (bundplade) • USB-C breakout via hak i base-skive • USB-C kabel + 5V (intet batteri i V1).

---

## Print-overblik

- **13 parts**, ~21 timer, ~310 g filament.
- 3-fase: (1) valider mekanik på servo-bracket + yoke + bundplade — 1 t. (2) Valider torso-kavitet — 5 t. (3) Færdiggør body — 15 t.
- **Lemmer printes lodret** → lag-linjer langs lemmet → efter oliering læses som *træåre*.
- 0.4 mm hærdet stål-dyse. Maks 60 mm/s på wood-fill, ellers klogger.
- Bambu Studio profile i [`../hardware/PRINT.md`](../hardware/PRINT.md). Renders ligger i `../stl/`: `_assembly_front.png`, `_assembly_iso.png`, `_assembly_side.png`, `_triggered.png`.

---

## Hvorfor produktet eksisterer (fra [`../product/research.md`](../product/research.md))

- Kognitiv ydeevne -14% i open-plan vs. stille rum
- Op til -66% produktivitet ved forståelig baggrundssamtale
- Kun 32% tilfredse med kontorets støj (Leesman, 800k+)
- Akustisk tilfredshed falder skarpt over 45 dB
- → Trig på samtale-toppe, ikke gennemsnit. Visuel nudge ved 45–50 dB

---

## Hvad aben *ikke* er

Ikke støjmåler/dashboard. Ingen batteri i V1. Ingen hale. Ingen synlige skruer/kabler/LED'er/mærker/tekst. Ingen tegneserie-ansigt. Ingen taleinput i V1 (V2). Ingen multi-monkey-koordination. Ingen sky/app/analytics.

---

## Det vigtigste enkelte skift (fra [`critique.md`](critique.md))

> Hædr motion-øjeblikket som hele grunden til at objektet eksisterer.

Generationsversionen: den statiske form *venter synligt* på bevægelsen. Hænderne i hvile er ikke slappe — de er *poiseret*. Blikket er fremad, ikke nedad. Det er ikke en CAD-ændring — det er en *holdnings*-ændring.

---

## Bilag — denne chats forløb

1. Du bad om "et overblik over hvordan denne monkey kommer til at se ud" — jeg vidste ikke hvad "monkey" refererede til.
2. Du sagde "se office monkey" — jeg ledte lokalt under `/Users/gl/` og fandt intet.
3. Du klargjorde repoet hedder `Agent360dk/monkey-office`. Klonet til `/tmp/monkey-office`.
4. Læste alle design-docs og skrev denne destillation.
5. Push til eksisterende `gustav-chat-noter` branch (ovenpå tidligere noter fra dagen).

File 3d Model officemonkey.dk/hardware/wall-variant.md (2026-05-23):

# Wall variant (V1.1-wall) — current production design

Compact wall-mounted variant of Aben. V1.1 adds 2-piece articulated arms (hand-on-mouth gesture works), explicit mic_bracket, and external hub for the 60×120 mm motherboard that doesn't fit in the torso.

## Why it exists

The desktop V0.3 (220 mm standing on a base disc) is a beautiful Bojesen-tribute but ~21 hours of print time. For an office prototype where iteration speed matters, we needed something printable in an afternoon — and Bojesen's monkey is iconic for *hanging*, so wall-mount honours the heritage instead of fighting it.

## What changes vs V0.3 desktop

| | V0.3 desktop | **V1.1-wall** |
|---|---|---|
| Height | 220 mm | ~125 mm (incl. dangling legs) |
| Stance | Standing on base disc | Hangs from a keyhole on torso back |
| Total printed parts | 13 (incl. base disc) | **17** (15 monkey + 2 hub) |
| Print plates | 2 | **2** (monkey on plate 1, hub on plate 2) |
| Print time (est.) | ~21 h | **~6 h** (3.5h monkey + 2.5h hub) |
| Filament | ~310 g | **~58 g** |
| Arms | Single-piece rigid | **2-piece articulated** (hand reaches face) |
| Electronics housing | All inside torso | Mic + servo in monkey; **MCU in external hub** |
| Wall mount | — | Keyhole (monkey) + 2 screws (hub) |

## Files

- **CAD source:** [`../cad/monkey-wall.scad`](../cad/monkey-wall.scad)
- **STLs:** [`../stl/wall/`](../stl/wall/) — 12 parts
- **Bambu Studio project:** [`../prints/aben-wall.3mf`](../prints/aben-wall.3mf) — all parts on one plate
- **Renders:** [`../stl/wall/_front.png`](../stl/wall/_front.png), `_side.png`, `_back.png`, `_iso.png`, `_midmotion.png`, `_triggered.png`, `_wall_mockup.png`

## Design moves carried over from V0.3

- Bojesen-long arms (60% of body height)
- Organic taper via `hull()` of spheres
- Flowing shoulder caps (no clip-on look)
- Soft chin transition
- Hidden mic port behind one ear
- Curved torso seam
- Alert rest posture (arms slightly forward)

## Design moves NEW to wall variant

- **Keyhole mount** on torso back — 8 mm circle + 10 mm slot, recessed so the screw head sits flush inside the body
- **Dangling legs** — visible from front/side, glued into hip sockets, fully passive
- **Single magnet** on the small bottom hatch (vs. 4 magnets on desktop)
- **All parts on one print plate** — no need to swap mid-print

## Honest constraints

- The SG90 servo sets the **lower limit** on torso size. Cannot shrink torso below ~32 × 22 × 33 mm external without switching to a sub-micro servo (SG51R).
- Smaller eye holes (3.5 mm) means smaller beads or hand-painted dots.
- Wall thickness dropped from 2.4 → 2.0 mm — still strong enough but more brittle on long thin parts like arms.
- USB-C cable exits down through the bottom plate. Routes along the wall behind the monkey.

## How to print

1. Open `../prints/aben-wall.3mf` in Bambu Studio
2. Confirm your printer (X1C / P1S / A1) is selected
3. Load 2 filaments: light wood-fill PLA + dark wood-fill PLA (PETG optional for yoke/bracket — they can also be PLA at this small size)
4. Right-click each part → Filament → assign per part name
5. Slice → Send to printer

Per-part settings table is in [`PRINT.md`](PRINT.md) — same wood-fill rules apply (≤60 mm/s outer wall, hardened steel nozzle, sand + linseed-oil finish for the wood look).

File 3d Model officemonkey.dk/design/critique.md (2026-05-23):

# Design Critique — Aben V0.2

> An honest assessment of where the current design sits and what it would take to move it from "smukt 3D-print" to **generationelt skandinavisk design** — Bojesen, Wegner, Jacobsen, Henningsen, Mogensen niveau.

---

## What V0.2 actually is right now

A competent, organically-shaped, 3D-print-ready figurine with:
- Smooth surfaces (no hard primitive cuts left)
- Recognizable monkey silhouette
- Functional internal mechanism
- Clean assembly path

That puts it firmly above "hobby 3D print" but **well short** of generational design. The gap is real and worth naming.

---

## Why it isn't there yet

Looking at the front render with cold eyes, six things keep it from feeling like a Bojesen-tier object:

### 1. The form has no intentionality

It looks *made* (parametrically generated, smoothed, exported) rather than *designed* (a series of considered decisions left visible as character). Bojesen's monkey, Wegner's Y-chair, Jacobsen's Egg — every line in those objects feels like someone *chose it over alternatives*. Ours feels like it fell out of `hull()`.

**What's missing:** moments where a designer "leaves a fingerprint" — a slight asymmetry, a deliberate plane, a curve that doesn't *need* to be there but is.

### 2. Body parts are clip-on, not integrated

The arms emerge from the torso at a hard right angle, like sausages bolted to a barrel. Wegner spent his career on *how a leg meets a seat* — the joint is the design. Our shoulder is just where the cylinder happens to intersect the egg.

**What's missing:** a flowing shoulder. The torso should *swell* outward into the arm, the arm should *grow* out of the torso. Use `hull()` from torso shoulder bosses *into* the arm root — one continuous form, no visible join.

### 3. The hands are spheres

The hands are the **active element** of this product. They are what moves. They are what tells the story. And we've rendered them as plain bulbs at the end of the arm.

Bojesen's monkey hands are shaped objects — they have a slight curl, a directionality, you can tell which way the palm faces. Ours can't tell you anything.

**What's missing:** a *cup* in each hand. Hollow out a shallow indent on the palm-facing side. Tilt the wrist slightly so the palm angles inward. When the gesture happens, the hands meet the face like *cupped palms*, not like clubs.

### 4. The face is blank without the inserts

The eye-board and muzzle are *jewellery* — they should sit on top of a face that already has character. Currently, remove the inserts and you have a smooth sphere with two slight ears. No brow. No cheek planes. No defined chin. Nothing for light to catch on.

A generational designer composes the face *first*, then adds inserts as accent. We did it backward.

**What's missing:** sculpted brow ridge above the eye-board recess. Shallow cheek planes flanking the muzzle. A defined chin (subtle plane, not flat cut). These give the face its skeleton — the inserts are then *clothing* on a face that already exists.

### 5. The pose is the wrong story

Seated with legs splayed forward = "mid-shrug." It tells no story. Standing with long arms hanging at the sides = the iconic Bojesen story: *patient, watching, ready*. The eye-cover gesture lands harder from a standing patient pose than from a seated splay.

**What's missing:** stand it up. Lengthen the legs. Reposition the feet for a stable wide base, slightly toed-out (~10°) for charm. Arms hang long at the sides.

### 6. The proportions are off

Bojesen "small" (200mm tall) breakdown:
- Head ≈ 31% of height
- Torso ≈ 37%
- Legs (standing) ≈ 35%
- **Arms ≈ 62% of total height** ← the signature

Our V0.2:
- Head ≈ 33% ✓
- Torso ≈ 36% ✓
- Legs ≈ 35% (folded for seated) ✓
- **Arms ≈ 50%** ← too short by ~25mm

Long arms is THE Bojesen visual signature. Without them we don't read as a Bojesen-tribute — we read as a generic figurine.

**What's missing:** arms from 110mm to ~135mm (60% of total height).

### 7. The tech is visible

A back hatch. A USB-C cutout. Magnet pockets. These are *engineering admissions*. A generational object hides its engineering completely.

Verner Panton's chair is fiberglass — but you see no mold seams. Bojesen's monkey has 31 internal parts strung on elastic — but you see only wood and grace. Henningsen's PH lamp shows engineering, but as *the design itself*, not as a service hatch.

**What's missing:** move all access to a removable **wooden base disc** that the monkey stands on. USB-C threads through a notch in the disc edge. Servicing happens by lifting the monkey off its base. The disc IS the cable manager AND the access panel. The body itself becomes a single sealed sculptural object.

---

## What "the smile in the line" actually means (mechanically)

Bojesen said *"linjen skal smile."* In practical design terms this means: at every curve, ask whether the curve direction subtly arcs *upward* relative to the gaze of someone holding the object.

Specific places this applies for Aben:

| Curve | Current direction | Should be |
|---|---|---|
| Chin → neck | Symmetric drop | Slight forward-and-up lift before going down |
| Shoulder | Right-angle | Soft uplift before the arm descends |
| Elbow | Just narrower | Slight upward bulge before tapering forearm |
| Foot | Forward bulb | Forward-and-slightly-up tip (like a slipper toe) |
| Eye-board lozenge | Horizontal flat | Faint downward bow at the centre (like a smile, or a worried brow — both work because they suggest *expression*) |

These are 2-3mm decisions. But they're the difference between a curve that *exists* and a curve that *means something*.

---

## The single most important shift

If you do only one thing: **honor the moment of motion as the entire reason the object exists.**

Right now the static form and the motion are two separate things. The form is a figurine, the motion is a feature.

Generational version: the static form is *visibly waiting for the motion*. The hands at rest are subtly poised — not flopping, but ready. The eyes at rest look outward, attentive. When the motion happens, it's the only thing that matters, and the form has been quietly preparing you for it from the moment you put the object on your desk.

This isn't a CAD change. It's a *posture* change. Specifically:

- Hands at rest: slight forward angle (~15° toward chest), palms turned subtly inward — "ready to lift."
- Arms hang slightly forward of the body, not at the sides — "alert, not relaxed."
- Eyes positioned slightly *above* the muzzle (not at centre of face) — the gaze is forward, not downward — "watching."

These three details cost almost nothing in CAD time but change the product's emotional reading completely.

---

## Prioritized moves (ranked by impact-per-effort)

| # | Move | Effort | Impact |
|---|---|---|---|
| 1 | **Stand the monkey up** — legs straight, feet stable | small | huge — fixes the awkward pose, enables long-arm signature |
| 2 | **Arms to 135mm** (60% of height) | trivial parameter change | huge — Bojesen signature |
| 3 | **Flowing shoulder** — `hull()` torso-to-arm-root, no clip-on look | medium | huge — kills the "assembled from parts" feeling |
| 4 | **Sculpted hands** — palm cup, wrist tilt | medium | high — gives the gesture meaning |
| 5 | **Sculpted face** — brow, cheek planes, chin | medium | high — face reads even without inserts |
| 6 | **Wooden base disc** — hides USB, eliminates back hatch | medium | high — removes all "tech reveal" |
| 7 | **"Alert" rest posture** — hands forward, arms slightly off body | trivial | high — emotional intentionality |
| 8 | **"Smile in the line" curve tuning** — chin, shoulder, elbow, foot, eye-board | medium | medium — the difference between competent and beloved |
| 9 | **Invisible seam** — sand flush, wood-filler at the gap | post-print | medium — finishing-stage |
| 10 | **2-piece elastic arms** — for honest hand-to-face landing | high | medium — only matters if rigid arm reach proves wrong |

---

## What this is NOT asking for

- A bigger BOM
- More electronics
- More features
- A bigger object

Generational Scandinavian design **subtracts**. It removes the back hatch, removes the visible USB, removes the cartoon ears, removes the clip-on shoulders. What remains is fewer parts, fewer compromises, and one strong gesture.

The path forward is *less* — but more carefully chosen.

---

## Concrete next-step proposal (V0.3)

If we do just moves **1, 2, 3, 6, 7** above:
- Stand it up
- Arms 135mm
- Flowing shoulder via hull
- Wooden base disc (no back hatch, no rear USB)
- Alert rest posture

…that's 5 changes, all parametric, no new mechanism complexity. Result is a meaningfully more Bojesen-tier silhouette without growing scope.

Moves 4, 5, 7 (hand-sculpt, face-sculpt, curve-tuning) raise the ceiling further but want human sculpting time in Blender — they're V1.0 work, not V0.3.

Move 10 (2-piece arms) only matters if a printed V0.3 proves the gesture doesn't land. Defer until physical prototype.

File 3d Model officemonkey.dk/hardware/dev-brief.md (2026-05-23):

# Monkey — Office Noise Reactor

> 3D-printed monkey that listens to the room and reacts when the office gets too loud.

---

## 1. Concept (one paragraph)

A small, 3D-printed monkey sits on a desk or shelf in an open office. It contains an ESP32 with a microphone that continuously measures ambient sound level. When the noise crosses a threshold (e.g. sustained chatter, a loud meeting bleeding into the open floor), the monkey reacts in a way that gently signals "it's too loud in here" — without anyone having to be the person who shushes the room.

The reaction itself is intentionally left open in this plan (see §5) — we want the dev taking this over to weigh in on what's feasible, cheap, and not annoying after the 50th trigger.

---

## 2. Scope — what V1 must do

**Must:**
- Detect ambient noise level via onboard microphone.
- Trigger a reaction when noise exceeds a configurable threshold for a configurable duration (avoid reacting to single claps / door slams).
- Be self-contained inside a 3D-printed monkey enclosure.
- Run from USB-C power (no battery in V1).

**Nice-to-have (V1.x):**
- WiFi connectivity for remote config / threshold tuning.
- Simple web UI or app to see current dB level + adjust sensitivity.
- Voice input (see §6).

**Out of scope for V1:**
- Battery / portable operation.
- Multiple monkeys talking to each other.
- Cloud dashboard, analytics.

---

## 3. Hardware bill of materials

| Part | Notes | Approx cost |
|---|---|---|
| ESP32 dev board (ESP32-S3 recommended) | Built-in WiFi/BT, I2S mic support, USB-C | ~$5–10 |
| I2S MEMS microphone (e.g. INMP441 or SPH0645) | Digital mic, cleaner than analog for noise-level work | ~$3 |
| Reaction output (TBD — see §5) | Speaker / LEDs / micro-servo | $2–10 |
| 3D-printed enclosure | PLA, designed around chosen components | filament cost only |
| USB-C cable + 5V power supply | | ~$5 |

**Total target BOM: under $25.**

---

## 4. Software stack (proposed)

- **Firmware:** Arduino-ESP32 framework (C++) or ESP-IDF. Avoid MicroPython for V1 — audio sampling timing is easier in C.
- **Audio sampling:** I2S DMA → compute short-window RMS → smoothed dB-ish value.
- **Trigger logic:** threshold + dwell time (e.g. "above X for Y seconds") + cooldown (don't re-trigger for Z seconds after a reaction).
- **Config:** hard-coded constants in V1; WiFi-served config page in V1.1.

---

## 5. Open question — what does the monkey actually DO when triggered?

**This is the main thing to nail down with the dev taking over.** Options, with rough trade-offs:

- **Sound playback** (small speaker + DFPlayer Mini or ESP32 internal DAC) — funniest, most attention-grabbing, but risk of becoming the new noise problem. Could be a quiet "shhh" sample rather than a scream.
- **LED reaction** (eyes glow red, body pulses) — least disruptive, easy to ignore, may not actually change behavior.
- **Servo movement** (covers ears, shakes head, points) — visually fun, mechanical complexity, more to print and fit.
- **Combo** — LEDs always, sound only on sustained high level.
- **Silent / passive** — just logs to a dashboard, no in-room reaction. Boring but useful as a real metric.

**Recommendation to discuss:** start with LED-only for V1 to validate the noise detection, then add sound/servo in V1.1 once we know the trigger logic is solid.

---

## 6. Voice input — what do we mean?

The original brief mentioned "voice input." Two possible interpretations — the dev taking this over should confirm which:

1. **Microphone for ambient noise detection** (assumed primary meaning) — covered above.
2. **Voice commands** (e.g. say "monkey, calibrate" to set the threshold for current ambient level) — possible on ESP32-S3 with a small wake-word model, but adds real complexity. Suggest deferring to V2 unless there's a strong reason.

---

## 7. 3D-printing notes

- Design enclosure AFTER picking the reaction hardware (§5) — speaker grille, LED diffuser cutouts, or servo mount all change the model.
- Keep the mic port small but unobstructed — don't print a closed face over it.
- Use a snap-fit or single-screw back panel for access to the ESP32.
- Source/fork an existing CC-licensed monkey model rather than modeling from scratch.

---

## 8. Suggested milestones

1. **Breadboard prototype** — ESP32 + I2S mic, print dB values over serial. Confirm we can reliably distinguish "quiet office" from "loud office."
2. **Trigger logic** — threshold + dwell + cooldown, blink onboard LED on trigger.
3. **Pick reaction hardware** (resolve §5) and wire it in.
4. **Enclosure design** — 3D model around chosen components, print, fit, iterate.
5. **WiFi config page** (V1.1).

---

## 9. Decisions the dev needs to make / confirm

- [ ] Reaction type (§5) — recommend starting LED-only.
- [ ] Voice input interpretation (§6) — confirm "ambient noise" is what was meant.
- [ ] ESP32 variant — plain ESP32 vs ESP32-S3 (S3 if we ever want on-device voice).
- [ ] Mic model — INMP441 vs SPH0645 (either is fine; pick whichever is in stock locally).
- [ ] Monkey model — find a printable model or commission one.
- [ ] Threshold calibration approach — fixed in code, button on device, or WiFi config.

---

## 10. Out of scope / explicitly not doing in V1

- Battery operation.
- Multi-device coordination.
- Mobile app.
- Cloud / analytics / "noise heatmap of the office."
- Any kind of speech recognition or AI on-device.

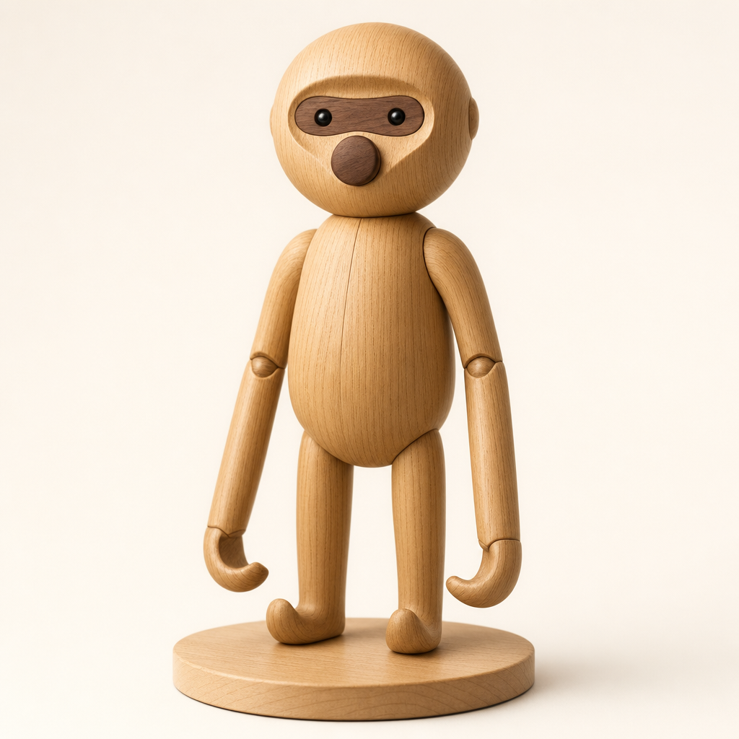
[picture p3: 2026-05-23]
3d Model officemonkey.dk/design/renders/hero-20260523-143831.png

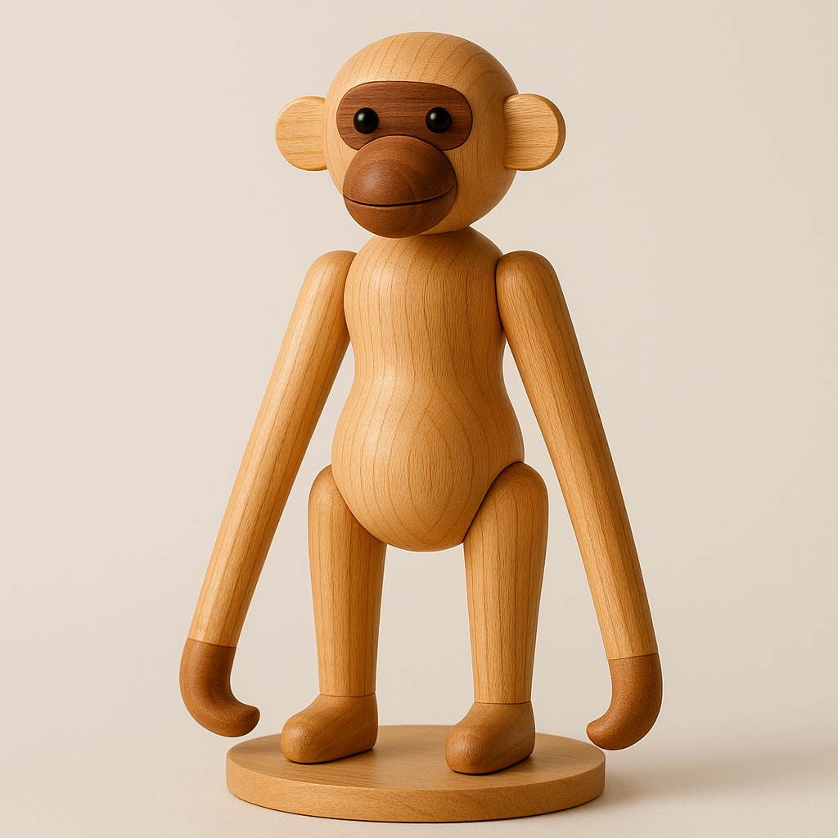
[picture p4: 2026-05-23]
3d Model officemonkey.dk/design/renders/hero-20260523-143458.png

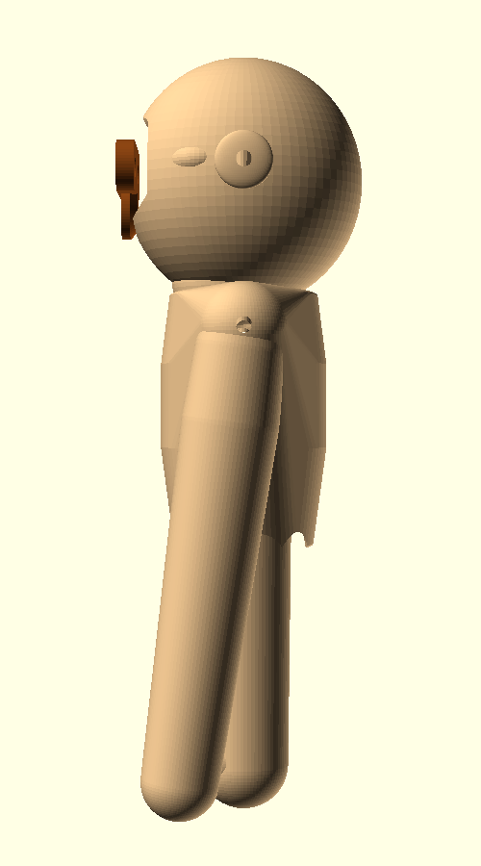
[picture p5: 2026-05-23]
3d Model officemonkey.dk/stl/wall/_side.png

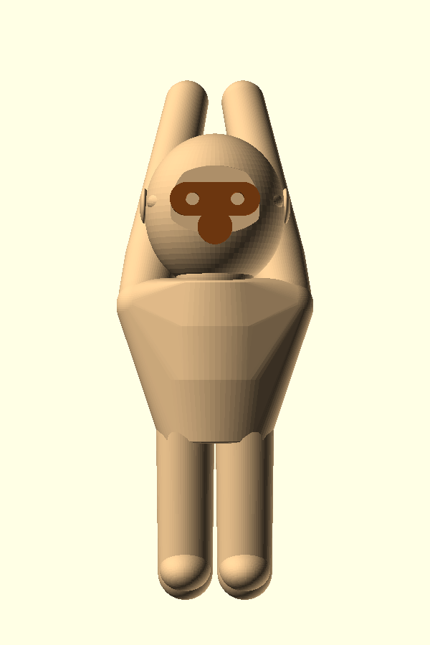
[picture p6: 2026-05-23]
3d Model officemonkey.dk/stl/wall/_triggered.png

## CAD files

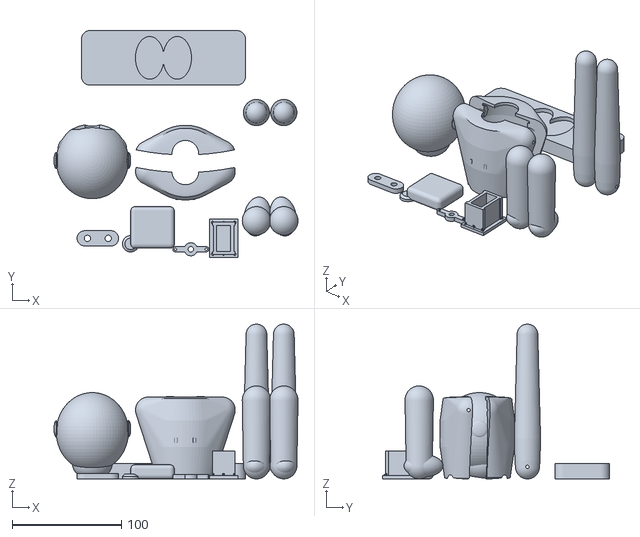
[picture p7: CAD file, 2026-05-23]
Tys-aben-Print-Package/tys-aben-desktop-complete.stl
223.1 x 207.5 x 141.5

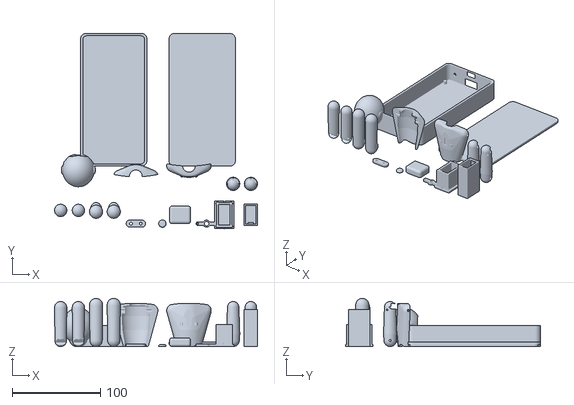
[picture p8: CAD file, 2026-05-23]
Tys-aben-Print-Package/tys-aben-wall-complete.stl
229.5 x 220.5 x 54.5

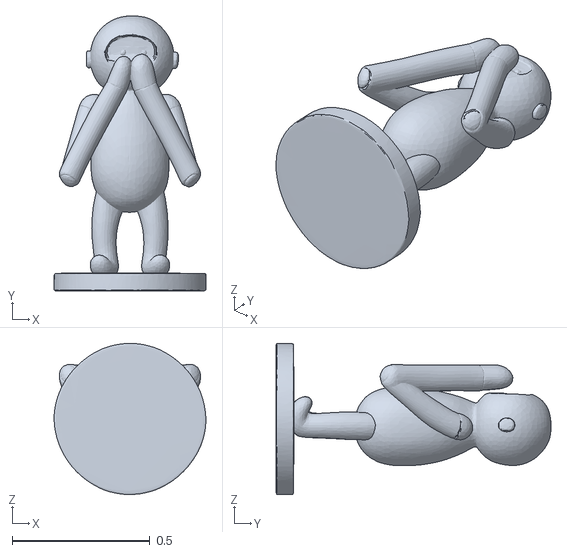
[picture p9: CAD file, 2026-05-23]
3d Model officemonkey.dk/design/renders/mesh-frame-4-peak-trellis.stl
0.552 x 1 x 0.55

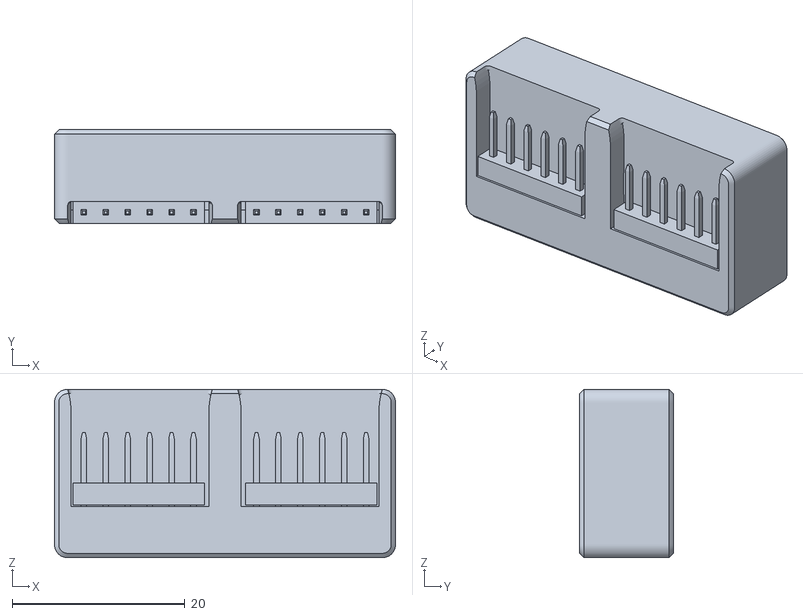
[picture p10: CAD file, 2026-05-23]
3d Model officemonkey.dk/hardware/components/microphone.stl
39.5 x 10.8 x 19.5

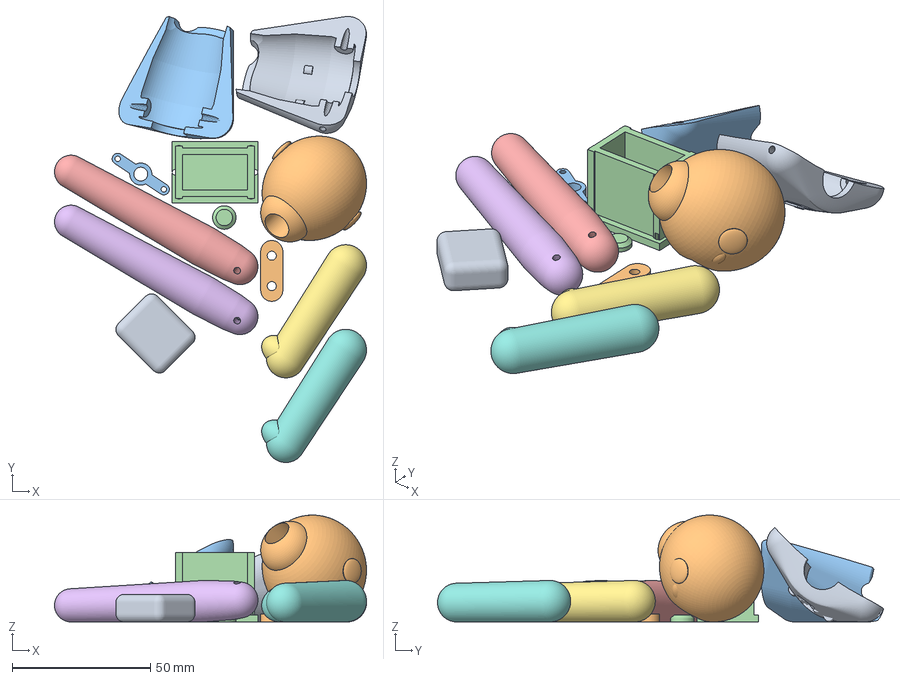
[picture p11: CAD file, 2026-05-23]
3d Model officemonkey.dk/prints/aben-wall.3mf
112.8 x 161.2 x 38.6 mm
torso_back.stl
head.stl
torso_front.stl
servo_bracket.stl
arm_left.stl
arm_right.stl
leg_left.stl
leg_right.stl
bottom_plate.stl
eye_board.stl
yoke.stl
muzzle.stl

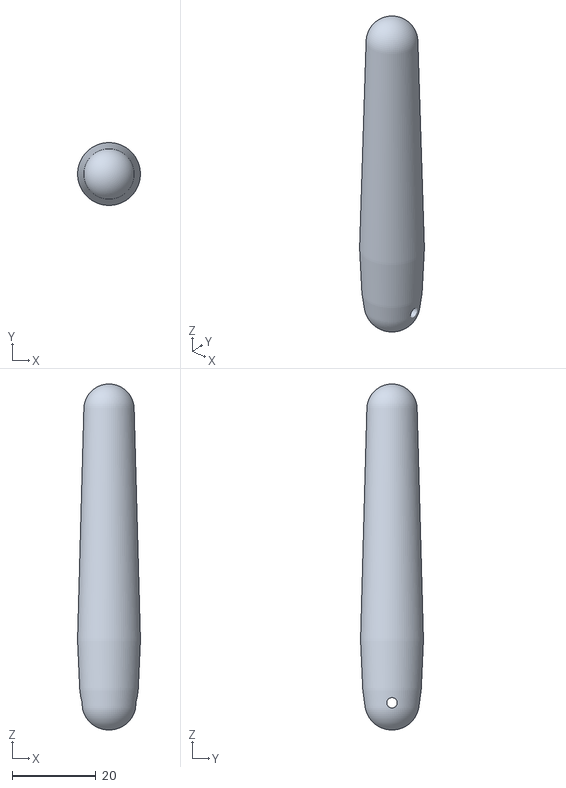
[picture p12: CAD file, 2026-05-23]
3d Model officemonkey.dk/stl/wall/arm_right.stl
15.0 x 15.0 x 82.5

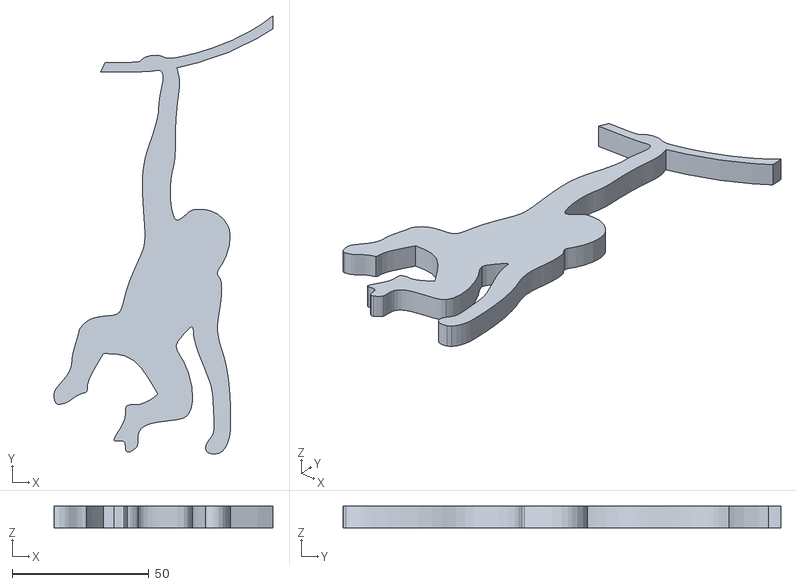
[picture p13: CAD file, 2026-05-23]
cad/monkey.stl
80.0 x 160.0 x 8.00

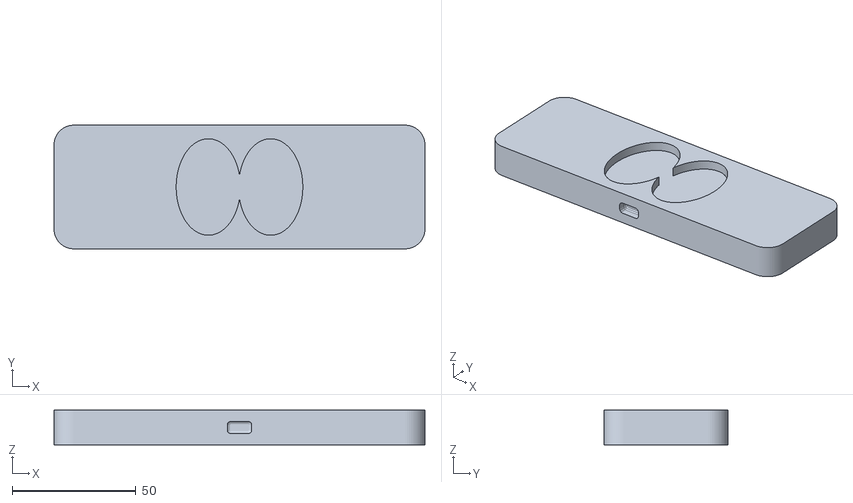
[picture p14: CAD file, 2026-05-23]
Tys-aben-Print-Package/individual-parts/desktop/base_disc.stl
150.0 x 50.0 x 14.0

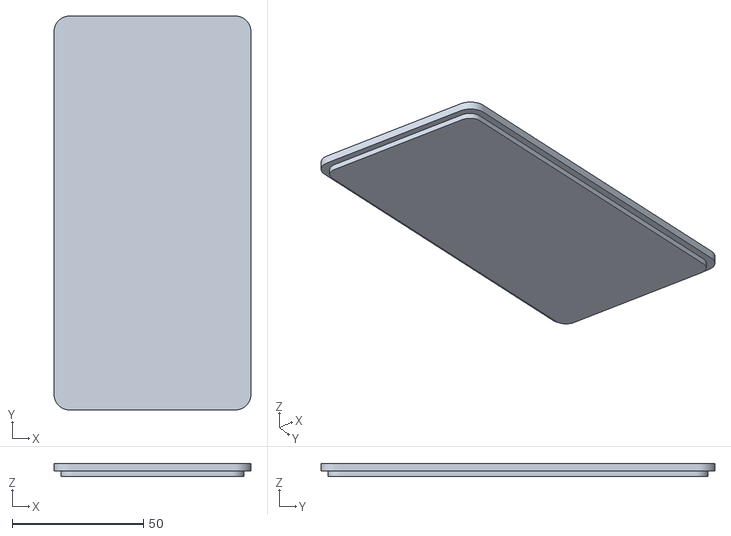
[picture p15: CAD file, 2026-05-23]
Tys-aben-Print-Package/individual-parts/wall/hub_lid.stl
75.0 x 150.0 x 5.10

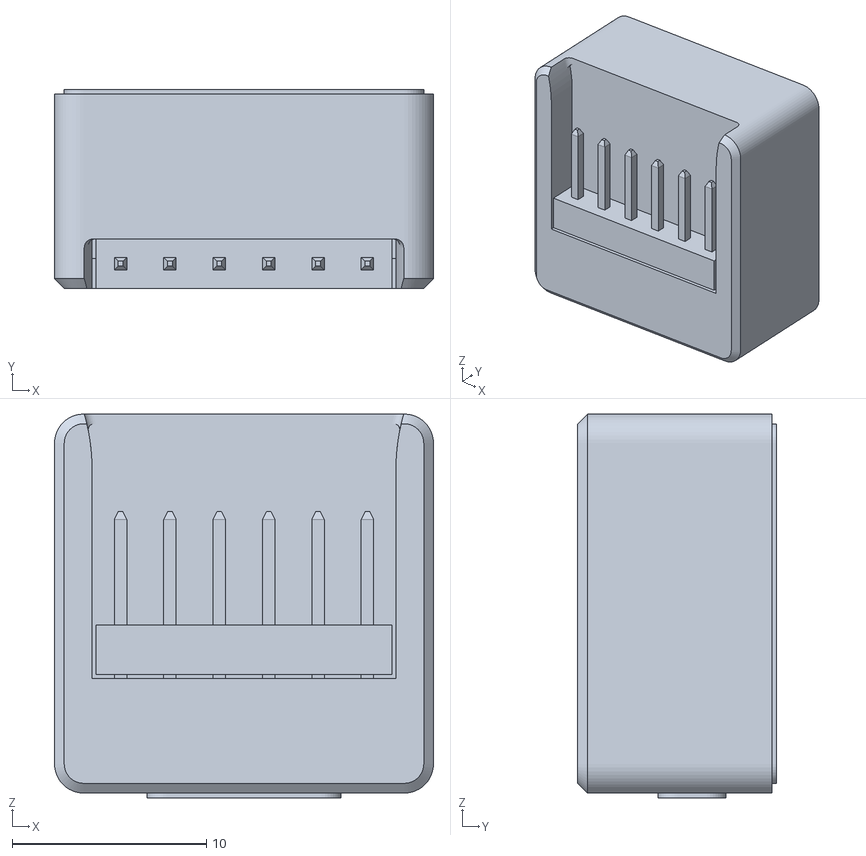
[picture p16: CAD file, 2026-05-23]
3d Model officemonkey.dk/hardware/components/usbc.stl
19.5 x 10.2 x 19.8

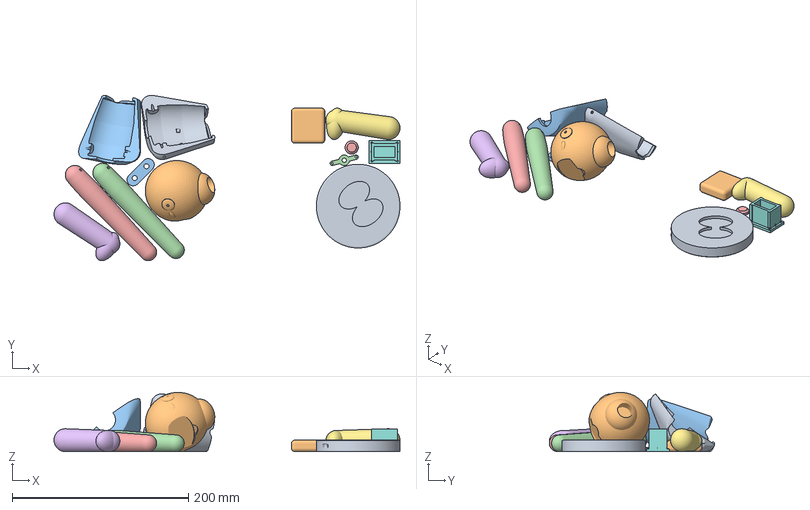
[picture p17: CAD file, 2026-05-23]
3d Model officemonkey.dk/prints/aben.3mf
393.0 x 187.8 x 67.2 mm
torso_back.stl
head.stl
torso_front.stl
arm_left.stl
arm_right.stl
leg_right.stl
leg_left.stl
servo_bracket.stl
base_disc.stl
bottom_plate.stl
eye_board.stl
yoke.stl
muzzle.stl

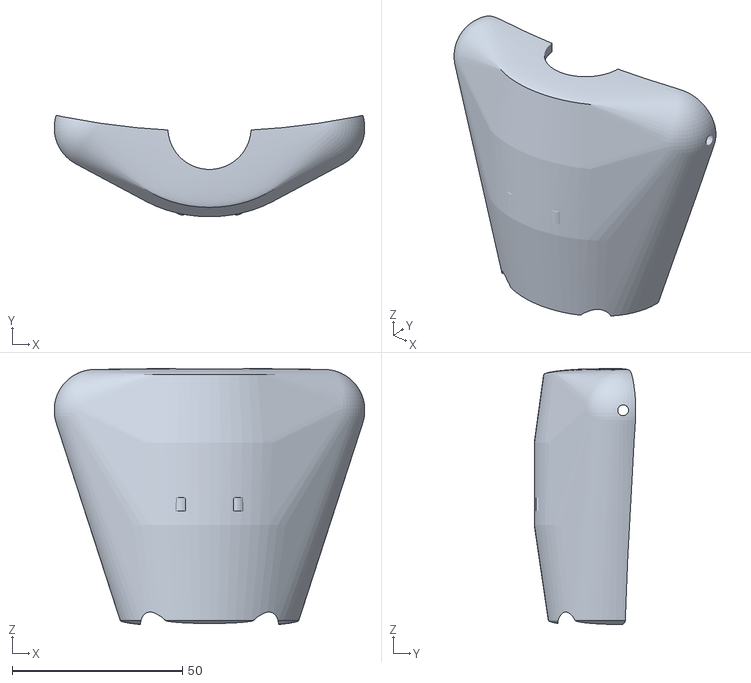
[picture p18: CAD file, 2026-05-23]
Tys-aben-Print-Package/individual-parts/desktop/torso_back.stl
91.0 x 29.8 x 75.1

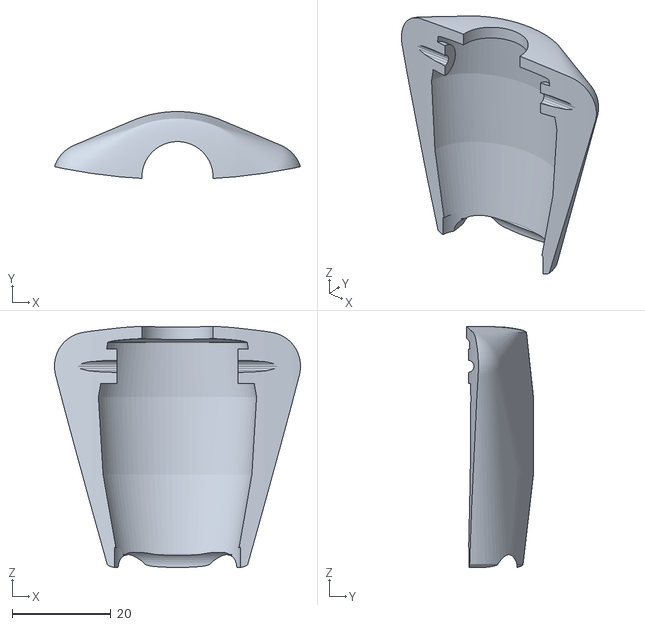
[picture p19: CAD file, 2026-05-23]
Tys-aben-Print-Package/individual-parts/wall/torso_front.stl
49.8 x 13.5 x 48.9

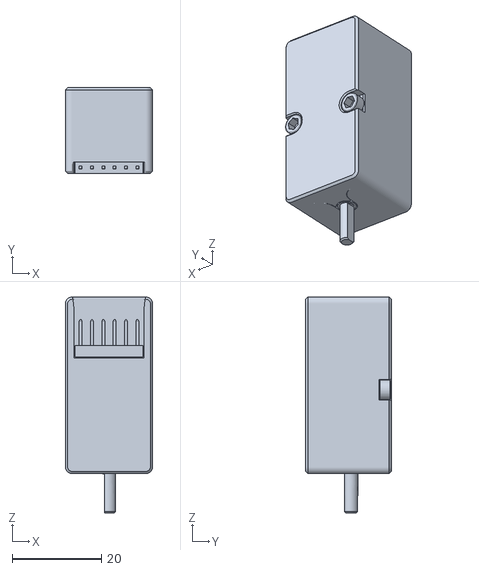
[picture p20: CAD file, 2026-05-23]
3d Model officemonkey.dk/hardware/components/dc_motor.stl
19.5 x 19.1 x 48.3

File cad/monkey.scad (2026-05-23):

// =====================================================================
//  Aben — parametric Bojesen-tribute monkey, V0.3
//  ---------------------------------------------------------------------
//  V0.3 moves (from design-critique.md):
//    1. Standing pose — straight legs, feet on ground (was seated)
//    2. Long arms — 130 mm, 59% of total height (Bojesen signature)
//    3. Flowing shoulder — torso swells outward at shoulder via hull(),
//       arm root matches the curve; no clip-on look
//    4. Wooden base disc — separate part, hides USB-C and houses
//       servicing access; back hatch removed entirely
//    5. Bottom hatch on torso (invisible when standing on base)
//    6. Alert rest posture — arms hang slightly forward
//
//  Coordinate system: Z=0 at ground (bottom of base disc),
//                     +Z up, +Y forward (toward viewer), +X to the right.
//
//  Units: millimetres.
// =====================================================================

part = "preview";   // "preview" | "triggered" | "head" | "torso_front"
                    // | "torso_back" | "bottom_plate" | "arm_left"
                    // | "arm_right" | "leg_left" | "leg_right"
                    // | "eye_board" | "muzzle" | "base_disc"
                    // | "servo_bracket" | "yoke"

// ---------- BODY DIMENSIONS ----------
total_h            = 220;                      // monkey only (excludes base)
foot_h             = 18;                       // foot bulb height
leg_h              = 60;                       // hip to foot
torso_h            = 80;
head_h             = 72;
torso_w            = 70;
torso_d            = 55;
head_w             = 66;
head_d_front       = 70;
arm_total_l        = 130;                      // 59% of total_h — Bojesen-long
shoulder_z         = leg_h + foot_h + torso_h*0.85;  // ~177
torso_center_z     = leg_h + foot_h + torso_h/2;     // ~118
head_center_z      = leg_h + foot_h + torso_h + head_h/2 - 8; // overlap for neck

// ---------- BASE DISC ----------
base_d             = 95;                       // wider than monkey for stability
base_h             = 14;
base_foot_recess   = 4;
base_usb_notch_w   = 10;
base_usb_notch_h   = 5;

// ---------- FACE / DETAIL ----------
eyeboard_w         = 38;
eyeboard_h         = 14;
eye_d              = 6;
eye_spacing        = 19;
muzzle_d           = 15;
face_recess_depth  = 3.5;

// ---------- WALL & FIT ----------
wall               = 2.4;
fit_loose          = 0.4;
fit_tight          = 0.2;

// ---------- MECHANISM ----------
sg90_body_l        = 23.0;
sg90_body_w        = 12.2;
sg90_body_h        = 22.5;
esp_w              = 28;
esp_l              = 65;
shoulder_pin_d     = 3.2;
tendon_ch_d        = 2.4;

// ---------- RESOLUTION ----------
$fa = 3;
$fs = 0.8;
$fn_smooth         = 64;

// =====================================================================
//  HELPERS
// =====================================================================

module ovoid(w, d, h) {
    scale([w/2, d/2, h/2]) sphere(r=1, $fn=$fn_smooth);
}

module rounded_box(w, d, h, r=3) {
    hull() {
        for (x=[-1,1], y=[-1,1], z=[-1,1])
            translate([x*(w/2-r), y*(d/2-r), z*(h/2-r)]) sphere(r);
    }
}

module lozenge(w, h, t) {
    hull() {
        translate([-(w-h)/2, 0, 0]) cylinder(d=h, h=t);
        translate([ (w-h)/2, 0, 0]) cylinder(d=h, h=t);
    }
}

// Organic limb: hull of spheres at [z, diameter] control points
module tapered_limb(points) {
    hull() for (p = points)
        translate([0, 0, p[0]]) sphere(d=p[1], $fn=$fn_smooth);
}

// =====================================================================
//  HEAD
// =====================================================================

module head_solid() {
    union() {
        // Ovoid cranium
        ovoid(head_w, head_d_front, head_h);
        // Soft chin (no flat cut)
        translate([0, head_d_front*0.04, -head_h*0.40])
            scale([0.85, 0.85, 0.7]) sphere(d=head_w*0.65, $fn=$fn_smooth);
        // Subtle brow ridge
        translate([0, head_d_front*0.16, head_h*0.05])
            scale([1, 0.55, 0.35]) sphere(d=head_w*0.95, $fn=$fn_smooth);
        // Vestigial ears
        for (s=[-1,1]) translate([s*head_w/2, 0, head_h*0.04])
            scale([0.28, 1, 1]) sphere(d=15, $fn=$fn_smooth);
        // Neck plug
        translate([0, 0, -head_h/2 + 2]) cylinder(d=24, h=12);
    }
}

module head() {
    difference() {
        head_solid();
        // Face recess
        translate([0, head_d_front/2 - face_recess_depth + 1, head_h*0.05])
            rotate([90,0,0]) scale([1, 0.65, 1])
                cylinder(d=46, h=face_recess_depth*2.5, center=true, $fn=$fn_smooth);
        // Muzzle dimple
        translate([0, head_d_front/2 - face_recess_depth + 1, -head_h*0.12])
            rotate([90,0,0])
                cylinder(d=muzzle_d - 1, h=face_recess_depth*1.5, center=true);
        // Mic port hidden behind left ear
        translate([-head_w/2 - 5, 0, head_h*0.04])
            rotate([0,90,0]) cylinder(d=3, h=head_w);
        // Neck cavity
        translate([0,0,-head_h/2]) cylinder(d=18, h=20, center=true);
    }
}

// =====================================================================
//  FACE INSERTS
// =====================================================================

module eye_board() {
    eyeboard_t = face_recess_depth + 1.2;
    difference() {
        lozenge(eyeboard_w, eyeboard_h, eyeboard_t);
        for (s=[-1,1]) translate([s*eye_spacing/2, 0, -0.1])
            cylinder(d=eye_d - 0.2, h=eyeboard_t + 0.2);
    }
}

module muzzle() {
    muzzle_t = face_recess_depth + 0.5;
    hull() {
        cylinder(d=muzzle_d, h=muzzle_t*0.6);
        translate([0,0,muzzle_t*0.7]) cylinder(d=muzzle_d*0.7, h=muzzle_t*0.4);
    }
}

// =====================================================================
//  TORSO  (organic egg + flowing shoulder caps)
// =====================================================================

// Shoulder cap position in torso-local Z (relative to torso center)
shoulder_local_z = torso_h*0.32;

module torso_outer() {
    hull() {
        // Main torso column — taper from shoulder (wide) to hip (narrower)
        translate([0,0, torso_h*0.45]) ovoid(torso_w*0.85, torso_d*0.85, 4);
        translate([0,0, torso_h*0.20]) ovoid(torso_w*0.95, torso_d*0.95, 4);
        translate([0,0,-torso_h*0.10]) ovoid(torso_w*0.90, torso_d*0.95, 4);
        translate([0,0,-torso_h*0.45]) ovoid(torso_w*0.75, torso_d*0.80, 4);
        // Flowing shoulder caps — extend torso outward to meet arm root.
        // hull() with the rest creates a continuous swell, no clip-on look.
        for (s=[-1,1]) translate([s*torso_w*0.48, 0, shoulder_local_z])
            sphere(d=24, $fn=$fn_smooth);
    }
}

module torso_cavity() {
    hull() {
        translate([0,0, torso_h*0.45 - wall]) ovoid(torso_w*0.85 - 2*wall, torso_d*0.85 - 2*wall, 3);
        translate([0,0, torso_h*0.20]) ovoid(torso_w*0.95 - 2*wall, torso_d*0.95 - 2*wall, 3);
        translate([0,0,-torso_h*0.10]) ovoid(torso_w*0.90 - 2*wall, torso_d*0.95 - 2*wall, 3);
        translate([0,0,-torso_h*0.45 + wall]) ovoid(torso_w*0.75 - 2*wall, torso_d*0.80 - 2*wall, 3);
    }
}

module torso_base() {
    difference() {
        torso_outer();
        torso_cavity();
        // Neck socket
        translate([0,0, torso_h/2 - 6]) cylinder(d=24 + fit_loose, h=14);
        // Shoulder pin holes (through the shoulder caps)
        for (s=[-1,1]) translate([s*torso_w*0.48, 0, shoulder_local_z])
            rotate([0,90,0]) cylinder(d=shoulder_pin_d, h=30, center=true);
        // Bottom hatch — invisible when standing on base disc
        translate([0, 0, -torso_h/2 + 1])
            rounded_box(40 + fit_loose, 38 + fit_loose, 4, r=4);
        // Leg sockets — where leg pegs insert into torso bottom
        for (s=[-1,1]) translate([s*torso_w*0.18, 0, -torso_h/2 + 2])
            cylinder(d=14 + fit_loose, h=10, center=true);
        // Mic chamber opening
        translate([0,0, torso_h/2 - 6]) cylinder(d=14, h=20);
    }
    // Shoulder pin bosses (reinforcement around pin)
    for (s=[-1,1]) translate([s*torso_w*0.42, 0, shoulder_local_z])
        rotate([0,90,0]) difference() {
            cylinder(d=12, h=8, center=true);
            cylinder(d=shoulder_pin_d, h=10, center=true);
        }
}

// Curved seam: hidden by being on the left side of the body
seam_R = 220;
module torso_split_curved() {
    translate([0, seam_R - 1, 0])
        cylinder(r = seam_R, h = 400, center = true, $fn=128);
}

module torso_front() {
    intersection() {
        torso_base();
        torso_split_curved();
    }
}

module torso_back() {
    difference() {
        torso_base();
        torso_split_curved();
    }
    // ESP32 standoffs on inside back wall
    for (s=[-1,1])
        translate([s*(esp_w/2 - 3), -torso_d/2 + wall + 2, -torso_h*0.05])
            cylinder(d=5, h=4);
}
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

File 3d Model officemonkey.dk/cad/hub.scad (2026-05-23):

// =====================================================================
//  Tys-aben — External Hardware Hub
//  ---------------------------------------------------------------------
//  A separate small wooden enclosure that holds the components that
//  cannot fit inside Aben herself:
//    * Motherboard (60 × 7 × 120 mm) — lies flat in the bottom
//    * DC motor (19.5 × 19.1 × 48.3 mm) — stands vertically next to board
//    * USB-C breakout (19.5 × 10.2 × 19.8 mm) — wall-side port
//    * Spare room for wiring + tendon-pulley if motor drives tendons
//      remotely
//
//  Designed to sit on the desk behind the monkey or mount on the wall
//  immediately below it. Same wood-fill PLA + linseed-oil finish as the
//  monkey itself — reads as a deliberate matching object, not a brick.
//
//  Coordinate system: Z up, +Y forward (out from wall / facing monkey).
//  Units: millimetres.
// =====================================================================

part = "preview";   // "preview" | "hub_box" | "hub_lid"

// ---------- OUTER ENVELOPE ----------
// Sized for 60 × 120 mm motherboard + tolerance safety. Interior
// dimensions after 2.5 mm walls: (hub_w - 5) × (hub_l - 5) × hub_h.
// Motherboard footprint 60 × 120 → interior 70 × 150 gives ≥5 mm
// margin on every side (was tight at 2.5 mm — bumped to absorb
// 0.3 mm print tolerance + warping).
hub_w              = 75;       // X — width (motherboard 60 + walls + safety margin)
hub_l              = 150;      // Y — length (motherboard 120 + walls + safety margin)
hub_h              = 24;       // Z — height (motherboard 7 mm thick + USB-C connector + margin)
wall_t             = 2.5;
corner_r           = 6;
fit_loose          = 0.4;

// ---------- COMPONENT DIMENSIONS (matches hardware/components/ STLs) ----------
mb_w               = 60;
mb_l               = 120;
mb_h               = 7;
motor_w            = 19.5;
motor_l            = 19.1;
motor_h            = 48.3;
usbc_w             = 19.5;
usbc_d             = 10.2;
usbc_h             = 19.8;

// ---------- CABLE INLET (top — wires up to the monkey) ----------
inlet_w            = 14;
inlet_h            = 8;

// ---------- RESOLUTION ----------
$fa = 2;
$fs = 0.5;
$fn_smooth         = 80;

// =====================================================================
//  HELPERS
// =====================================================================

module rounded_box(w, d, h, r=2) {
    hull() {
        for (x=[-1,1], y=[-1,1], z=[-1,1])
            translate([x*(w/2-r), y*(d/2-r), z*(h/2-r)]) sphere(r);
    }
}

module rounded_plate(w, d, h, r) {
    linear_extrude(height=h)
        offset(r=r) offset(r=-r)
            square([w, d], center=true);
}

// =====================================================================
//  HUB BOX  (the lower shell — motherboard + motor live here)
// =====================================================================

module hub_box() {
    difference() {
        // Outer shell
        rounded_plate(hub_w, hub_l, hub_h, corner_r);
        // Internal cavity — open top, closed bottom (lid closes the top)
        translate([0, 0, wall_t])
            rounded_plate(hub_w - 2*wall_t, hub_l - 2*wall_t, hub_h, corner_r - wall_t/2);
        // Cable inlet on the TOP rear edge — wires up to the monkey
        translate([0, hub_l/2 - 4, hub_h - inlet_h/2 - 0.5])
            rotate([0, 0, 0])
                rounded_box(inlet_w, 10, inlet_h, r=1.5);
        // USB-C breakout cutout on rear wall (for power input)
        translate([0, hub_l/2 + 0.1, 7])
            rotate([90, 0, 0])
                rounded_box(usbc_w + 1, usbc_d + 1, wall_t*2 + 1, r=1);
        // Lid magnet pockets — 4 corners on the top rim
        for (x=[-1,1], y=[-1,1])
            translate([x*(hub_w/2 - 6), y*(hub_l/2 - 6), hub_h - 2.4])
                cylinder(d=5.2, h=2.6);
        // Mounting screw holes on the back wall (for wall-mounting under monkey)
        for (s=[-1,1])
            translate([s*(hub_w/2 - 12), hub_l/2 + 0.1, hub_h/2])
                rotate([90, 0, 0])
                    cylinder(d=4.5, h=wall_t*2 + 1);
    }

    // Motherboard rails — board lies flat against the bottom, held by 4 raised pegs
    mb_z = wall_t;
    for (x=[-1,1], y=[-1,1])
        translate([x*(mb_w/2 + 1), y*(mb_l/2 + 1), mb_z])
            cylinder(d=4, h=4);

    // (DC motor cradle removed — V1 uses SG90 servo inside the monkey's
    // torso, not a DC motor in the hub. DC motor is parked as a V2 spare.)
}

// =====================================================================
//  HUB LID  (snaps onto the top of the box via 4 magnets)
// =====================================================================

module hub_lid() {
    lid_t = 3;
    inset = wall_t + 0.2;
    difference() {
        union() {
            // Top plate
            rounded_plate(hub_w, hub_l, lid_t, corner_r);
            // Lower inset that drops into the box cavity
            translate([0, 0, -wall_t + 0.4])
                rounded_plate(hub_w - 2*inset, hub_l - 2*inset, wall_t - 0.4, corner_r - inset/2);
        }
        // Magnet pockets to mate with the box's magnets
        for (x=[-1,1], y=[-1,1])
            translate([x*(hub_w/2 - 6), y*(hub_l/2 - 6), lid_t/2 - 1.4])
                cylinder(d=5.2, h=2.6);
    }
}

// =====================================================================
//  RENDER
// =====================================================================

module preview() {
    color("burlywood") hub_box();
    translate([0, 0, hub_h + 6])
        color("peru") hub_lid();
}

if      (part == "preview") preview();
else if (part == "hub_box") hub_box();
else if (part == "hub_lid") hub_lid();

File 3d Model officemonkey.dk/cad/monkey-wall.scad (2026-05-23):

// =====================================================================
//  Aben — Wall variant (V1.0-wall)
//  ---------------------------------------------------------------------
//  Smaller wall-mounted variant. Target: ~125 mm tall total (including
//  dangling legs), under 4 h total print time, hangs from a keyhole on
//  the back of the torso.
//
//  Why wall-mount: Bojesen's monkey is iconic for *hanging* from things
//  — shelves, coat hooks, branches. Wall-mounting honours that heritage
//  and lets us eliminate the base disc entirely. The dangling-legs look
//  becomes a design feature instead of an awkward seated splay.
//
//  Constraints driving sizing:
//    * SG90 servo: 23 × 12.2 × 22.5 mm body → torso cavity must be
//      at least 27 × 17 × 28 mm internal → external floor ~32 × 22 × 33 mm.
//      Below this size, you need a smaller servo (SG51R or similar).
//    * Wall thickness 2.0 mm (slightly thinner than desktop variant).
//
//  Coordinate system: Z=0 at torso center, +Z up, +Y forward (out from
//  wall — face direction), +X right.
//
//  Units: millimetres.
// =====================================================================

part = "preview";   // "preview" | "triggered" | "midmotion" | "wall_mockup"
                    // | "head" | "torso_front" | "torso_back" | "bottom_plate"
                    // | "arm_left" | "arm_right" | "leg_left" | "leg_right"
                    // | "eye_board" | "muzzle" | "servo_bracket" | "yoke"

// ---------- DIMENSIONS (~55% of desktop) ----------
torso_h            = 52;                       // raised from 44 → gives mic (39.5 mm) real clearance
torso_w            = 38;
torso_d            = 28;
head_w             = 36;
head_h             = 40;
head_d_front       = 38;
leg_h              = 40;
leg_d              = 13;
arm_total_l        = 75;
shoulder_local_z   = torso_h * 0.32;

// ---------- FACE / DETAIL ----------
eyeboard_w         = 22;
eyeboard_h         = 8;
eye_d              = 3.5;
eye_spacing        = 11;
muzzle_d           = 8.5;
face_recess_depth  = 2;

// ---------- WALL & FIT ----------
wall               = 2.0;
fit_loose          = 0.4;
fit_tight          = 0.2;

// ---------- WALL MOUNT (keyhole on torso back) ----------
keyhole_circle_d   = 8;
keyhole_slot_w     = 2.8;
keyhole_slot_h     = 10;
keyhole_z          = torso_h * 0.25;

// ---------- MECHANISM ----------
sg90_body_l        = 23.0;
sg90_body_w        = 12.2;
sg90_body_h        = 22.5;
// ---------- COMPONENTS (matched to STLs in hardware/components/) ----------
// MCU: ESP32-C3 Super Mini — 22 × 18 × 8 mm. Only MCU that fits 44 mm torso.
esp_w              = 22;
esp_l              = 18;
esp_h              = 8;
// I2S mic board (matches hardware/components/microphone.stl) — vertical orientation
mic_w              = 40;
mic_d              = 11;
mic_h              = 20;
// USB-C breakout (matches hardware/components/usbc.stl)
usbc_w             = 20;
usbc_d             = 10;
usbc_h             = 20;
shoulder_pin_d     = 2.5;
tendon_ch_d        = 2.0;

// ---------- RESOLUTION ----------
$fa = 2;
$fs = 0.5;
$fn_smooth         = 80;

// =====================================================================
//  HELPERS
// =====================================================================

module ovoid(w, d, h) {
    scale([w/2, d/2, h/2]) sphere(r=1, $fn=$fn_smooth);
}

module rounded_box(w, d, h, r=2) {
    hull() {
        for (x=[-1,1], y=[-1,1], z=[-1,1])
            translate([x*(w/2-r), y*(d/2-r), z*(h/2-r)]) sphere(r);
    }
}

module lozenge(w, h, t) {
    hull() {
        translate([-(w-h)/2, 0, 0]) cylinder(d=h, h=t);
        translate([ (w-h)/2, 0, 0]) cylinder(d=h, h=t);
    }
}

module tapered_limb(points) {
    hull() for (p = points)
        translate([0, 0, p[0]]) sphere(d=p[1], $fn=$fn_smooth);
}

// =====================================================================
//  HEAD
// =====================================================================

module head_solid() {
    union() {
        ovoid(head_w, head_d_front, head_h);
        translate([0, head_d_front*0.04, -head_h*0.40])
            scale([0.85, 0.85, 0.7]) sphere(d=head_w*0.65, $fn=$fn_smooth);
        translate([0, head_d_front*0.16, head_h*0.05])
            scale([1, 0.55, 0.35]) sphere(d=head_w*0.95, $fn=$fn_smooth);
        for (s=[-1,1]) translate([s*head_w/2, 0, head_h*0.04])
            scale([0.28, 1, 1]) sphere(d=9, $fn=$fn_smooth);
        translate([0, 0, -head_h/2 + 2]) cylinder(d=14, h=8);
    }
}

module head() {
    difference() {
        head_solid();
        translate([0, head_d_front/2 - face_recess_depth + 0.5, head_h*0.05])
            rotate([90,0,0]) scale([1, 0.65, 1])
                cylinder(d=26, h=face_recess_depth*2.5, center=true, $fn=$fn_smooth);
        translate([0, head_d_front/2 - face_recess_depth + 0.5, -head_h*0.12])
            rotate([90,0,0])
                cylinder(d=muzzle_d - 0.5, h=face_recess_depth*1.5, center=true);
        translate([-head_w/2 - 3, 0, head_h*0.04])
            rotate([0,90,0]) cylinder(d=2.5, h=head_w);
        translate([0,0,-head_h/2]) cylinder(d=10, h=12, center=true);
    }
}

module eye_board() {
    eyeboard_t = face_recess_depth + 0.8;
    difference() {
        lozenge(eyeboard_w, eyeboard_h, eyeboard_t);
        for (s=[-1,1]) translate([s*eye_spacing/2, 0, -0.1])
            cylinder(d=eye_d - 0.2, h=eyeboard_t + 0.2);
    }
}

module muzzle() {
    muzzle_t = face_recess_depth + 0.3;
    hull() {
        cylinder(d=muzzle_d, h=muzzle_t*0.6);
        translate([0,0,muzzle_t*0.7]) cylinder(d=muzzle_d*0.7, h=muzzle_t*0.4);
    }
}

// =====================================================================
//  TORSO
// =====================================================================

module torso_outer() {
    hull() {
        translate([0,0, torso_h*0.45]) ovoid(torso_w*0.85, torso_d*0.85, 3);
        translate([0,0, torso_h*0.20]) ovoid(torso_w*0.95, torso_d*0.95, 3);
        translate([0,0,-torso_h*0.10]) ovoid(torso_w*0.90, torso_d*0.95, 3);
        translate([0,0,-torso_h*0.45]) ovoid(torso_w*0.75, torso_d*0.80, 3);
        for (s=[-1,1]) translate([s*torso_w*0.48, 0, shoulder_local_z])
            sphere(d=14, $fn=$fn_smooth);
    }
}

module torso_cavity() {
    hull() {
        translate([0,0, torso_h*0.45 - wall]) ovoid(torso_w*0.85 - 2*wall, torso_d*0.85 - 2*wall, 2);
        translate([0,0, torso_h*0.20]) ovoid(torso_w*0.95 - 2*wall, torso_d*0.95 - 2*wall, 2);
        translate([0,0,-torso_h*0.10]) ovoid(torso_w*0.90 - 2*wall, torso_d*0.95 - 2*wall, 2);
        translate([0,0,-torso_h*0.45 + wall]) ovoid(torso_w*0.75 - 2*wall, torso_d*0.80 - 2*wall, 2);
    }
}

module torso_base() {
    difference() {
        torso_outer();
        torso_cavity();
        translate([0,0, torso_h/2 - 4]) cylinder(d=14 + fit_loose, h=10);
        for (s=[-1,1]) translate([s*torso_w*0.48, 0, shoulder_local_z])
            rotate([0,90,0]) cylinder(d=shoulder_pin_d, h=20, center=true);
        translate([0, 0, -torso_h/2 + 0.5])
            rounded_box(24, 20, 3, r=3);
        for (s=[-1,1]) translate([s*torso_w*0.20, 0, -torso_h/2 + 2])
            cylinder(d=10 + fit_loose, h=8, center=true);
        translate([0,0, torso_h/2 - 4]) cylinder(d=9, h=12);
        translate([0, 0, -torso_h/2 + 1])
            rounded_box(11, 6, 4, r=1.5);
    }
    for (s=[-1,1]) translate([s*torso_w*0.40, 0, shoulder_local_z])
        rotate([0,90,0]) difference() {
            cylinder(d=7, h=6, center=true);
            cylinder(d=shoulder_pin_d, h=8, center=true);
        }
}
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

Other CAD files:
stl/tys-aben-all-parts.stl
3d Model officemonkey.dk/stl/wall/arm_left.stl
Tys-aben-Print-Package/individual-parts/desktop/arm_left.stl
Tys-aben-Print-Package/individual-parts/wall/yoke.stl
3d Model officemonkey.dk/cad/monkey.scad
Tys-aben-Print-Package/individual-parts/desktop/arm_right.stl
Tys-aben-Print-Package/individual-parts/desktop/bottom_plate.stl
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

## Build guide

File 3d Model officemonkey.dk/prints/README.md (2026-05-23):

# prints/

Ready-to-slice Bambu Studio project file.

## `aben.3mf`

All 13 STL parts loaded onto two build plates with auto-arranged orientations. Open this file in Bambu Studio and you're ~3 clicks from sending to the printer.

### Quick steps

1. **Bambu Studio** → File → Open Project → `aben.3mf`
2. Top-right: confirm your printer model is selected (X1C / P1S / A1).
3. Top-left filament slots: load 3 filaments
   - Slot 1: light wood-fill PLA
   - Slot 2: dark wood-fill PLA  *(optional — used only for eye-board + muzzle)*
   - Slot 3: PETG black  *(optional — used only for yoke + servo bracket)*
4. Right-click each part → **Filament** → assign per the table in [`../hardware/PRINT.md`](../hardware/PRINT.md).
5. Apply slicer settings from `../hardware/PRINT.md` (or accept Bambu defaults for a generic first print).
6. Slice → Send to printer.

### Plate layouts (auto-arranged)

| Plate | Contents | Preview |
|---|---|---|
| 1 | head, torso_front, torso_back, arm_left, arm_right, leg_left, leg_right | [plate_1_preview.png](plate_1_preview.png) |
| 2 | base_disc, bottom_plate, eye_board, muzzle, yoke, servo_bracket | [plate_2_preview.png](plate_2_preview.png) |

You can re-arrange parts onto a single plate if you prefer (some legs/arms may need to be rotated vertical to fit — see [`../hardware/PRINT.md`](../hardware/PRINT.md) per-part orientation table).

### Important: verify per-part orientation before slicing

Auto-arrange optimizes for plate area, not for print quality. For best results check that:

- **Head** is chin-down on the bed (no support needed)
- **Arms** are standing vertically (shoulder end down) — layer lines run *along* the limb
- **Legs** are standing vertically (foot down) — same reason
- **Torso halves** are curved-seam side down — tree supports inside cavity only

If auto-arrange placed them on their sides, rotate manually before slicing.

### Regenerating this file

If you edit `cad/monkey.scad`:

```bash
# 1. Re-export STLs (see cad/README.md)
# 2. Regenerate the 3MF project:
"/Applications/BambuStudio.app/Contents/MacOS/BambuStudio" \
  --arrange 1 --orient 1 --allow-rotations \
  --outputdir "$(pwd)/prints" \
  --export-3mf "aben.3mf" \
  "$(pwd)"/stl/*.stl
```

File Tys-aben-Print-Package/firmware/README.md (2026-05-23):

# Firmware — Tys-aben V1.0

> Arduino-ESP32 sketch that drives the noise-detection → arm-motion loop.

## File

- [`tys-aben/tys-aben.ino`](tys-aben/tys-aben.ino) — single-file sketch, ~200 lines.
- **Compile-tested ✓** with arduino-cli + ESP32 Arduino core 3.3.8 (`esp32:esp32:esp32c3`). Program 312 KB (24% of 1.3 MB flash), RAM 15 KB (4% of 320 KB).

## Hardware connections

| Pin | Connects to | Notes |
|---|---|---|
| `I2S_SCK = 14` | Mic BCLK | I2S bit clock |
| `I2S_WS = 15` | Mic LRCL / WS | I2S word select |
| `I2S_SD = 32` | Mic DOUT | I2S serial data in |
| `SERVO_PIN = 18` | SG90 signal wire (orange) | PWM-driven |
| 5V | Mic VCC + servo V+ | both run on 5V |
| GND | Mic GND + servo GND | common ground |

Adjust pins at the top of `tys-aben.ino` to match your specific
ESP32 board variant.

## Build & upload

1. Install [Arduino IDE](https://www.arduino.cc/en/software).
2. Add ESP32 board support: File → Preferences → Additional Boards
   Manager URLs → add `https://espressif.github.io/arduino-esp32/package_esp32_index.json`
3. Tools → Board → ESP32 Arduino → select your specific board.
4. Open [`tys-aben/tys-aben.ino`](tys-aben/tys-aben.ino).
5. Adjust pins + tuning constants if needed.
6. Tools → Port → select your USB-C-connected board.
7. Upload (arrow icon in toolbar).
8. Tools → Serial Monitor → 115200 baud. Watch the dB readings.

## First-run tuning

The default `THRESHOLD_DB = 65.0` is a rough starting point and is
**not calibrated SPL**. The mic outputs raw I2S samples that get
log-converted to a dB-ish number — useful for relative comparison
but not absolute room SPL.

To tune:
1. Open Serial Monitor at 115200 baud.
2. Sit in a quiet room → note the baseline number (e.g. 35).
3. Have a normal conversation 1 m from the mic → note the value
   (e.g. 55).
4. Have someone speak loudly / two people in conversation →
   note the value (e.g. 70).
5. Set `THRESHOLD_DB` to ~5 above your "loud" baseline.
6. Re-upload.

## Tuning the servo positions

`SERVO_REST_US` and `SERVO_PEAK_US` determine where the arms sit at
rest and at peak. Defaults:
```
SERVO_REST_US = 1000   // arms hanging at rest
SERVO_PEAK_US = 1900   // arms cupping mouth
```

After physical assembly with tendons attached, you'll almost
certainly need to adjust these. Procedure:
1. With the monkey assembled but no power, manually verify the
   arms hang at rest with the servo horn pointing in the "0°"
   direction (5° forward of vertical).
2. Power on. Edit `SERVO_REST_US` until the arms sit naturally at
   rest with no tendon tension.
3. Force the trigger (clap loudly or temporarily set `THRESHOLD_DB
   = 30`) and watch the arms go to peak.
4. Edit `SERVO_PEAK_US` until the hands cup the mouth precisely.
5. Optional: set both arms' return-elastic tension to match so they
   hang symmetrically at rest.

## What firmware doesn't do (yet — V1.x candidates)

- WiFi configuration UI (currently constants in code)
- Calibrated SPL reading (requires reference mic + calibration step)
- Voice activity detection (currently any loud noise triggers)
- LED status indication (no LEDs in V1 hardware)
- OTA firmware updates
- dB logging / metrics dashboard

These are all explicitly out of scope for V1 — see
[`../product/plan.md`](../product/plan.md).

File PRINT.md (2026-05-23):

# PRINT.md — Aben on a Bambu Lab printer

> One-page guide. Open the project file, slice, print. Total time: ~21 hours of printing across 13 parts.

---

## Quick start

1. Open **Bambu Studio** → File → Open Project → [`prints/aben.3mf`](prints/aben.3mf).
2. Confirm your printer model (X1C / P1S / A1) is selected, top-right.
3. Load filaments (see [filament table](#filaments-3-colors) below).
4. Assign filaments per part (right-click → Filament).
5. Apply settings from [§ Bambu Studio profile](#bambu-studio-profile-paste-these-values).
6. Slice → Send to printer.

Plate layouts and per-plate part lists: see [`prints/README.md`](prints/README.md).

If you'd rather start from STLs, see [§ Manual setup](#manual-setup-without-the-3mf).

---

## Filaments (3 colors)

| Slot | Filament | Used for | Approx. need |
|---|---|---|---|
| **1. Light wood** | Bambu PLA Wood "Birch" / Polymaker PolyWood natural / ColorFabb WoodFill light | Body, head, arms, legs, bottom plate | ~250 g |
| **2. Dark wood** | Bambu PLA Wood "Walnut" / ColorFabb WoodFill darker | Eye-board, muzzle | ~5 g |
| **3. PETG black** | Bambu PETG-HF black | Yoke, servo bracket (hidden inside) | ~15 g |
| 4. *Optional contrast wood* | Medium wood-fill | Base disc (if you want a two-tone object) | ~40 g |

**Total filament: ~310 g.** Cheap. You can do it all in light wood if you don't have multiple filaments — face inserts in dark wood is purely cosmetic.

**Nozzle:** 0.4 mm **hardened steel** strongly recommended. Wood-fill PLA is abrasive; brass nozzles wear visibly within a few prints.

---

## Print in 3 phases (recommended — don't print everything at once)

**Phase 1 — Validate the mechanism (~1 h, ~10 g filament)**
- Print: `servo_bracket.stl`, `yoke.stl`, `bottom_plate.stl`
- Goal: fit-check the SG90 in the bracket and the yoke on its horn before committing to the rest of the print.

**Phase 2 — Validate the torso cavity (~5 h, ~80 g)**
- Print: `torso_front.stl`, `torso_back.stl`, `base_disc.stl`
- Goal: confirm the servo bracket fits inside the assembled torso, that the bottom plate seals magnetically, and that the monkey will stand stable on the base.

**Phase 3 — Finish the body (~15 h, ~220 g)**
- Print: `head.stl`, `arm_left.stl`, `arm_right.stl`, `leg_left.stl`, `leg_right.stl`, `eye_board.stl`, `muzzle.stl`
- Goal: complete the sculpture.

If Phase 1 or 2 reveals a fit issue, you adjust `monkey.scad`, re-export only the affected STLs, and re-print without having wasted 18 hours.

---

## Per-part settings

| Part | Filament | Orientation on bed | Supports | Layer height | Est. time |
|---|---|---|---|---|---|
| `head.stl` | Light wood | Chin-down (flat side of chin to bed) | None | 0.12 mm | ~3 h |
| `torso_front.stl` | Light wood | Curved-seam side down | Tree, inside cavity only | 0.12 mm | ~2 h |
| `torso_back.stl` | Light wood | Curved-seam side down | Tree, inside cavity only | 0.12 mm | ~2 h |
| `bottom_plate.stl` | Light wood | Flat (magnet pockets face up) | None | 0.16 mm | ~30 min |
| `arm_left.stl` | Light wood | Shoulder end **down** (arm standing vertically) | None | 0.12 mm | ~2 h |
| `arm_right.stl` | Light wood | Same | None | 0.12 mm | ~2 h |
| `leg_left.stl` | Light wood | Foot down (leg standing vertically) | Minimal — foot overhang | 0.12 mm | ~2.5 h |
| `leg_right.stl` | Light wood | Same | Same | 0.12 mm | ~2.5 h |
| `eye_board.stl` | Dark wood | Flat | None | 0.12 mm | ~10 min |
| `muzzle.stl` | Dark wood | Flat | None | 0.12 mm | ~5 min |
| `base_disc.stl` | Light or medium wood | Flat (USB notch facing right) | None | 0.16 mm | ~2 h |
| `yoke.stl` | PETG black | Flat | None | 0.16 mm | ~10 min |
| `servo_bracket.stl` | PETG black | Bracket-side down | Tree under cradle walls | 0.16 mm | ~30 min |

**Why limbs print vertically:** layer lines run *along* the limb. When you oil-finish wood-fill PLA, layer lines read as faux wood grain. Vertical grain on a vertical limb = correct.

---

## Bambu Studio profile (paste these values)

| Setting | Wood-fill PLA (body) | PETG (mechanism) |
|---|---|---|
| Printer | Bambu X1C / P1S / A1 | Same |
| Build plate | **Textured PEI** | Textured PEI |
| Layer height | 0.12 mm | 0.16 mm |
| First layer height | 0.20 mm | 0.20 mm |
| Wall loops | **4** | 3 |
| Top / bottom layers | 5 / 5 | 4 / 4 |
| Infill density | **15 %** | 30 % |
| Infill pattern | **Gyroid** | Gyroid |
| Print speed (outer wall) | **40 mm/s** | 80 mm/s |
| Print speed (inner wall / infill) | **60 mm/s** | 120 mm/s |
| Nozzle temp | 215 °C | 240 °C |
| Bed temp | 65 °C | 75 °C |
| Cooling fan | 60 % | 30 % (PETG hates over-cooling) |
| Retraction | 0.8 mm @ 30 mm/s | Filament default |
| Bed adhesion | Brim 4 mm (torso halves only) | Skirt |
| Pressure advance | Filament default | Filament default |

**Crucial wood-fill rule:** keep speed below **60 mm/s**. Wood-fill PLA clogs the nozzle if pushed faster — the wood fibres melt unevenly and jam.

---

## Post-processing (the quality lever)

This is where the print stops looking like a 3D print and starts looking like a wooden object. Skip this and you have a competent prototype. Do this and you have an object you want to keep on your desk.

1. **Sand** in stages: 240 → 400 → 600 grit, with the layer direction.
2. Wipe clean with a damp cloth, let dry fully.
3. **Apply boiled linseed oil** or Osmo Polyx Hardwax Oil — two thin coats, 24 h between.
4. Buff with a soft cloth between coats.

The wood fibres in wood-fill PLA absorb the oil and develop a real wood patina. The layer lines, post-oil, look like grain.

---

## Hardware bill of materials (for the assembled product, not the print itself)

| Item | Qty | Notes |
|---|---|---|
| ESP32-S3 dev board with USB-C | 1 | Any common variant |
| INMP441 or SPH0645 I2S microphone | 1 | Mounted at top of torso cavity |
| SG90 micro servo | 1 | Standard 9 g hobby servo |
| 6 mm black glass beads | 2 | Eyes — press-fit |
| 3 mm steel pins (40 mm long) | 2 | Shoulder pivots |
| 2 mm braided fishing line | 60 cm | Tendons |
| Light return spring or 2 mm sewing elastic | 20 cm | Arm return-to-rest |
| 5 × 2 mm neodymium magnets | 4 | Bottom plate retention |
| USB-C breakout board | 1 | Routed through bottom plate + base disc notch |

---

## Manual setup (without the 3MF)

If you'd rather build the print plate yourself:

1. Open Bambu Studio, select your printer.
2. File → Import → select all 13 `.stl` files from `stl/`.
3. Apply the orientations from the per-part table above (right-click → Lay flat, or use the rotate tool).
4. Apply the filament assignment: light wood for body parts, dark wood for eye_board + muzzle, PETG for yoke + servo_bracket.
5. Apply profile settings from the table above.
6. Arrange on the plate. (Tip: torso halves and base disc take the most room — arrange them first, fit everything else in the gaps. You may need 2 plates.)
7. Slice → review the preview → Send to printer.

---

## Troubleshooting

| Symptom | Cause | Fix |
|---|---|---|
| Wood-fill jams mid-print | Speed too high | Drop to 50 mm/s outer wall |
| Stringing on wood prints | Retraction too short for wood-fill | Retraction → 1.0 mm |
| Torso halves don't meet at seam | Print warp on tall thin walls | Increase brim to 6 mm; ensure bed is enclosed/heated |
| Arms snap at shoulder | Layer adhesion weak | Print arms vertically (shoulder down) — layer lines should run along the arm, not across it |
| Magnets don't seat in bottom plate | Hole slightly tight | Drill 5.2 mm pocket to 5.5 mm after print |
| SG90 doesn't fit in bracket | Tolerance variation | Sand bracket cradle walls; or edit `sg90_body_w/l` in `monkey.scad` +0.4 mm and re-export |

---

## Print order summary

```
Phase 1 (validate mechanism)        ~1 h
  └── servo_bracket, yoke, bottom_plate

Phase 2 (validate torso)            ~5 h
  └── torso_front, torso_back, base_disc

Phase 3 (finish body)               ~15 h
  └── head, arm_left, arm_right, leg_left, leg_right, eye_board, muzzle

TOTAL                              ~21 h / ~310 g filament
```

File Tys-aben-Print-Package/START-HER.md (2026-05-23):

# Tys-aben — Print Package

Alt du skal bruge for at printe og samle Tys-aben (den støj-reaktive abe der dækker sin egen mund).

---

## 1. Vælg variant

| Variant | Fil | Print-tid | Filament | Beskrivelse |
|---|---|---|---|---|
| **Wall (anbefalet)** | `tys-aben-wall-complete.stl` | ~6 timer | ~64 g | 125 mm høj, hænger på væg via keyhole. Inkluderer ekstern hub-boks. |
| **Desktop** | `tys-aben-desktop-complete.stl` | ~21 timer | ~167 g | 220 mm stående abe på rektangulær base 150×50 mm. |

**For office-deployment:** wall-varianten er bedst (per-zone, social signal hele rummet ser).
**For individual / executive desk:** desktop-varianten er bedst (premium look).

---

## 2. Print

1. Åbn én af `.stl`-filerne i **Bambu Studio** (eller PrusaSlicer / Cura)
2. Bekræft din printer-model (Bambu X1C / P1S / A1 fungerer alle)
3. Load filament:
   - **Lys wood-fill PLA** (Bambu Birch, Polymaker PolyWood Natural, ColorFabb WoodFill light)
   - **Mørk wood-fill PLA** (Bambu Walnut eller ColorFabb darker)
   - **PETG sort** valgfri til yoke + servo_bracket (PLA fungerer også i denne størrelse)
4. Højreklik hver del → Filament → tildel:
   - **Mørk**: `eye_board`, `muzzle`
   - **Sort (eller mørk)**: `yoke`, `servo_bracket`
   - **Lys**: alle øvrige
5. Læs [`PRINT-GUIDE.md`](PRINT-GUIDE.md) for præcise slicer-settings
6. **Slice → Send to printer**

**Vigtige settings:**
- Layer height: 0.12 mm (body), 0.16 mm (brackets)
- Walls: 4
- Infill: 15% gyroid
- Print speed: **max 60 mm/s** for wood-fill (vigtig — ellers jammer dysen)
- Nozzle: 0.4 mm hardened steel (wood-fill er abrasivt)

---

## 3. Hardware du skal købe / have klar

### Køb (kun ét)
- **1× SG90 micro servo** (~$2 Amazon/AliExpress)

### Du har (i Agent360-skuffe / dit forbrugeragent-projekt)
- I2S mikrofon-modul (~40 mm)
- USB-C breakout
- MCU motherboard (60×120 mm)

### Småhardware
| Item | Qty | Note |
|---|---|---|
| Sorte glasperler 6 mm (øjne) | 2 | Press-fit i eye_board |
| Stålpinde 3 mm × 40 mm (skuldre) | 2 | |
| Stålpinde 2 mm × 15 mm (albuer — kun wall V1.1) | 2 | Paperclip fungerer |
| Braided fishing line (tendoner) | 60 cm | |
| Sewing elastik 1.5 mm (kun wall V1.1) | 10 cm | Forearm return |
| Neodym-magneter 5 × 2 mm | 5 | 4 til hub-lid + 1 til bottom_plate |
| Vægskruer | 3 | 1 til monkey + 2 til hub |

---

## 4. Saml

Følg [`ASSEMBLY-GUIDE.md`](ASSEMBLY-GUIDE.md) trin-for-trin:

1. **Phase 1** — sand 240→400→600 grit + linolie (2 lag, 24t mellem)
2. **Phase 2** — sub-assemblies (hub interior, servo+yoke, 2-piece arme, mic-bracket)
3. **Phase 3** — body samling (elektronik → torso → arme → hoved → ben → luk)
4. **Phase 4** — vægmontering (monkey via keyhole + hub via 2 skruer)
5. **Phase 5** — firmware upload + tuning

Total samling-tid: ~3 timer arbejde + 48 timer finish-tørretid.

---

## 5. Firmware

Open Arduino IDE → install ESP32 board package → åbn [`firmware/tys-aben/tys-aben.ino`](firmware/tys-aben/tys-aben.ino) → upload.

Læs [`firmware/README.md`](firmware/README.md) for build-instruktioner + tuning af mic-threshold og servo-positioner.

---

## Filer i denne pakke

```
Tys-aben-Print-Package/
├── START-HER.md                       ← du er her
├── tys-aben-wall-complete.stl         ← print HER for wall (én fil, 17 parts)
├── tys-aben-desktop-complete.stl      ← print HER for desktop (én fil, 13 parts)
├── PRINT-GUIDE.md                     Bambu Studio settings + filament
├── ASSEMBLY-GUIDE.md                  Trin-for-trin samling
├── firmware/                          Arduino-ESP32 sketch
│   ├── tys-aben/tys-aben.ino          (compile-testet ✓)
│   └── README.md                      Build + tuning
├── individual-parts/                  Backup — alle parts som separate STL'er
│   ├── wall/                          (15 STLs — V1.1 med 2-piece arme + mic-bracket)
│   └── desktop/                       (13 STLs — V0.3 med rectangular base)
└── reference/
    └── peak-pose.png                  Visuelt mål — hånd-på-mund peak position
```

---

## Reference visuel

[`reference/peak-pose.png`](reference/peak-pose.png) — det her er hvad aben skal kunne lave når den er færdig: hænder kuppet over munden, øjnene kigger lige på dig over hænderne. Det er produktets pitch i ét billede.

---

## Hvis du sidder fast

- Slicer warning på `torso_front`: klik "Auto-repair model" (1 sek)
- Wood-fill jammer: drop print-speed til 50 mm/s
- Arms snapper ved albuen: tilføj en dråbe CA-lim ved hængslerne (assembly improvement)
- Servo virker ikke: check at den er SG90 (1.8 kg-cm torque), ikke en endnu mindre variant

---

**Caveat:** mekanikkens præcision af "hånd-på-mund" gestus kræver små justeringer af tendon-length ved samling (~5 min finkalibrering). Med Bojesen-quality finish (sand + linolie 2 gange) bliver det produkt-tier.

Hvis spørgsmål: hele projektet er på GitHub som **Agent360dk/monkey-office** (main branch, `3d Model officemonkey.dk/`-folder).

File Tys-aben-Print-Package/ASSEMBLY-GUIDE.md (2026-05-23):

# ASSEMBLY.md — Tys-aben Wall V1.1

Step-by-step physical assembly of the wall-mounted Tys-aben + external hub.

## What you need

### Printed (15 parts)
From [`../stl/wall/`](../stl/wall/):
- `head.stl`
- `eye_board.stl`
- `muzzle.stl`
- `torso_front.stl`
- `torso_back.stl`
- `bottom_plate.stl`
- `leg_left.stl`, `leg_right.stl`
- `upper_arm_left.stl`, `upper_arm_right.stl`
- `forearm_left.stl`, `forearm_right.stl`
- `yoke.stl`
- `servo_bracket.stl`
- `mic_bracket.stl`

From [`../stl/hub/`](../stl/hub/):
- `hub_box.stl`
- `hub_lid.stl`

### Electronics (you already have)
- Motherboard (60 × 7 × 120 mm) — lives in hub
- I2S microphone (40 × 11 × 20 mm) — lives in monkey torso
- USB-C breakout (20 × 10 × 20 mm) — lives in hub rear wall
- SG90 micro servo — to be purchased ($2)

### Mechanical hardware
| Item | Qty | Note |
|---|---|---|
| 5 × 2 mm neodymium magnets | 5 | 4 for hub lid + 1 for bottom plate |
| 3 mm steel pins, 40 mm long | 2 | shoulder pivots |
| 2 mm steel pins, 15 mm long | 2 | elbow hinges (paperclip works) |
| Braided fishing line | 60 cm | tendons |
| Sewing elastic, 1.5 mm | 10 cm | forearm-return spring |
| Wall screws | 3 | 1 for monkey keyhole, 2 for hub |
| 4-conductor wire | ~30 cm | mic I2S cable to hub |
| 3-conductor wire | ~30 cm | servo control to hub |

### Tools
- Soldering iron
- Small Phillips screwdriver
- Sandpaper 240 / 400 / 600 grit
- Boiled linseed oil OR Osmo Polyx
- Lint-free cloth

---

## Phase 1 — Surface finish (~1 hour active, 48 h cure)

This is what makes the print look like wood instead of plastic.

1. **Sand all visible parts** (head, torso halves, limbs, hub):
   - 240 grit first, sanding along the layer direction
   - then 400 grit
   - then 600 grit
2. **Wipe clean** with a damp cloth, let dry fully.
3. **Apply linseed oil**: thin coat with lint-free cloth.
4. Wait 24 h.
5. Buff with soft cloth, apply second coat.
6. Wait 24 h.
7. Buff to satin sheen.

Skip this and you have a competent prototype. Do this and you have
something you'd actually keep on a wall.

---

## Phase 2 — Sub-assemblies

### 2a. Hub interior
1. Solder USB-C breakout into the rear-wall cutout of `hub_box`.
   USB-C port faces outward.
2. Place motherboard flat in the bottom of the hub between the
   4 printed locator pegs. Loose-fit; gravity holds it.
3. Solder a 3-conductor wire (red, white, brown) from the motherboard's
   servo-control GPIO + 5V + GND to a 3-pin female header. Route the
   wire bundle up through the top cable inlet.
4. Solder a 4-conductor wire (VCC, GND, BCLK, LRCL, DOUT — actually
   5 conductors) from the motherboard's I2S pins. Same routing,
   up through the top cable inlet.
5. Push the 4 neodymium magnets into the lid-pockets on the hub_box's
   top rim. Press-fit only — no glue.
6. Set the hub_lid aside for final close-up.

### 2b. Servo + yoke + tendons
1. Press the `yoke.stl` onto the SG90 servo horn — friction fit, no glue
   yet (you may want to remove the horn to adjust angle later).
2. Tie a length of fishing line to one yoke arm. Set this aside —
   you'll route it through the torso next.

### 2c. Two-piece arm sub-assembly (do this for BOTH sides)

The key mechanism. Take your time.

1. **Route the tendon through upper_arm**: thread the free end of
   the fishing line into the bottom of `upper_arm_left.stl` (the
   shoulder ball end), feed it through the internal tendon channel,
   and pull it out at the elbow's front-face exit hole.
2. **Cross the elbow joint**: pull the tendon across the elbow gap
   into the tendon entry of `forearm_left.stl` (proximal end).
   Feed it down through the forearm's internal channel until it
   exits in the knot pocket.
3. **Tie a knot**: anchor the tendon with a secure knot inside the
   knot pocket. Trim the excess. The knot must be larger than the
   2 mm tendon channel so it can't pull back through.
4. **Pin the elbow**: slide the 2 mm steel pin (15 mm length) through
   the upper_arm's elbow knuckle and the forearm's proximal end.
   The forearm should swing freely on this pin.
5. **Install the return elastic**: thread a 10 cm length of 1.5 mm
   sewing elastic through the back-side anchor holes — through
   `upper_arm`'s back hole, across the back of the elbow joint,
   through `forearm`'s back hole. Pull just snug (not stretched)
   when the arm is straight. Tie off with a small knot at each end.
   This elastic pulls the forearm back to "straight" when the servo
   releases tendon tension.
6. **Repeat** for the right arm.

### 2d. Mic in bracket
1. Slide the mic board into the `mic_bracket.stl` — friction fit.
   The MEMS port (small hole on the mic chip) must face UP toward
   the bracket's sound-port hole.
2. Route the I2S wire from the mic out the wire passage at the
   bottom of the bracket.
3. Solder the wire to a 5-pin female header (or whatever connector
   matches the hub's I2S cable).

---

## Phase 3 — Body assembly

### 3a. Drop electronics into torso
1. Place the `servo_bracket.stl` inside the `torso_front.stl` half.
   It snaps into the printed ribs.
2. Drop the servo + yoke assembly into the bracket. Servo shaft
   points UP.
3. Slide `mic_bracket.stl` (with mic) into the upper section of the
   torso cavity. MEMS port faces up into the neck.
4. Route both tendons (from servo yoke arms) up the inside of the
   torso cavity and out through the shoulder pin holes — one to each
   side. Each tendon emerges through the inside of the upper_arm.
5. Bundle the mic + servo wires together. Route them down through
   the bottom of the torso (you'll thread them through the bottom
   plate next).

### 3b. Attach arms at shoulders
1. From OUTSIDE the torso, slide a 3 mm steel pin (40 mm length)
   through the upper_arm_left shoulder ball, through the torso's
   shoulder hole, and out the other side. The arm rotates around
   this pin.
2. Repeat for the right arm.
3. With the tendon coming from inside the torso through the shoulder
   pin axis, tie it off to the upper_arm's anchor inside the arm
   (use a small knot in the tendon channel).
4. Verify both arms hang freely at rest.

### 3c. Close the torso
1. Match `torso_back.stl` to `torso_front.stl` along the curved
   spine seam.
2. Apply a small bead of wood-glue along the seam (optional —
   friction-fit can be enough if your printer's tolerances are tight).
3. Press together. Wipe off any squeezed-out glue immediately.
4. Hold with rubber bands or clamps for 30 minutes.

### 3d. Attach head + face inserts
1. Press `head.stl` onto the torso's neck socket. Friction-fit
   first, then CA glue if you want it permanent.
2. Press the 2 black glass beads (6 mm) into the eye-board's eye
   holes. They should snap in.
3. Press-fit `eye_board.stl` into the upper face recess. The faint
   smile-line bow at center should be roughly aligned horizontally.
4. Press-fit `muzzle.stl` into the lower face recess just below
   the eye-board.

### 3e. Attach legs
1. Press `leg_left.stl` and `leg_right.stl` into the hip sockets.
   They should dangle freely — they're passive, not functional.

### 3f. Close the bottom
1. Route the wire bundle (mic + servo cables) through the 14 × 8 mm
   cable cutout in `bottom_plate.stl`.
2. Press the 5 × 2 mm neodymium magnet into the bottom_plate's
   magnet pocket (match polarity with the corresponding magnet
   already pressed into the torso's lower interior).
3. Snap the bottom_plate to the torso. It should hold magnetically.

---

## Phase 4 — Wall mounting

### 4a. Mount the monkey
1. Locate the wall position: eye-level for the typical seated person
   (~1.4 m from floor), centered on the area you want to monitor.
2. Drill a single hole, drive a screw with the head left protruding
   ~3 mm from the wall.
3. Hang the monkey on the screw via the keyhole on the torso's back.
   It should snap securely into place.

### 4b. Mount the hub
1. Position the hub ~5–10 cm below the monkey, so the cable bundle
   runs cleanly downward.
2. Drill 2 holes matching the hub's back-wall screw holes (24 mm
   apart, 4.5 mm diameter).
3. Drive the screws through the hub and into the wall.

### 4c. Connect cables
1. Plug the mic + servo wire bundle from the monkey into the
   matching connectors on the motherboard inside the hub.
2. Close the hub: place `hub_lid.stl` onto the hub_box. The 4
   magnets snap it shut.
3. Plug a USB-C cable into the hub's external port → wall outlet.

---

## Phase 5 — Firmware + tuning

See [`../firmware/README.md`](../firmware/README.md).

1. Connect a USB-C cable from the motherboard to your computer.
2. Upload [`../firmware/tys-aben.ino`](../firmware/tys-aben.ino).
3. Open Serial Monitor at 115200 baud.
4. Tune `THRESHOLD_DB` based on your room's baseline.
5. Tune `SERVO_REST_US` and `SERVO_PEAK_US` so the arms hang
   correctly at rest and the hands cup the mouth at peak.

The first power-on may need 5–10 minutes of trial-and-error tuning.
After that the monkey is a finished installation.

---

## Troubleshooting

| Symptom | Cause | Fix |
|---|---|---|
| Arms don't return to rest | Elastic too loose | Re-tie with more tension |
| Arms jam mid-motion | Forearm catches on upper-arm | File down the elbow clearance slot |
| Hands miss the mouth | Tendon length wrong | Adjust knot position in forearm pocket |
| Servo buzzes constantly at hold | Servo fighting against a hard stop | Lower `SERVO_PEAK_US` by 50 µs at a time |
| Mic doesn't respond | I2S wires swapped | Double-check BCLK/LRCL/DOUT mapping |
| Mic reads constant noise | Mic GND not connected | Verify continuity from mic GND to MCU GND |
| Monkey falls off wall | Screw too small | Use ≥ 4 mm screw with proper anchor |

---

## What "fully working" looks like

When everything's right, you should see:

1. Sit in a quiet room → Serial reads ~30–40 dB-ish, monkey idle.
2. Talk normally near the mic → dB rises to ~55, monkey still idle
   (below threshold).
3. Two people talk loudly at the same time → dB hits 65+, after
   800 ms the monkey's arms slowly rise (1.2 s) and cup the mouth.
4. People notice → quiet down → after 4 s minimum hold and noise
   drops below 59 dB (hysteresis), monkey lowers arms over 1.8 s.
5. 8 s cooldown — monkey won't re-trigger immediately.

That's the social signal loop.

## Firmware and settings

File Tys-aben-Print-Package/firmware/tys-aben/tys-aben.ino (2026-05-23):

/*
 * Tys-aben — Office Noise Reactor Firmware (V1.0)
 * =================================================================
 * Arduino-ESP32 sketch for the wall-mounted "shush monkey".
 *
 * Hardware (configurable below):
 *   - ESP32-class MCU (S3, C3, or original — adjust I2S pins)
 *   - I2S MEMS microphone (INMP441 / SPH0645 / similar)
 *   - SG90 micro servo (or compatible 5V hobby servo)
 *
 * What it does:
 *   1. Continuously samples ambient sound via I2S mic.
 *   2. Computes a smoothed RMS / dB-ish value.
 *   3. When sustained noise crosses THRESHOLD for DWELL_MS,
 *      drives the servo through a cosine-eased motion profile
 *      to raise the monkey's arms and cover its mouth.
 *   4. Holds while noise stays above (threshold − 6 dB hysteresis),
 *      minimum HOLD_MS, then eases back to rest.
 *   5. Cooldown COOLDOWN_MS between triggers — the monkey is a
 *      gentle social signal, not a meter.
 *
 * Build: open in Arduino IDE with ESP32 board package installed.
 * Select your specific ESP32 board, configure pins below, upload.
 */

#include <Arduino.h>
#include <driver/i2s.h>

// =====================================================================
//  CONFIGURATION — adjust to your board
// =====================================================================

// I2S microphone pins (INMP441 / SPH0645)
#define I2S_SCK     14   // bit clock (BCLK)
#define I2S_WS      15   // word select / LR clock (LRCL)
#define I2S_SD      32   // serial data (DOUT)
#define I2S_PORT    I2S_NUM_0

// Servo control (ESP32 Arduino 3.x LEDC API — pin-based, not channel-based)
#define SERVO_PIN          18
#define SERVO_PWM_FREQ     50      // 50 Hz standard hobby servo
#define SERVO_PWM_BITS     14      // 14-bit resolution → fine-grained motion
// SG90 pulse range: 500 µs (0°) to 2500 µs (180°), neutral 1500 µs.
// With 50 Hz period = 20 ms = 2^14 ticks ≈ 16384 ticks per 20 ms.
// 1 µs ≈ 0.82 ticks.
#define SERVO_REST_US     1000     // arms hanging at rest
#define SERVO_PEAK_US     1900     // arms cupping mouth (tune empirically)
#define SERVO_MIN_US       500
#define SERVO_MAX_US      2500

// Noise detection tuning
#define SAMPLE_RATE         16000   // Hz
#define SAMPLE_BLOCK_SIZE   512     // samples per RMS window
#define THRESHOLD_DB        65.0    // trigger above this (rough dB-ish)
#define HYSTERESIS_DB        6.0    // release threshold = THRESHOLD - HYSTERESIS
#define DWELL_MS            800     // sustained above-threshold required
#define HOLD_MS            4000     // minimum hold at peak
#define COOLDOWN_MS        8000     // minimum interval between triggers

// Motion timing (cosine-eased, never linear)
#define RAISE_MS           1200     // arms rising — gentle ascent
#define LOWER_MS           1800     // arms returning — slower, reluctant
#define MOTION_TICK_MS       20     // motion-loop update interval

// =====================================================================
//  STATE
// =====================================================================

enum State {
  S_IDLE,
  S_DWELL,        // noise above threshold, waiting to confirm sustained
  S_RAISING,      // mid-arc, arms rising
  S_HOLDING,      // arms cupping mouth, holding
  S_LOWERING,     // arms releasing
  S_COOLDOWN      // post-trigger lockout
};

State state = S_IDLE;
unsigned long state_start_ms = 0;
unsigned long last_above_threshold_ms = 0;
float current_servo_us = SERVO_REST_US;
float motion_start_us = SERVO_REST_US;
float motion_target_us = SERVO_REST_US;

// =====================================================================
//  I2S MIC INIT + READ
// =====================================================================

void i2s_init() {
  i2s_config_t cfg = {
    .mode                 = (i2s_mode_t)(I2S_MODE_MASTER | I2S_MODE_RX),
    .sample_rate          = SAMPLE_RATE,
    .bits_per_sample      = I2S_BITS_PER_SAMPLE_32BIT,
    .channel_format       = I2S_CHANNEL_FMT_ONLY_LEFT,
    .communication_format = I2S_COMM_FORMAT_STAND_I2S,
    .intr_alloc_flags     = ESP_INTR_FLAG_LEVEL1,
    .dma_buf_count        = 4,
    .dma_buf_len          = SAMPLE_BLOCK_SIZE,
    .use_apll             = false,
    .tx_desc_auto_clear   = false,
    .fixed_mclk           = 0
  };
  i2s_pin_config_t pins = {
    .bck_io_num   = I2S_SCK,
    .ws_io_num    = I2S_WS,
    .data_out_num = I2S_PIN_NO_CHANGE,
    .data_in_num  = I2S_SD
  };
  i2s_driver_install(I2S_PORT, &cfg, 0, NULL);
  i2s_set_pin(I2S_PORT, &pins);
  i2s_set_clk(I2S_PORT, SAMPLE_RATE, I2S_BITS_PER_SAMPLE_32BIT, I2S_CHANNEL_MONO);
}

// Read a block of samples, return dB-ish value (rough — not calibrated SPL).
float read_db_ish() {
  static int32_t samples[SAMPLE_BLOCK_SIZE];
  size_t bytes_read = 0;
  i2s_read(I2S_PORT, samples, sizeof(samples), &bytes_read, portMAX_DELAY);
  int n = bytes_read / 4;
  if (n == 0) return -100.0;

  // Sum of squares
  double sumsq = 0.0;
  for (int i = 0; i < n; ++i) {
    // INMP441 outputs 24-bit data left-aligned in 32-bit word
    int32_t s = samples[i] >> 14;   // bring down to manageable range
    sumsq += (double)s * (double)s;
  }
  double rms = sqrt(sumsq / n);
  // Rough dB conversion — calibrate with known reference for absolute SPL.
  // Reference 1.0 = noise floor; log10 scale.
  if (rms < 1.0) rms = 1.0;
  return 20.0 * log10(rms);
}

// =====================================================================
//  SERVO
// =====================================================================

// Forward declaration so servo_init() can call servo_write_us()
void servo_write_us(float us);

void servo_init() {
  // ESP32 Arduino 3.x LEDC API: ledcAttach(pin, freq, bits) — pin-based.
  ledcAttach(SERVO_PIN, SERVO_PWM_FREQ, SERVO_PWM_BITS);
  servo_write_us(SERVO_REST_US);
}

void servo_write_us(float us) {
  us = constrain(us, (float)SERVO_MIN_US, (float)SERVO_MAX_US);
  // duty (in PWM ticks) = us / period_us * 2^bits
  // period = 1e6/50 = 20000 µs; 2^14 = 16384
  uint32_t duty = (uint32_t)(us * 16384.0 / 20000.0);
  ledcWrite(SERVO_PIN, duty);
}

// Cosine ease in/out — 0..1 maps to 0..1, but with smooth ends.
float cosine_ease(float t) {
  if (t <= 0.0) return 0.0;
  if (t >= 1.0) return 1.0;
  return 0.5 - 0.5 * cosf(PI * t);
}

void update_motion(float duration_ms) {
  unsigned long now = millis();
  float t = (float)(now - state_start_ms) / duration_ms;
  if (t >= 1.0) t = 1.0;
  float eased = cosine_ease(t);
  current_servo_us = motion_start_us + (motion_target_us - motion_start_us) * eased;
  servo_write_us(current_servo_us);
}

void start_motion(float to_us, float duration_ms) {
  motion_start_us = current_servo_us;
  motion_target_us = to_us;
  state_start_ms = millis();
}

// =====================================================================
//  STATE MACHINE
// =====================================================================

void enter_state(State new_state) {
  state = new_state;
  state_start_ms = millis();
}

void loop_state_machine(float db_now) {
  unsigned long now = millis();
  bool above = (db_now > THRESHOLD_DB);
  bool above_release = (db_now > (THRESHOLD_DB - HYSTERESIS_DB));
  if (above) last_above_threshold_ms = now;

  switch (state) {
    case S_IDLE:
      if (above) enter_state(S_DWELL);
      break;

    case S_DWELL:
      if (!above) { enter_state(S_IDLE); break; }
      if (now - state_start_ms >= DWELL_MS) {
        // Triggered — begin raising arms
        start_motion(SERVO_PEAK_US, RAISE_MS);
        enter_state(S_RAISING);
      }
      break;

    case S_RAISING:
      update_motion(RAISE_MS);
      if (now - state_start_ms >= RAISE_MS) {
        enter_state(S_HOLDING);
      }
      break;

    case S_HOLDING: {
      // Maintain servo at peak
      servo_write_us(SERVO_PEAK_US);
      bool min_hold_met = (now - state_start_ms >= HOLD_MS);
      bool noise_gone = (now - last_above_threshold_ms > 500);
      if (min_hold_met && noise_gone && !above_release) {
        start_motion(SERVO_REST_US, LOWER_MS);
        enter_state(S_LOWERING);
      }
      break;
    }

    case S_LOWERING:
      update_motion(LOWER_MS);
      if (now - state_start_ms >= LOWER_MS) {
        enter_state(S_COOLDOWN);
      }
      break;

    case S_COOLDOWN:
      servo_write_us(SERVO_REST_US);
      if (now - state_start_ms >= COOLDOWN_MS) {
        enter_state(S_IDLE);
      }
      break;
  }
}

// =====================================================================
//  ARDUINO ENTRY POINTS
// =====================================================================

void setup() {
  Serial.begin(115200);
  delay(200);
  Serial.println("Tys-aben firmware booting…");
  i2s_init();
  servo_init();
  Serial.println("Ready. Listening for noise events.");
}

void loop() {
  float db = read_db_ish();

  // Debug stream — comment out for production
  static unsigned long last_print = 0;
  if (millis() - last_print > 200) {
    Serial.printf("dB: %5.1f  state: %d\n", db, (int)state);
    last_print = millis();
  }

  loop_state_machine(db);
  delay(MOTION_TICK_MS);
}

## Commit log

2026-05-23 Add initial Monkey office noise-reactor product plan
    Simple V1 brief for a 3D-printed ESP32-based monkey that reacts when
    office noise spikes. Plan is intentionally light, with explicit open
    questions (reaction type, voice-input interpretation, mic model) for
    the dev taking over to decide.
2026-05-23 Add V1 industrial design brief (Bojesen-tribute monkey)
    220mm seated monkey, single-servo tendon-driven shoulders, wood-fill
    PLA two-tone with linseed-oil finish. Brief leads with three design
    rules ("line should smile" / hide the machine / motion as gesture)
    and a Scandi-quality acceptance checklist. Open questions retained
    for return-mechanism, eye-board geometry, hand shape, and V1.1 audio.
2026-05-23 Add V0 print-ready parametric model + STL kit (11 parts)
    cad/monkey.scad parametric source; edit dimensions at top, regenerate
    any part via `-D part="..."` flag.
    stl/*.stl 11 pre-exported STLs (head, eye_board, muzzle, torso
    front/back, arms, legs, yoke, servo_bracket).
    cad/README.md slicer settings, wood-fill finishing process, assembly
    order, known V0 limitations.
    Honest V0 scope: proportions, mechanism mounts, and assembly are correct
    and printable. Bojesen-quality organic surfacing is out of scope for pure
    parametric primitives — README documents the path to a sculpted final body.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
    [arm_left.stl, arm_right.stl, eye_board.stl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]
2026-05-23 V0.2: simpler, more beautiful — organic forms, single-piece arms
    Replaces V0 primitive geometry with hull-of-spheres organic taper on
    every limb and the head. Same 11 parts, same mechanism, but each part
    now looks like a designed object instead of a stack of cylinders.
    * Head: ovoid with brow-forward bulge and soft chin transition
    (no flat cut on the bottom)
    * Arms: single-piece (simpler than 2-piece elastic), organic taper
    with bicep, narrower forearm, hand bulb
    * Legs: tapered thigh, sculpted knee, tapered shin, foot bulb
    * Torso: curved seam (large cylinder cut, near-invisible from front/back),
    organic egg silhouette
    * Mic port relocated behind one vestigial ear — invisible fro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
    [arm_left.stl, arm_right.stl, eye_board.stl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]
2026-05-23 Add honest design critique — what V0.2 needs to reach Bojesen-tier
    Names the 7 gaps between current parametric output and generational
    Scandinavian design (no intentionality, clip-on limbs, sphere-hands,
    blank face, wrong pose, short arms, visible tech). Proposes 10
    prioritized moves with effort/impact ranking; recommends 5 of them
    (stand up, arms to 135mm, flowing shoulder, wooden base disc, alert
    posture) as V0.3 scope — all parametric, no new complexity.
2026-05-23 V0.3: standing pose, Bojesen-long arms, flowing shoulder, base disc
    Implements moves 1, 2, 3, 6, 7 from design-critique.md:
    * Standing pose — straight legs, feet on a wooden base disc
    * Arms lengthened from 110→130 mm (59% of total height) — the
    signature Bojesen long-arm proportion
    * Flowing shoulder — torso swells outward at shoulder via hull(),
    no clip-on look at the shoulder junction
    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
    [arm_left.stl, arm_right.stl, base_disc.stl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]
2026-05-23 Add research on noise effects in open plan offices
    Document research findings on the impact of noise in open-plan offices, including effects on productivity, interruptions, and insights for product design.
2026-05-23 Add print-ready Bambu Studio project (.3mf) + comprehensive PRINT.md
    prints/aben.3mf — Bambu Studio project with all 13 parts auto-arranged
    onto 2 plates. Open in Bambu Studio, assign filaments,
    slice, send to printer.
    prints/README.md — quick-start guide for the .3mf
    prints/plate_*.png — auto-generated plate previews
    PRINT.md — comprehensive print guide at repo root:
    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
    [aben.3mf]
2026-05-23 cad monkeys
    [monkey.stl]
2026-05-23 Add 3d Model officemonkey.dk/ — complete Tys-aben V1.1 deliverable
    Full V1.1 wall-variant build package, ready for print + assembly.
    Contents (61 MB):
    - README.md — overview + start-here links
    - product/ — business plan, research, USPs, sales strategy
    - design/ — Bojesen-tribute design brief, critique, image-spec,
    cad.atech.dev prompt, renders (hero + peak + mesh)
    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
    [aben-wall.3mf, aben.3mf, arm_left.stl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]
2026-05-23 Add tys-aben-all-parts.stl — all 17 parts on one print plate
    Single STL containing all 17 components (15 wall monkey + 2 hub)
    arranged on a 256×256 mm build plate, ready for one-shot print on
    Bambu Lab P1S / X1C.
    Layout:
    Top half (y>0): hub_box + hub_lid (75×150 each, side by side)
    Middle row (y≈-35): head + torso_front + torso_back
    Lower row (y≈-65): 4 limb-parts (upper_arm_l/r + forearm_l/r)
    + 2 legs
    Bottom edge (y≈-90): 6 small parts (eye_board, muzzle, bottom_plate,
    yoke, servo_bracket, mic_bracket)
    All parts:
    - Touch the build plate (z_min = 0)
    - Are spaced ≥6 mm apart for brim clearance
    - Stay within 5 mm of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
    [tys-aben-all-parts.stl]
2026-05-23 ALT klar til print — both variants now have single-file print outputs
    User asked: "Sørg for ALT er der klar til send og print"
    → Both Tys-aben variants now have single-file STL print packages.
    NEW FILES:
    • tys-aben-wall-complete.stl (renamed from tys-aben-all-parts.stl)
    - Wall V1.1, 17 parts (15 monkey + 2 hub)
    - 229.5 × 220.5 × 54.5 mm — fits 256×256 Bambu plate
    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
    [tys-aben-desktop-complete.stl, tys-aben-wall-complete.stl]
2026-05-23 Add Tys-aben-Print-Package/ — self-contained print pack at repo root
    Self-contained folder with everything needed to print + assemble,
    mirroring ~/Downloads/Tys-aben-Print-Package/ structure.
    Easy to clone, easy to share, easy to send to a print shop.
    Contents (45 MB):
    • START-HER.md ← Danish quick-start guide
    • tys-aben-wall-complete.stl ← print this (wall, ~6h)
    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
    [arm_left.stl, arm_right.stl, base_disc.stl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]
